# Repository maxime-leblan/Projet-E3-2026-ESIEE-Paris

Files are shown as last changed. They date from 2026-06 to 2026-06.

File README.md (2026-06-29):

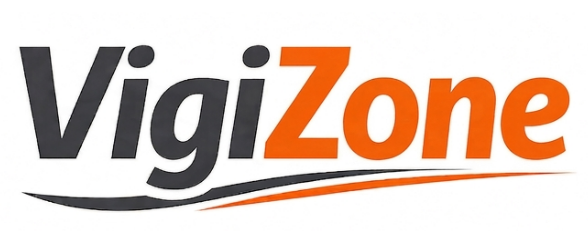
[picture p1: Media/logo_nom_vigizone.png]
Logo du projet VigiZone


# VigiZone : Prévention des collisions engins-piétons sur chantiers

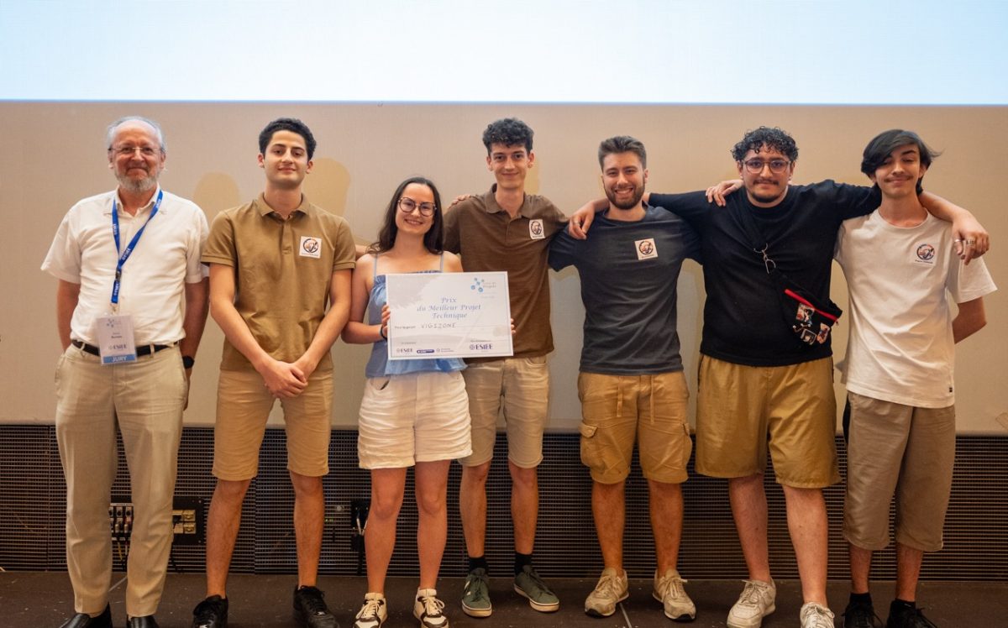
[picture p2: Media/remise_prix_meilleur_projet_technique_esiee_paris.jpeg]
L'équipe VigiZone lors de la remise du prix

*Remise du prix du meilleur projet technique lors du [Jour des Projets](https://jdp.esiee.fr) E3 2026 à ESIEE Paris*

### Membres de l'équipe

Nous étions une équipe de 6 étudiants en 1ère année du cycle ingénieur à ESIEE Paris
*dans l'ordre de droite à gauche :*
* Hugues JOUHAUD
* Naïm BEN-RAÏES
* Benoît DE KEYN
* Maxime LE BLAN
* Clarisse BLONDEL
* Jérémy FOUILLOUX

 Suivis par notre tutrice **Mme Ting WANG**, assistante professeur de robotique à ESIEE PARIS, nous avons reçu le prix du meilleur projet technique de la part du jury technique **M. Denis BUREAU** (tout à gauche sur la photo), professeur d'informatique à ESIEE Paris.

**[Lire le rapport complet du projet VigiZone (PDF)](https://drive.google.com/uc?export=download&id=16rXCA4nlOrGEzkfiPZYJjSept83bqB7f)**

---

## Contexte : Un enjeu de sécurité vital

Le secteur du Bâtiment et des Travaux Publics (BTP) fait face à des risques majeurs concernant la sécurité de ses travailleurs.
* Les collisions entre les engins de chantier et les ouvriers piétons représentent la première cause d'accidents mortels dans ce domaine.
* Selon l'Organisme Professionnel de Prévention du Bâtiment et des Travaux Publics (OPPBTP), on dénombre environ quinze décès par an causés par ces collisions.

Initialement, notre équipe souhaitait développer un dispositif pour les travailleurs isolés. Cependant, des échanges avec Monsieur Luc-Géry Helle, directeur régional génie civil de GTM Ouest (VINCI Construction France), ont mis en lumière une contrainte réglementaire stricte : la législation française interdit ou encadre très fortement le travail isolé sur les chantiers de construction. Le projet a donc été réorienté pour répondre au besoin critique de la prévention des collisions.

---

## Qu'est-ce que VigiZone ?

VigiZone est un système embarqué de détection en temps réel conçu pour éviter les collisions entre les ouvriers et les véhicules de chantier. 

Face à ce danger, les systèmes d'alarme sonores classiques (comme les bips de recul) perdent en efficacité, car les ouvriers s'habituent au bruit ambiant. De leur côté, les solutions basées sur des caméras IA ou des capteurs LiDAR sont extrêmement coûteuses et voient leurs performances chuter dans des conditions difficiles (poussière, boue, faible luminosité). 

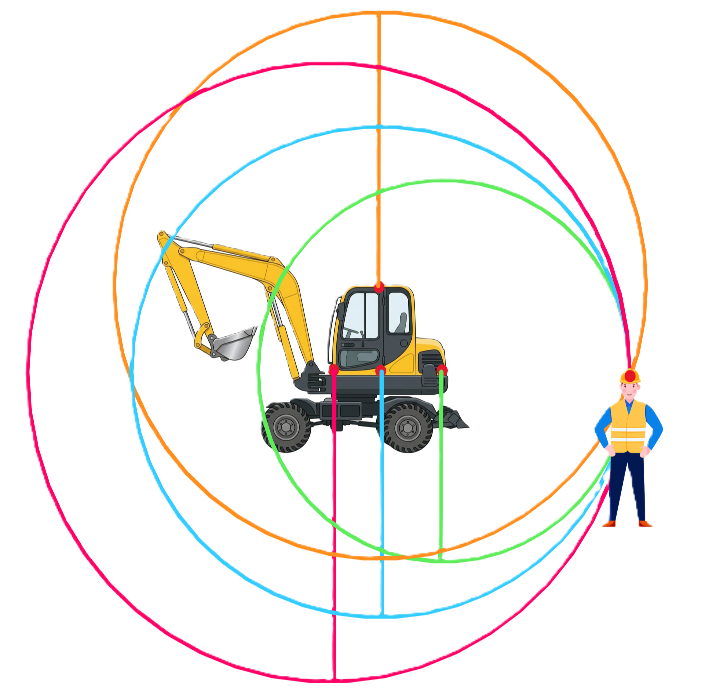
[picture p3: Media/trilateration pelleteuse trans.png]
Schéma de trilatération autour d'une pelleteuse


C'est pourquoi VigiZone s'appuie sur la technologie **Ultra Wide Band (UWB)** :
* L'UWB offre une très haute précision de positionnement en se basant sur le temps de vol du signal.
* C'est un signal robuste capable de bien traverser les obstacles.

---

## Architecture et Utilisation

Le fonctionnement de VigiZone repose sur la communication entre trois sous-systèmes interdépendants :

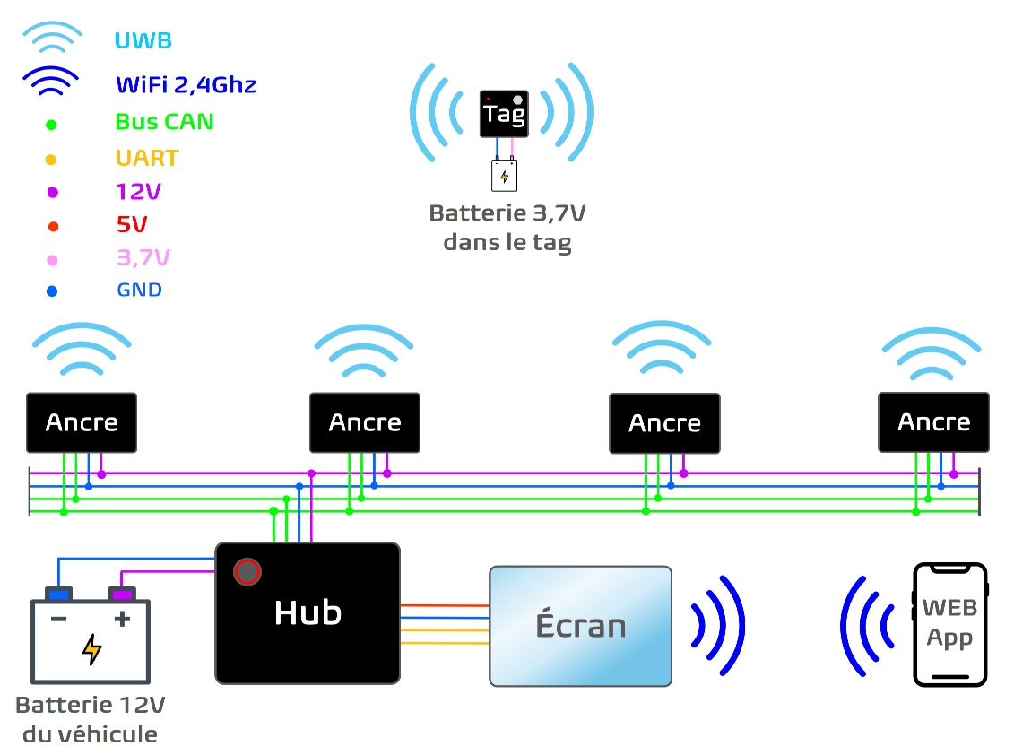
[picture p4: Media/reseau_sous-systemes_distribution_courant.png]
Architecture et distribution du courant


* **Le Hub central (Unité de bord) :** Placé dans la cabine du conducteur et alimenté par la batterie de l'engin, il fusionne les données pour calculer les distances par trilatération. 
  
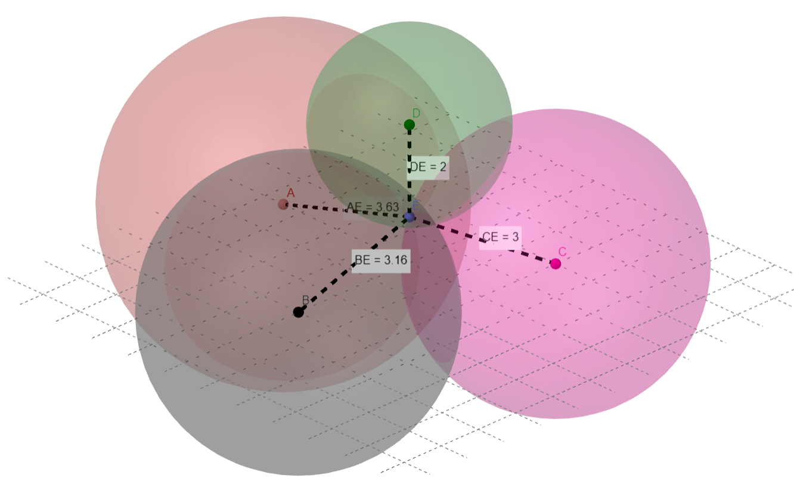
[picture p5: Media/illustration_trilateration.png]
Illustration de la trilatération
  
  
  Il est équipé d'un écran permettant de localiser les ouvriers en direct par rapport à une zone de danger et d'une alarme sonore.

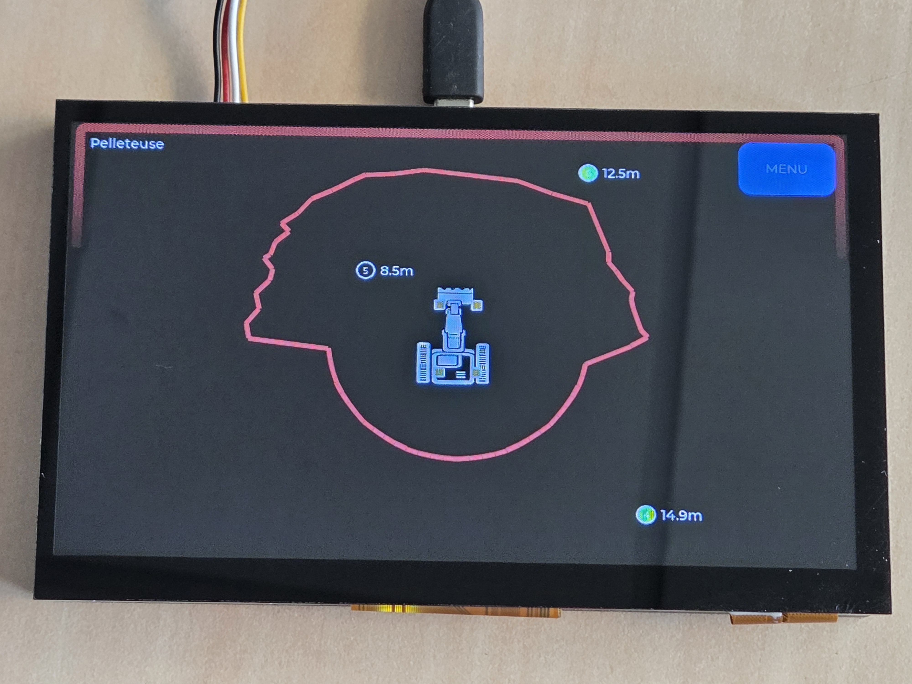
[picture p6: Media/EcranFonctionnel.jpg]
Écran fonctionnel VigiZone
  

* **Les Ancres (Boîtiers véhicule) :** Quatre capteurs disposés sur l'armature de l'engin (par exemple, aimantés) qui servent à localiser les ouvriers.
* **Le Tag (Boîtier ouvrier) :** Un équipement de protection individuelle (EPI) compact porté par l'ouvrier (sur son casque ou à la ceinture). Afin de garantir la sécurité, il ne possède aucun bouton d'arrêt et s'allume automatiquement.

**Scénario d'utilisation :** Si un ouvrier équipé d'un Tag pénètre dans une zone de danger virtuelle délimitée autour de l'engin, le système alerte instantanément les deux parties. Le conducteur est averti par l'écran et une alarme en cabine, tandis que le Tag de l'ouvrier déclenche une alerte sonore suffisamment puissante pour couvrir le bruit du chantier.

---

## Limites et Nuances du Système

Bien que la technologie UWB apporte une grande fiabilité de détection, notre solution technique ne prétend pas résoudre entièrement le problème des accidents. 

Comme nous l'a expliqué Monsieur Mathieu Baré, directeur prévention délégation génie civil Ouest chez VINCI Construction France, lors de notre visite sur le chantier du Grand Paris Express : plusieurs dispositifs de prévention existent, mais chacun possède ses avantages et ses limites selon les situations. À ce jour, aucun système ne permet de supprimer complètement le risque de collision entre engins et piétons. VigiZone doit donc être perçu comme un outil d'assistance et une couche de sécurité supplémentaire, qui vient compléter, mais en aucun cas remplacer, la vigilance indispensable des conducteurs et des ouvriers.

---

## En savoir plus

Pour consulter l'intégralité de notre démarche (choix technologiques, algorithmes de trilatération, conception des cartes sous KiCad et analyse éthique), nous vous invitons à lire notre rapport complet.

**[Lire le rapport complet du projet VigiZone (PDF)](https://drive.google.com/uc?export=download&id=16rXCA4nlOrGEzkfiPZYJjSept83bqB7f)**

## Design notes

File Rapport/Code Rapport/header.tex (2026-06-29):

\usepackage[french]{babel}

% --- Gestion des couleurs ---
\usepackage{xcolor}
% Définition d'un bleu élégant similaire à ton image
\definecolor{TableOfContentColor}{RGB}{0, 51, 153} 

% Gestion du style de certaines parties du texte
\usepackage{titlesec}

% --- Gestion des liens et de la couleur du sommaire ---
\usepackage[
    colorlinks=true,
    linkcolor=TableOfContentColor,    % Colore les titres et numéros de la table des matières
    urlcolor=TableOfContentColor,
    citecolor=TableOfContentColor
]{hyperref}

% Encodage des caractères
\usepackage[utf8]{inputenc}
\usepackage{lmodern}
\usepackage[T1]{fontenc}

%  Gestion de la mise en page et des marges :
\usepackage{geometry}
\geometry{a4paper}

% Pour afficher dans le sommaire jusqu'aux sous-sous-sections (ex: 1.1.1)
\setcounter{tocdepth}{3}
\setcounter{secnumdepth}{3}

% Pour gérer les soulignements qui vont automatiquement à la ligne en cas de débordement de la marge
\usepackage[normalem]{ulem}

%Choix du thème de la police (sans serif, petites capitales dans les titres...) 
\usepackage{amssymb} 
% Des symboles mathématiques
\usepackage{graphicx}
% Pour insérer des images
\usepackage{multicol}
% Pour gérer facilement un environnement à n colonnes
\usepackage{booktabs}
% Pour des beaux tableaux
\usepackage{esvect} 
% Pour de belles flèches sur les vecteurs
\usepackage{esdiff}
% Pour de beaux symboles de dérivation
\usepackage{siunitx}
% Pour l'utilisation des unités du système international
\sisetup{output-decimal-marker={,},inter-unit-product=\ensuremath{{}\cdot{}}}
% Quelques réglages pour l'affichage des unités

% Pour régler les marges de l'article
\usepackage{geometry}
\geometry{hmargin=2cm,vmargin=1.7cm}
% Pour les couleurs
\usepackage{color}
% Pour les indentations
\usepackage{tcolorbox}
\tcbuselibrary{skins, breakable}
\newtcolorbox{indentation}[1][]{
	blanker, left=1cm, borderline west={0.5mm}{0.6cm}{black!50}, breakable,
	before skip=2ex plus 0.1ex, after skip=2ex plus 0.1ex, #1
}

% On force les titres à rester en Noir, avec leur police par défaut (rmfamily), en gras
\titleformat{\section}{\normalfont\Large\bfseries\color{black}}{\thesection}{1em}{}
\titleformat{\subsection}{\normalfont\large\bfseries\color{black}}{\thesubsection}{1em}{}
\titleformat{\subsubsection}{\normalfont\normalsize\bfseries\color{black}}{\thesubsubsection}{1em}{}

% On définit la taille des marges
\geometry{inner=1.25cm, outer=1.25cm, top=2cm, bottom=2cm}

% ---- COMMANDES PERSONNALISEES ----

% Commande pour utiliser une indentation :
% \begin{indentation}
%     <texte>
% \end{indentation}

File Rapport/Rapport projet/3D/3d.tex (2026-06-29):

\subsection{Objectifs et contraintes initiales}

La conception d'une enveloppe physique pour protéger nos cartes électroniques constituait une étape essentielle de notre projet. En effet, nos cartes ne pouvaient pas rester simplement à l'air libre. L'objectif était de créer un boîtier sur mesure, imprimable en 3D, capable d'accueillir notre circuit imprimé tout en l'isolant efficacement des éléments extérieurs tels que la poussière, la pluie ou les gravats, et en laissant un accès aux connectiques.

Cependant, cette phase comportait une contrainte : nous étions dans l'obligation d'attendre la fin de la conception du PCB sous KiCad \cite{KiCad}. En effet, la moindre modification du placement des composants ou des trous de fixation sur la carte avait un impact direct sur la géométrie de notre futur boîtier. Il en allait de même pour la taille et la hauteur des composants, pour lesquelles nous devions consulter les datasheets et effectuer des mesures manuelles précises afin d'obtenir l'espacement le plus optimisé possible.

\subsection{Découverte de l'outil et problématiques de prise en main}

Pour réaliser cette modélisation, nous avons choisi d'utiliser le logiciel Autodesk Fusion 360 \cite{Fusion360}. La modélisation 3D était une étape relativement nouvelle pour nous, car personne n'avait d'expérience préalable dans ce domaine. 
La prise en main du logiciel s'est avérée complexe. Face au peu de tutoriels disponibles pour nous accompagner spécifiquement sur l'intégration d'une carte électronique dans un boîtier imprimable, nous avons procédé par itération. Nous avons donc décidé de réaliser une "boîte test" pour commencer. Ce premier essai nous a permis de comprendre le fonctionnement de l'espace de travail, la gestion de l'historique de conception, et l'utilisation des outils de base tels que les esquisses 2D et les extrusions.

Afin de valider nos dimensions et de confronter notre modèle à la réalité, nous avons procédé à l'impression de ce premier prototype. Cette étape n'a pas été réalisée avec du matériel personnel, mais directement au sein de l'école : nous avons utilisé les imprimantes 3D mises à notre disposition par l'association étudiante ESIEESPACE.

\subsection{Schéma général de conception : La méthode "Top-Down"}
Une fois familiarisés avec Fusion 360 \cite{Fusion360}, nous avons pu mettre en place une méthodologie plus rigoureuse appelée conception "Top-Down". Au lieu de modéliser le boîtier à l'aveugle, nous avons importé le modèle 3D de notre carte électronique (le fichier .STEP généré par KiCad \cite{KiCad}) directement au centre de notre espace de travail. Cette première étape, visible sur la Figure \ref{fig:-photo_carte_fusion360}, nous a permis de disposer d'une base visuelle concrète et à l'échelle pour construire le reste du boîtier.

\begin{figure}[!ht]
\centering 
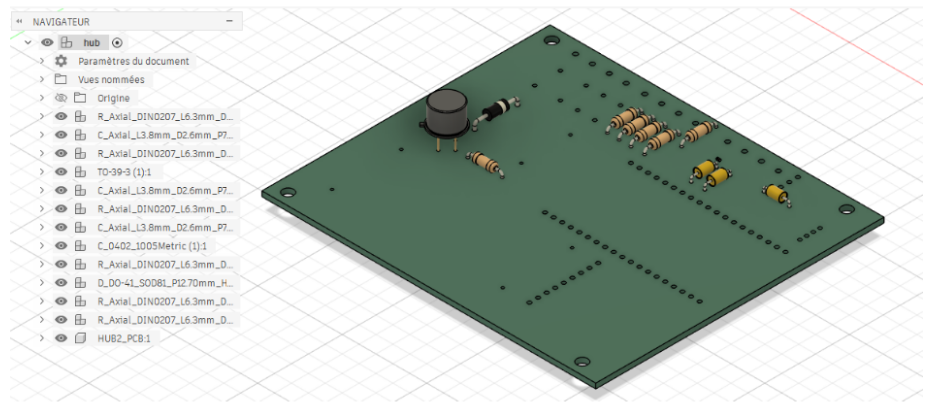
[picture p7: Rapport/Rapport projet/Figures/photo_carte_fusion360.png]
 
\caption[Modèle 3D de la carte électronique importé sous Fusion 360]{Modèle 3D de la carte électronique importé sous Fusion 360}
\label{fig:-photo_carte_fusion360}
\end{figure}

Voici les fonctions clés que nous avons utilisées pour construire le boîtier autour d'elle :

\begin{itemize}
    \item \textbf{L'outil Projeter (Raccourci P) :} Cet outil a été fondamental dans notre conception. Il nous a permis de "calquer" le contour exact de la carte électronique sur le fond ou le couvercle de notre boîtier. Cela nous a permis de garantir que les trous de fixation pour les vis soient positionnés au millimètre près pour l’assemblage et l'impression 3D. La Figure \ref{fig:-photo_projection_fusion360} illustre l'utilisation de cette fonction pour récupérer l'empreinte exacte d'un perçage de la carte vers la face de notre boîtier.
    
    \begin{figure}[!ht]
    \centering 
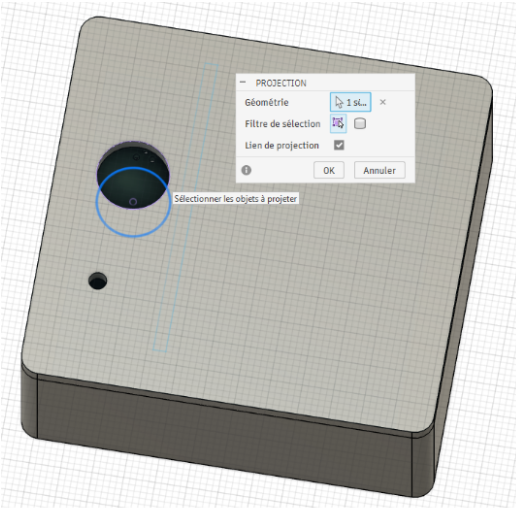
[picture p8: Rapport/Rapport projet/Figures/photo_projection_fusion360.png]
     
    \caption[Utilisation de l'outil Projeter pour définir l'emplacement exact des perçages]{Utilisation de l'outil Projeter pour définir l'emplacement exact des perçages}
    \label{fig:-photo_projection_fusion360}
    \end{figure}
    
    \item \textbf{L'outil Décalage (Offset) :} À partir du contour projeté, nous avons défini l'épaisseur des murs extérieurs. Nous avons opté pour une épaisseur de 2,5 mm. Cette valeur a été choisie en fonction des recherches que nous avons effectuées sur le rechargement sans fil, mais aussi sur les caractéristiques techniques des imprimantes 3D qui étaient à notre disposition. Le résultat de cette modélisation, regroupant les pylônes de fixation creusés, l'emplacement de la carte et les différentes ouvertures sur le couvercle, est présenté sur la Figure \ref{fig:-photo_boitier_fini_fusion360}.
    
    \begin{figure}[!ht]
    \centering 
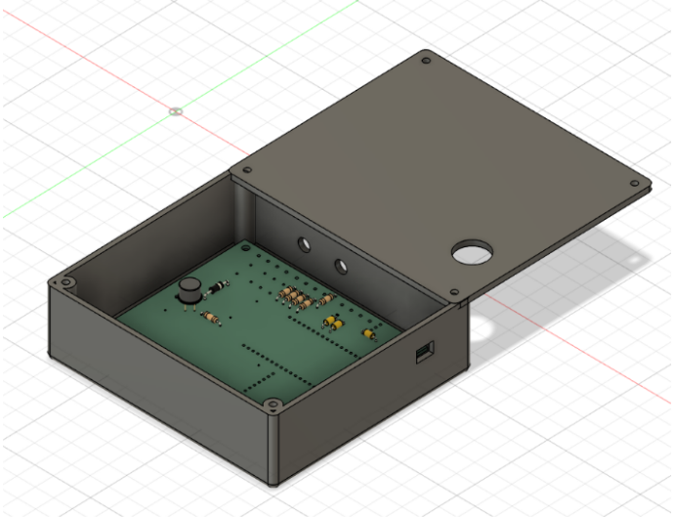
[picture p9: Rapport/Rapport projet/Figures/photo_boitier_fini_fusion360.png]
     
    \caption[Vue d'ensemble du boîtier modélisé avec ses pylônes de fixation et son couvercle démontable]{Vue d'ensemble du boîtier modélisé avec ses pylônes de fixation et son couvercle démontable}
    \label{fig:-photo_boitier_fini_fusion360}
    \end{figure}
    
\end{itemize}
\subsection{Assemblage et système de fermeture}

La problématique majeure de notre modélisation était de concevoir un système permettant de maintenir la carte fermement au fond du boîtier. En effet, nos cartes ne pouvaient pas rester à l'air libre : elles devaient être protégées de l'environnement (pluie, poussière, gravats) et vissées solidement pour ne pas bouger avec les mouvements et les vibrations. Parallèlement, nous devions concevoir un couvercle démontable afin de faciliter la maintenance, ce qui est indispensable pour changer de potentiels câbles ou composants, ou encore pour mettre à jour le firmware.

Pour ce faire, nous avons modélisé des pylônes de fixation directement fusionnés aux quatre coins intérieurs de la boîte. L'outil d’Extrusion a été paramétré sur l'opération "Joindre" pour que ces piliers de 8 mm de diamètre fassent corps avec les murs. Ensuite, nous devions percer ces piliers pour le passage des vis. Nous avons utilisé de nouveau l'outil Extrusion, mais cette fois-ci avec l'opération "Couper", pour vider le centre des pylônes avec un diamètre de 3,2 mm. Ce diamètre correspond aux vis M3 standards que nous avons utilisées.

À la base, nous voulions utiliser des vis en plastique pour la fixation, afin d'éviter tout problème de court-circuit sur les cartes électroniques. Cependant, avec l'équipement à notre disposition, nous ne pouvions pas réaliser les rainures adaptées pour ce type de vis. Nous nous sommes donc rabattus sur des vis métalliques. Il reste néanmoins possible d'ajouter des plots anti-vibration pour sécuriser davantage l'installation. Par ailleurs, une adaptation manuelle a été requise : les PCB fournis par l'école ne comportant pas de trous pour nos vis, nous avons dû mesurer les espacements à la main pour correspondre au fichier KiCad \cite{KiCad}, puis percer les cartes nous-mêmes à l'aide d'une perceuse à colonne.

Ensuite, il a fallu modéliser chaque perçage nécessaire aux interfaces extérieures. Nous avons notamment prévu un trou pour intégrer un bouton en montage panneau, ainsi qu'un emplacement pour une LED. 

Nous avons aussi dû adapter ces conceptions aux conditions d'utilisation finales : par exemple, le boîtier directement manipulé par l'ouvrier ne possède pas de système de fermeture à vis. Une attention particulière a été portée à la membrane : nous avons réalisé un perçage, qui a ensuite été collée avec un joint afin de rendre le boîtier parfaitement hermétique. 

Enfin, avant de lancer la fabrication, nous avons utilisé le logiciel de découpe de Bambu Studio \cite{Bambu_Studio}. Cela nous a permis de visualiser finement nos boîtes couche par couche et de vérifier tous les paramètres avant l'impression 3D. L'interface de préparation et le placement de nos pièces sur le plateau de l'imprimante sont détaillés sur la Figure \ref{fig:-bambu_studio}.

\begin{figure}[!ht]
\centering 
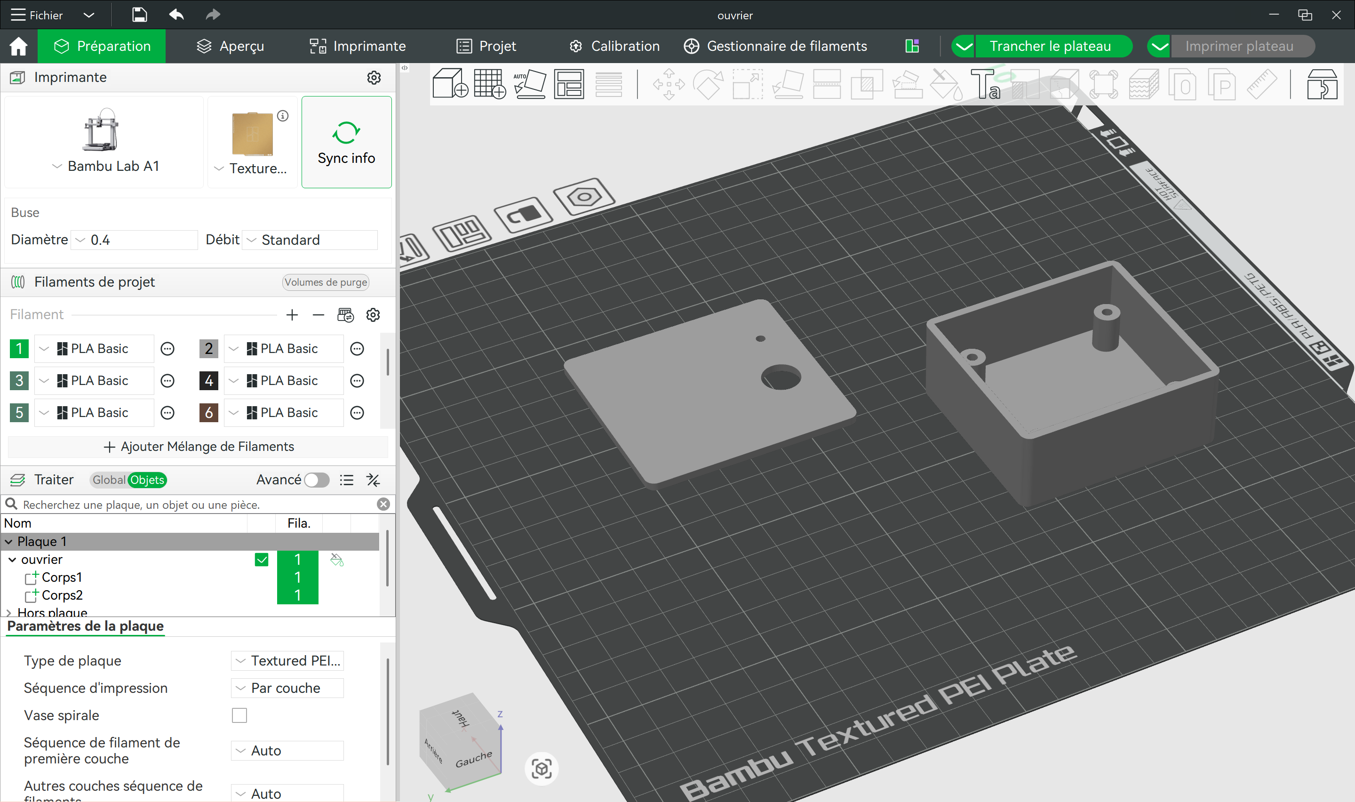
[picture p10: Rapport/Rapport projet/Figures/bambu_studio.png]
 
\caption[Préparation et paramétrage de l'impression 3D sur le logiciel Bambu Studio]{Préparation et paramétrage de l'impression 3D sur le logiciel Bambu Studio}
\label{fig:-bambu_studio}
\end{figure}

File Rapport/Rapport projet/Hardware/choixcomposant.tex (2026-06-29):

% =========================================================================
% SECTION : CHOIX DES COMPOSANTS ET ARCHITECTURE MATÉRIELLE
% =========================================================================

\subsection{Philosophie de Conception et Topologie Globale}

La conception matérielle du système VigiZone a été guidée par un pragmatisme industriel imposé par les délais stricts du projet et les capacités de fabrication disponibles. Le matériel de l'école étant limité pour la gravure de circuits imprimés (PCB) analogiques complexes à micro-pistes, nous avons pris le parti d'éviter les conceptions électroniques de bas niveau. Notre architecture repose donc sur l'intégration de modules pré-assemblés qui gèrent eux-mêmes leur régulation interne, soudés ensuite sur des PCB porteurs personnalisés. Bien que cette approche modulaire induise un encombrement physique légèrement supérieur à celui d'un design dédié, elle garantit une fiabilité analogique sans avoir à passer du temps à faire des calculs, surtout. Cette sécurité électronique nous a permis de concentrer nos efforts sur la validation des algorithmes critiques de sécurité dans le délai imparti de six semaines \cite{Desc_Projet}.

\begin{figure}[H]
    \centering
    
    \caption{Vue d'ensemble simplifiée de la topologie en guirlande du véhicule montrant la distribution du bus d'alimentation 12V et du bus CAN entre le Hub et les 4 Ancres, ainsi que la liaison sans-fil UWB avec l'équipement de l'ouvrier.}
    \label{fig:topo_globale}
\end{figure}

% Jeremy -------------------------------------------------------------------------
% \subsection{Composant Transversal : Transistor de Commutation (NPN 2N2222)}
% 
% Afin de rationaliser l'architecture et de limiter les coûts, les éléments de commutation de puissance partagés entre les différents sous-systèmes ont été standardisés autour du transistor bipolaire NPN 2N2222.
% Ce composant, largement disponible dans les stocks de l'école, offre un gain en courant qui permet de saturer la jonction avec un très faible appel sur la base (via une résistance de 1~k$\Omega$) \cite{2N2222, Desc_Projet}. Cette caractéristique est essentielle pour respecter la limite stricte de tirage des broches GPIO de nos microcontrôleurs, tout en laissant passer la puissance requise pour activer des relais ou des buzzers \cite{XIAO_nRF52840}. Dans l'optique d'une version industrialisée, ce composant imposant une chute de tension intrinsèque ($V_{CE(sat)}$) devrait être remplacé par un transistor MOSFET à état logique (comme le BSS138). Sa résistance interne quasi nulle ($R_{DS(on)}$) permettrait de transmettre la totalité de la tension aux actionneurs \cite{BSS138}.
%
% \begin{figure}[H]
%     \centering
%     \includegraphics[width=0.5\textwidth]{2N222_complete.png}
%     \caption{Vues du transistor de commutation NPN 2N2222.}
%     \label{fig:2n2222_img}
% \end{figure}
% 
% \begin{table}[H]
%     \centering
%     \begin{tabular}{|p{6cm}|p{8cm}|}
%         \hline
%         \textbf{Caractéristique / Fonctionnalité} & \textbf{Spécification} \\
%         \hline
%         Tension Collecteur-Émetteur ($V_{CEO}$) & 40 Vdc \\
%         \hline
%         Courant Collecteur Continu ($I_C$) & 600 mAdc \\
%         \hline
%         Gain en courant DC ($h_{FE}$) & 100 à 300 (à $I_C = 150\text{ mA}$) \\
%         \hline
%         Dissipation totale du dispositif ($P_D$) & 625 mW \\
%         \hline
%         Prix & Fourni par l'ESIEE \\
%         \hline
%     \end{tabular}
%     \caption{Spécifications électriques du transistor NPN P2N2222A \cite{2N2222}.}
%     \label{tab:specs_2n2222}
% \end{table}

\newpage
% -------------------------------------------------------------------------
\subsection{Sous-Système 1 : L'Équipement de Protection Individuelle}

Ce sous-système, destiné à être porté sur le casque de l'employé, est soumis à des contraintes drastiques d'encombrement, de poids et de consommation d'énergie.

\begin{figure}[H]
    \centering
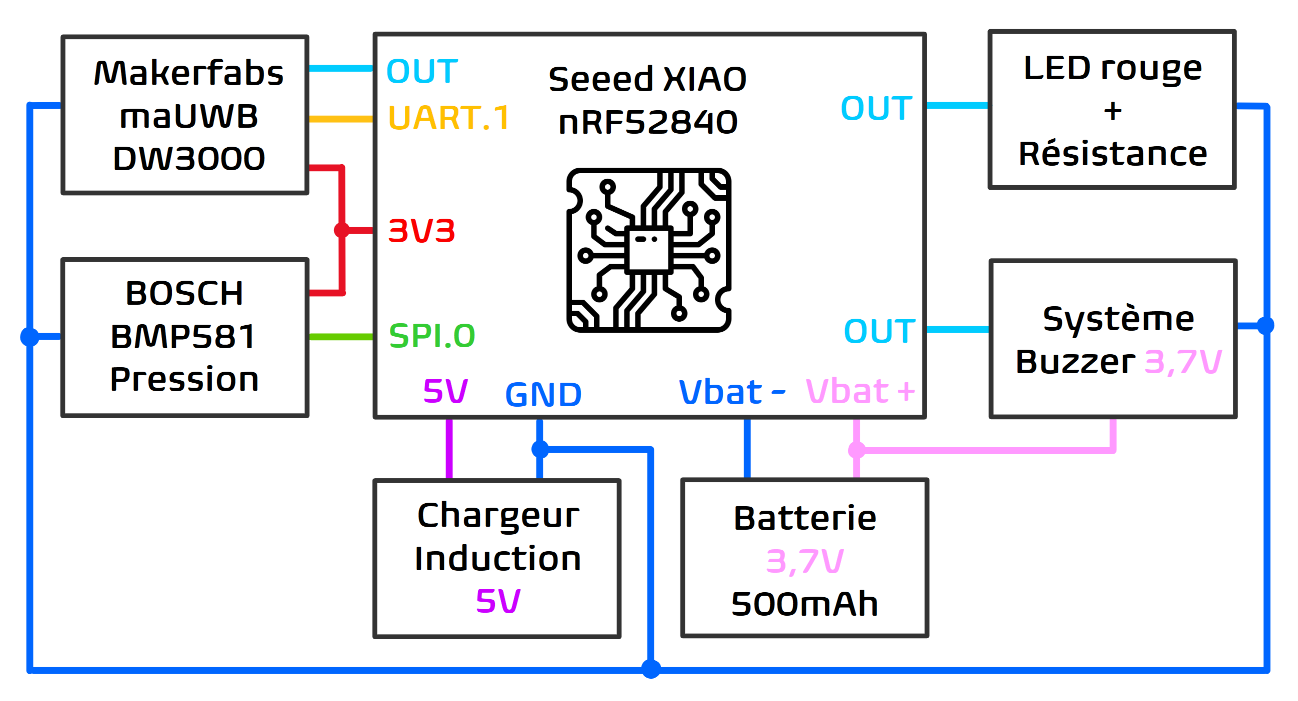
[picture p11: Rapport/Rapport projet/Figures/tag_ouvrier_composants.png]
    
    \caption{Architecture matérielle du dispositif porté par l'employé, centré sur la XIAO nRF52840, intégrant la charge Qi, la télémétrie UWB, l'altimétrie et l'alerte sonore.}
    \label{fig:tag_ouvrier}
\end{figure}

\newpage
\subsubsection{Alimentation et Gestion de l'Énergie}

L'alimentation du dispositif est assurée par une batterie Li-Po de 3.7V offrant une capacité de 500~mAh. Ce dimensionnement vise à offrir le meilleur compromis entre autonomie, poids et encombrement afin de ne pas gêner le port de tête de l'ouvrier sur son casque.

\begin{figure}[H]
    \centering
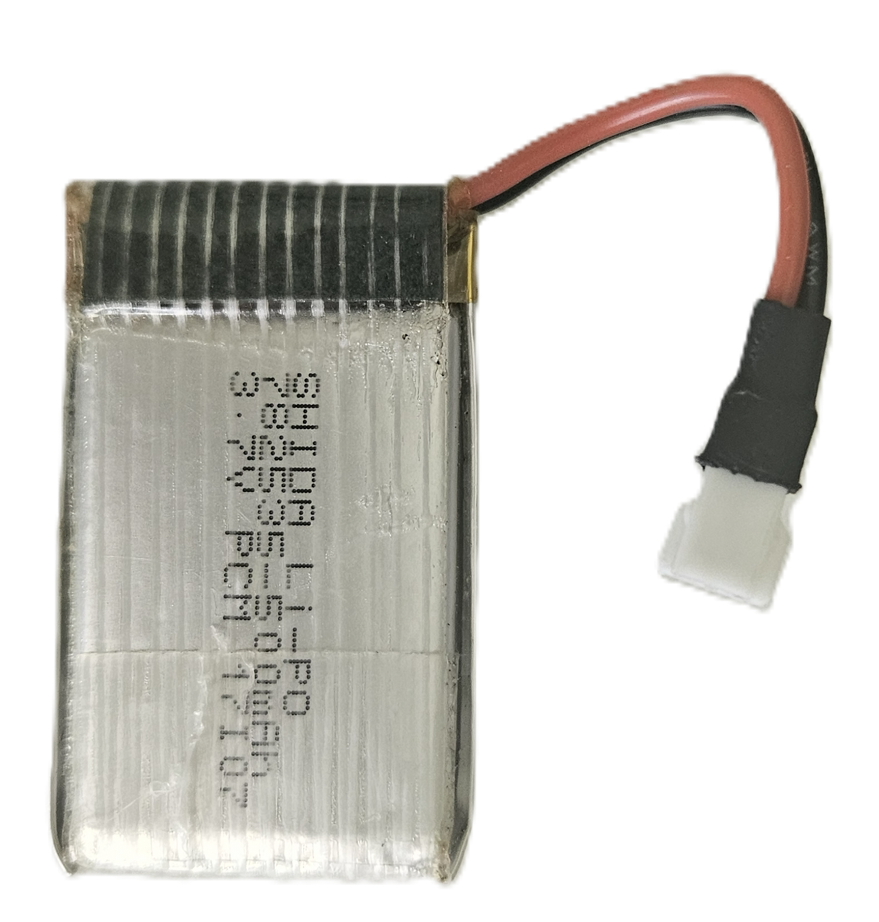
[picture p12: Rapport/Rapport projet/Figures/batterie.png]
    
    \caption{Batterie Li-Po 3.7V 500mAh alimentant le Tag.}
    \label{fig:batterie_img}
\end{figure}

Afin de préserver cette batterie, le tag exploite un algorithme de mise en veille dynamique (\textit{dynamic polling}). Le microcontrôleur s'endort entre deux mesures de distance, la durée de cette veille étant directement proportionnelle à la distance séparant l'ouvrier de la zone de sécurité. Plus l'ouvrier est loin, plus le tag dort longtemps, avec la certitude mathématique de se réveiller et d'être actif avant toute pénétration potentielle dans la zone dangereuse. Ce calcul sécuritaire se base sur la vitesse de course maximale d'un homme, fixée à 15~km/h par précaution.
\bigskip
Cependant, la consommation électrique du prototype matériel actuel reste problématique. En mode actif, l'ensemble consomme 80~mA sous 3.7V. En mode veille, la carte XIAO voit sa consommation chuter de manière exemplaire à 12~mA, mais nous avons découvert que la commande \texttt{AT+Sleep} envoyée au module UWB ne le place pas dans un véritable mode basse consommation. Elle se contente de couper la transmission radio, laissant le module consommer environ 30~mA. Au total, la consommation en veille du système stagne donc à 43~mA.
\bigskip
Avec une batterie de 500~mAh, l'autonomie plafonne ainsi à environ 6,25 heures en mode 100\% actif, et ne dépasserait pas 11,6 heures si le tag restait perpétuellement en mode veille. Ce n'est malheureusement pas suffisant pour couvrir de longues journées sur un chantier.
\bigskip
Pour corriger ce défaut majeur dans une future itération, la solution requise consistera à ajouter un transistor MOSFET permettant de couper physiquement l'alimentation du module UWB lors des phases de sommeil. La consommation totale chuterait alors à $\le 12$~mA (la consommation de la XIAO seule), offrant une autonomie en veille d'au moins une quarantaine d'heures. Le temps de réveil à l'allumage du module UWB (environ 50~ms) serait simplement anticipé et déduit du temps de veille calculé par l'algorithme de \textit{polling}.

\newpage
\subsubsection{Microcontrôleur Autonome (Seeed Studio XIAO nRF52840)}

Le cœur logique du tag est une carte Seeed Studio XIAO nRF52840. Son architecture ARM Cortex-M4F surclasse nettement un ESP32 en matière d'ultra-basse consommation \cite{XIAO_nRF52840}. Cette efficacité est vitale pour exploiter l'algorithme de \textit{dynamic polling} et tenter de garantir l'autonomie requise \cite{Desc_Projet}. La carte intègre nativement un système de gestion de batterie (BMS), simplifiant la recharge de la batterie Li-Po \cite{XIAO_nRF52840}.

\begin{figure}[H]
    \centering
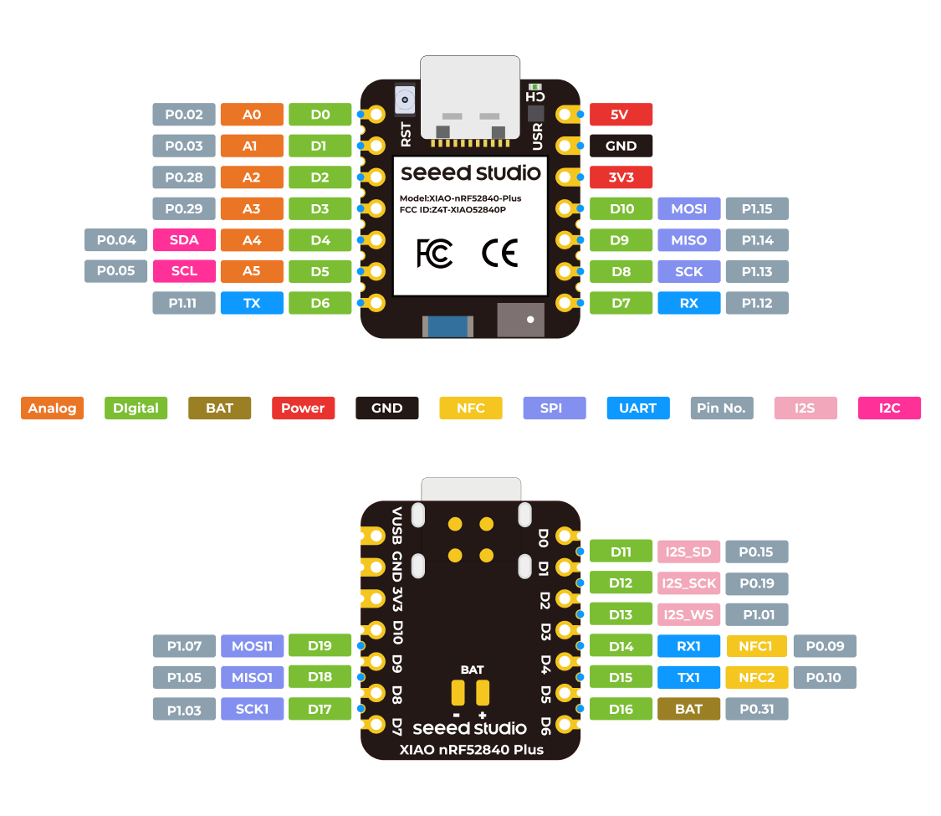
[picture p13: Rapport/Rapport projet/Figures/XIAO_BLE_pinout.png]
    
    \caption{Carte Seeed Studio XIAO nRF52840.}
    \label{fig:xiao_img}
\end{figure}

\begin{table}[H]
    \centering
    \begin{tabular}{|p{6.5cm}|p{7.5cm}|}
        \hline
        \textbf{Caractéristique / Fonctionnalité} & \textbf{Spécification} \\
        \hline
        Environnements de développement & Arduino IDE, PlatformIO, MicroPython, CircuitPython \\
        \hline
        Architecture du processeur & ARM Cortex-M4F \\
        \hline
        Tension logique de fonctionnement & 3.3V \\
        \hline
        Courant de sortie nominal (par broche) & 2 mA \\
        \hline
        Courant de sortie maximal (par broche) & 15 mA \\
        \hline
        Courant de sortie max (toutes broches combinées) & $\approx 200$ mA \\
        \hline
        Consommation en fonctionnement & $\approx 3.3\text{ mA}$ ($52\text{ }\mu\text{A/MHz}$ à $64\text{ MHz}$) \\
        \hline
        Consommation en mode delay() & $1.5\text{ }\mu\text{A}$ à $2.35\text{ }\mu\text{A}$ \\
        \hline
        BMS (Gestionnaire de batterie) intégré & OUI \\
        \hline
        Prix & 14,10 € \\
        \hline
    \end{tabular}
    \caption{Spécifications techniques du microcontrôleur XIAO nRF52840 \cite{XIAO_nRF52840}.}
    \label{tab:specs_xiao}
\end{table}

% \begin{table}[H]
%     \centering
%     \begin{tabular}{|l|l|}
%         \hline
%         \textbf{Broche} & \textbf{Connexion cible} \\
%         \hline
%         BAT+ / BAT- & Batterie Li-Po 3.7V 500mAh \\
%         \hline
%         D1 (P0.03) & Sortie logique pour le Buzzer \\
%         \hline
%         D2 (P0.28) & Sortie logique pour la LED rouge \\
%         \hline
%         D6 (Tx) / D7 (Rx) & UART1 RX / TX du module MaUWB \\
%         \hline
%         D0 (P0.02) & UART2 RX du module MaUWB \\
%         \hline
%         D8 / D9 / D10 & SCK / MISO / MOSI vers le baromètre BMP581 \\
%         \hline
%         D3 / D4 & CSB / INT vers le baromètre BMP581 \\
%         \hline
%         3V3 / GND & Alimentation logique partagée \\
%         \hline
%     \end{tabular}
%     \caption{Brochage complet du microcontrôleur XIAO nRF52840 dans le Tag.}
%     \label{tab:pinout_xiao}
% \end{table}

\subsubsection{Indicateur Visuel (LED Rouge 3mm)}
Afin de communiquer avec l'utilisateur, une LED rouge de 3~mm a été ajoutée pour être insérée dans un trou percé à travers la paroi du tag. Pilotée par le microcontrôleur, elle signale une batterie faible, indique la recharge en cours, et émet un clignotement de maintien en vie (\textit{keep-alive}) confirmant le bon fonctionnement du dispositif.

\subsubsection{Télémétrie Spatiale (Makerfabs MaUWB-DW3000)}

Le choix du composant assurant la technologie UWB a nécessité une longue phase d'évaluation. Initialement, l'utilisation d'une puce Qorvo DW3000 nue avait été envisagée, mais son absence d'antenne intégrée exigeait un design RF hors de notre portée matérielle. Nous nous sommes ensuite tournés vers le module BU03 (Ai-Thinker) qui intègre une antenne. Cependant, l'utilisation de ce module nécessitait de mesurer le temps de vol directement via le bus SPI et d'être codé à partir de peu de ressources disponibles : les exemples d'utilisation trouvés se limitaient exclusivement à la mesure de distance entre deux modules uniques, ce qui était insuffisant pour notre architecture complexe.

Notre choix final s'est donc porté sur le module MaUWB de Makerfabs. Sa véritable valeur ajoutée réside dans l'intégration d'un microcontrôleur STM32 programmé avec un firmware propriétaire et avec un amplificateur pour l'antenne intégré. Le tout est encapsulé sous une plaque métallique de blindage, à l'exception de l'antenne. Ce système encapsule absolument toute la partie détection et la gestion multi-tags/multi-ancres \cite{UWB-AT-Module}. Ce qui nous a permis de partir sur une base fiable et prête en main pour le logiciel en charge de mesurer les distances.

\begin{figure}[H]
    \centering
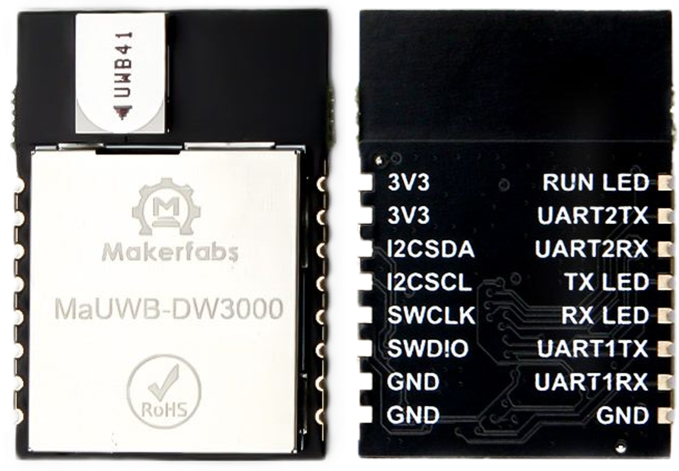
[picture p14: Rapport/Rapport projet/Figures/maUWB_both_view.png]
    
    \caption{Vues du module UWB Makerfabs MaUWB-DW3000.}
    \label{fig:mauwb_img}
\end{figure}

\begin{table}[H]
    \centering
    \begin{tabular}{|p{6.5cm}|p{7.5cm}|}
        \hline
        \textbf{Caractéristique / Fonctionnalité} & \textbf{Spécification} \\
        \hline
        Puce RF Intégrée & Decawave DW3000 \\
        \hline
        Microcontrôleur hôte embarqué & STM32 (Firmware propriétaire Makerfabs) \\
        \hline
        Protocole de communication & UART \\
        \hline
        Mode de pilotage & Commandes AT (Texte) \\
        \hline
        Antenne intégrée & OUI (Omnidirectionnelle) \\
        \hline
        Amplificateur de signal intégré & OUI \\
        \hline
        Prix & 75,50 € \\
        \hline
    \end{tabular}
    \caption{Spécifications techniques du module Makerfabs MaUWB-DW3000 \cite{UWB-AT-Module}.}
    \label{tab:specs_mauwb}
\end{table}

\begin{table}[H]
    \centering
    \begin{tabular}{|l|l|}
        \hline
        \textbf{Broche} & \textbf{Connexion XIAO} \\
        \hline
        3V3 & Bus 3V3 \\
        \hline
        GND & Masse commune \\
        \hline
        UART1 TX & D7 Rx (P1.12) \\
        \hline
        UART1 RX & D6 Tx(P1.11) \\
        \hline
        UART2 RX & D0 (P0.02) \\
        \hline
        Autres & Non connecté \\
        \hline
    \end{tabular}
    \caption{Brochage du module MaUWB-DW3000 dans le Tag ouvrier.}
    \label{tab:pinout_mauwb}
\end{table}

\textbf{Note sur le câblage :} La broche \texttt{UART2 RX} est connectée au GPIO \texttt{D0} de la carte XIAO. Elle sert à faire un reset matériel du module si elle est maintenue à l'état bas pendant trois secondes, et permet également de le sortir de son mode veille (\textit{sleep mode}).

\subsubsection{Altimétrie Barométrique (Bosch BMP581)}

Indépendant du système UWB, l'axe vertical est verrouillé par un capteur de pression Bosch BMP581 \cite{BMP581}. Ce capteur intègre une nouvelle technologie développée par Bosch permettant d'effectuer un sur-échantillonnage (\textit{oversampling}) matériel paramétrable via l'écriture de registres spécifiques. De plus, la puce effectue en interne une mesure précise de la température afin de compenser les dérives et d'améliorer considérablement la précision finale \cite{BMP581}. Son bruit extrêmement faible ($< 0.001\text{ hPa}$) permet d'obtenir une précision relative suffisante pour détecter des variations de pression infimes, traduisibles par une estimation de l'altitude fiable à une dizaine de centimètres près \cite{BMP581}.

\begin{figure}[H]
    \centering
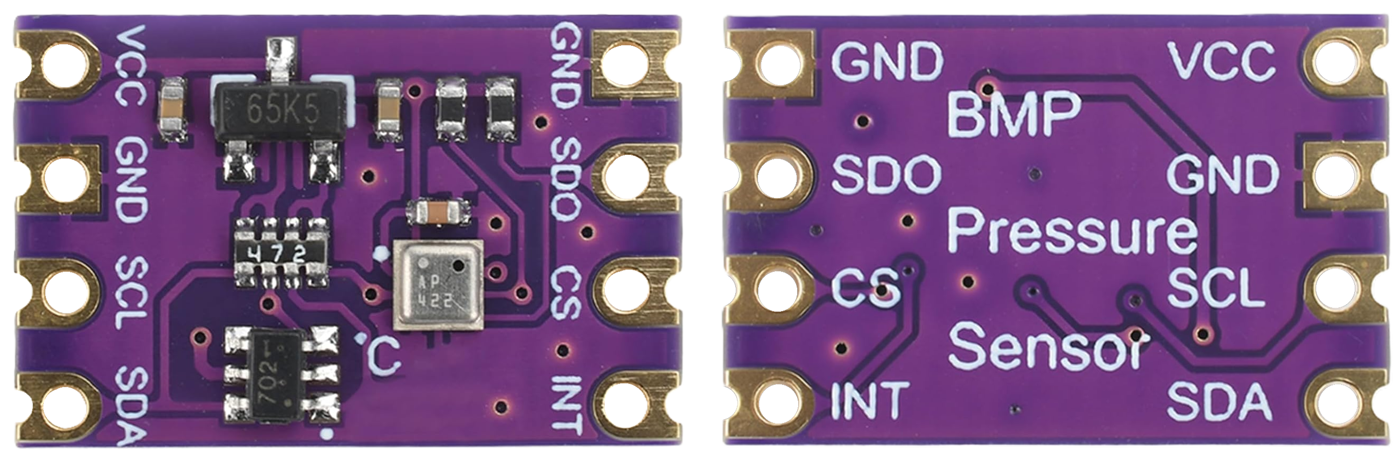
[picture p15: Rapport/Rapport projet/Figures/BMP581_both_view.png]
    
    \caption{Vues du module barométrique Bosch BMP581.}
    \label{fig:bmp581_img}
\end{figure}

\begin{table}[H]
    \centering
    \begin{tabular}{|p{6.5cm}|p{7.5cm}|}
        \hline
        \textbf{Caractéristique / Fonctionnalité} & \textbf{Spécification} \\
        \hline
        Plage de tension d'alimentation (VDD) & 1.71 V à 3.6 V \\
        \hline
        Consommation (Haute résolution, 30 Hz) & 75 $\mu$A à 80 $\mu$A \\
        \hline
        Protocoles de communication & I2C ou SPI \\
        \hline
        Précision de mesure relative & $\pm 0.06\text{ hPa}$ ($\approx \pm 50\text{ cm}$ sur intervalle de 10m) \\
        \hline
        Bruit RMS (sans filtre passe-bas) & $< 0.1\text{ Pa}$ \\
        \hline
        Capteur de température compensatoire & OUI \\
        \hline
        Sur-échantillonnage matériel (Oversampling) & OUI (Configurable via registres) \\
        \hline
        Filtre passe-bas (IIR) embarqué & OUI \\
        \hline
        Prix & 4,50 € \\
        \hline
    \end{tabular}
    \caption{Spécifications techniques du baromètre Bosch BMP581 \cite{BMP581}.}
    \label{tab:specs_bmp581}
\end{table}

\begin{table}[H]
    \centering
    \begin{tabular}{|l|l|}
        \hline
        \textbf{Broche} & \textbf{Connexion XIAO} \\
        \hline
        VCC & Bus 3V3 \\
        \hline
        GND & Masse commune \\
        \hline
        SCL (SCK) & D8 SCK (P1.13) \\
        \hline
        SDA (MOSI) & D10 MOSI (P1.15) \\
        \hline
        SDO (MISO) & D9 MISO (P1.14) \\
        \hline
        CS (CSB) & D3 (P0.29) \\
        \hline
        INT & D4 (P0.04) \\
        \hline
    \end{tabular}
    \caption{Brochage du baromètre BMP581 utilisé en mode SPI dans le Tag.}
    \label{tab:pinout_bmp581}
\end{table}

\subsubsection{Étanchéité et Recharge}

\textbf{Le Récepteur de Charge Sans Fil (Qi Adafruit)}

Les environnements de chantier imposant une forte présence de poussière et d'eau, l'utilisation d'un port USB traversant a été formellement rejetée. La recharge s'effectue par induction via un récepteur Qi Adafruit 1901. Ce module génère son propre 5V régulé et permet de recharger le tag à travers une coque parfaitement scellée, en utilisant des chargeurs sans fil standards (conçus pour les smartphones, par exemple) \cite{Adafruit_1901}. Pour une version industrielle, l'amélioration idéale consisterait à déployer un bac de chargement global sur le chantier : l'ouvrier n'aurait plus à aligner précisément son tag sur une base individuelle, mais se contenterait de le déposer dans le bac en fin de poste.

\begin{figure}[H]
    \centering
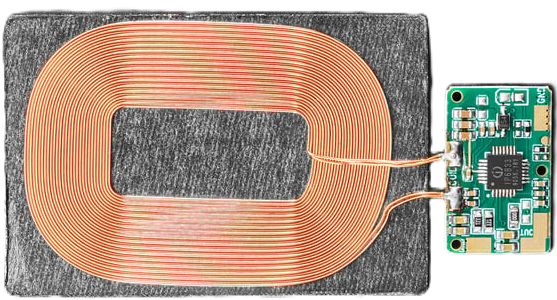
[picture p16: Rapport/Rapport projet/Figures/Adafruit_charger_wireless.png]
    
    \caption{Module récepteur de charge sans fil Adafruit 1901.}
    \label{fig:adafruit_img}
\end{figure}

\begin{table}[H]
    \centering
    \begin{tabular}{|p{6cm}|p{8cm}|}
        \hline
        \textbf{Caractéristique / Fonctionnalité} & \textbf{Spécification} \\
        \hline
        Tension de sortie régulée & 5V (Typique) / 5.2V (Maximum) \\
        \hline
        Courant de sortie maximum & 1 A \\
        \hline
        Efficacité de transfert d'énergie & $\approx 71\%$ (Max) \\
        \hline
        Compatibilité norme standard QI & OUI \\
        \hline
        Régulateur de tension intégré & OUI \\
        \hline
        Prix & 12,76 € \\
        \hline
    \end{tabular}
    \caption{Spécifications du récepteur de charge sans fil Adafruit 1901 \cite{Adafruit_1901}.}
    \label{tab:specs_adafruit1901}
\end{table}

\bigskip
\textbf{La Membrane ePTFE (Amphenol LTW)}

La seule perméabilité volontaire du boîtier est assurée par une membrane ePTFE Amphenol LTW (d'un coût de 2,06 €). Celle-ci garantit une étanchéité totale aux liquides tout en laissant l'air s'équilibrer lentement pour le capteur de pression. Outre son rôle contre l'humidité, cette membrane agit comme un filtre mécanique indispensable pour lisser les chocs de pression soudains liés aux rafales de vent ou aux mouvements brusques de l'ouvrier, qui viendraient inévitablement fausser le calcul altimétrique du baromètre \cite{Desc_Projet}.

\begin{figure}[H]
    \centering
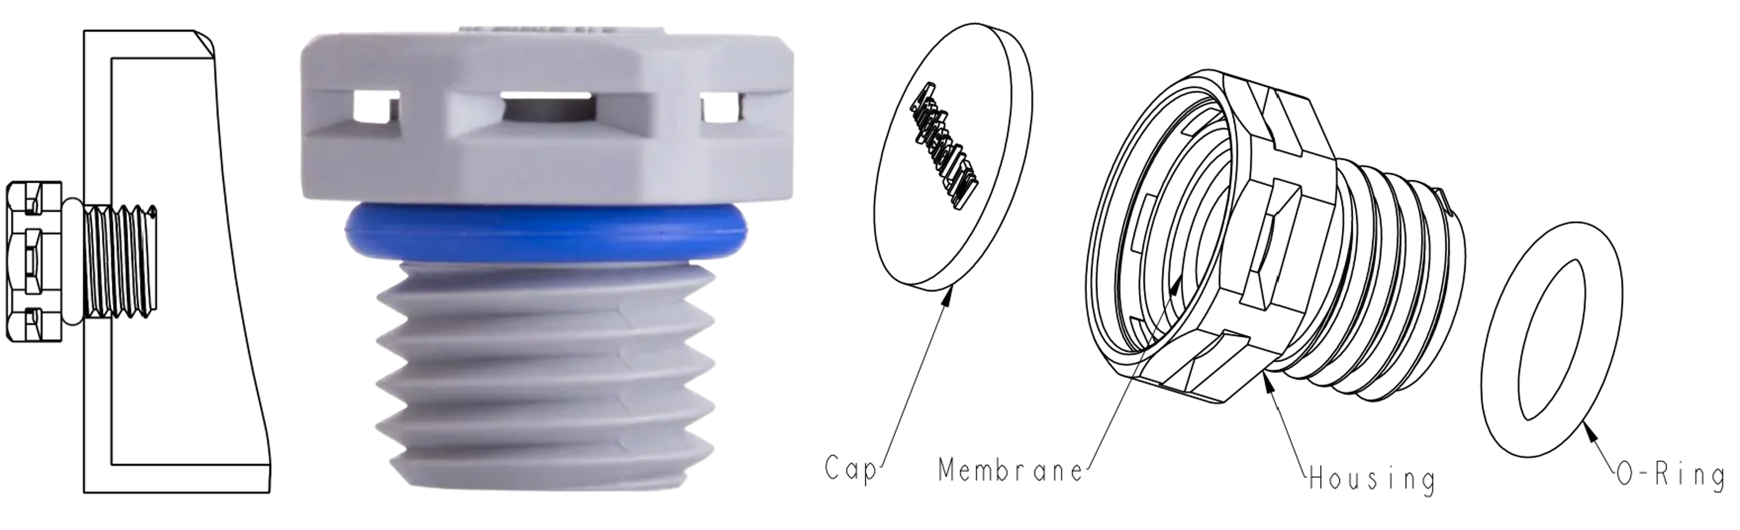
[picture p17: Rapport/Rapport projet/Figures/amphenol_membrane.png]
    
    \caption{Membrane ePTFE Amphenol LTW (issu de la datasheet)}
    \label{fig:membrane_img}
\end{figure}

\newpage
\subsubsection{Avertisseur Sonore (Buzzer)}

L'alerte sonore de l'ouvrier est actuellement gérée par un buzzer magnétique de la marque Same Sky. Pris de court par le temps lors de la conception du prototype, nous avons sélectionné un composant capable d'émettre au moins 85~dB et tolérant une alimentation directe en 3.7V \cite{CMT-8504-100-SMT-TR}. Nous nous sommes rapidement rendu compte que ce choix n'était pas assez puissant pour un environnement industriel bruyant et qu'il consommait excessivement par rapport à un dispositif piézoélectrique. Le composant idéal s'avère être un disque piézoélectrique, qui consommerait dix fois moins d'énergie. Notre objectif acoustique étant d'abaisser la fréquence au maximum pour rendre le son moins strident, plus audible et moins sujet à l'atténuation dans l'air, nous envisagerions un disque exploitant le diamètre maximum raisonnable pour notre boîtier (soit 3~cm). Une telle dimension permettrait d'atteindre une fréquence de résonance optimale d'environ 2500~Hz.

\begin{figure}[H]
    \centering
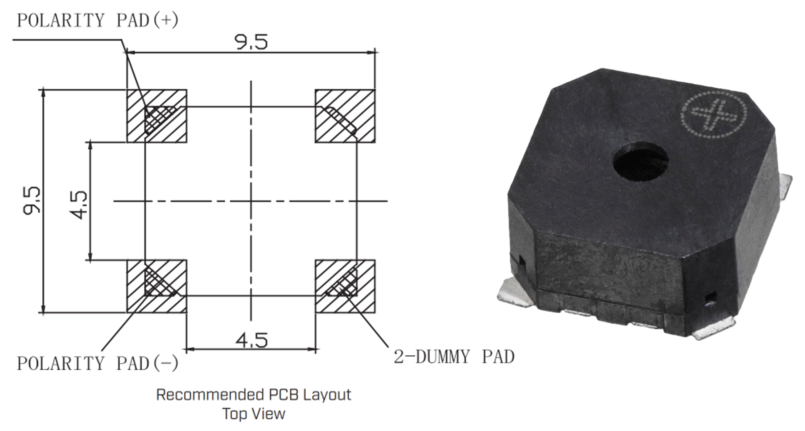
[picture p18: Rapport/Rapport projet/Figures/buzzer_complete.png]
    
    \caption{Avertisseur sonore magnétique Same Sky.}
    \label{fig:buzzer_img}
\end{figure}

\begin{table}[H]
    \centering
    \begin{tabular}{|p{6cm}|p{8cm}|}
        \hline
        \textbf{Caractéristique / Fonctionnalité} & \textbf{Spécification} \\
        \hline
        Tension de fonctionnement & 1.0 V à 6.0 V (Nominale : 5.0 V) \\
        \hline
        Consommation de courant & Nominale: 150 mA / Maximale: 200 mA \\
        \hline
        Volume sonore & 100 dB (à une fréquence de 4000 Hz) \\
        \hline
        Piézoélectrique & NON (Composant magnétique) \\
        \hline
        Prix & 1,37 € \\
        \hline
    \end{tabular}
    \caption{Spécifications de l'avertisseur sonore Same Sky \cite{CMT-8504-100-SMT-TR}.}
    \label{tab:specs_buzzer}
\end{table}

% Jeremy
% \begin{table}[H]
%     \centering
%     \begin{tabular}{|l|l|}
%         \hline
%         \textbf{Broche} & \textbf{Broche cible / Composant cible} \\
%         \hline
%         Borne (+) & Bus +12V (Hub) ou PAD BAT+ en 3.7V (Tag) \\
%         \hline
%         Borne (-) & Collecteur (C) (Transistor 2N2222) \\
%         \hline
%         \multicolumn{2}{|c|}{\textit{Diode de roue libre FR107 montée en antiparallèle}} \\
%         \hline
%         Anode (Sans trait) & Borne (-) du Buzzer \\
%         \hline
%         Cathode (Avec trait) & Borne (+) du Buzzer \\
%         \hline
%     \end{tabular}
%     \caption{Brochage standardisé de l'avertisseur sonore et de sa diode de protection.}
%     \label{tab:pinout_buzzer}
% \end{table}
% 
% \textbf{Note sur le câblage de protection :} Une diode de roue libre (FR107) est montée en antiparallèle directement sur les bornes du buzzer. L'anode est connectée à la Borne (-) et la cathode à la Borne (+). Ce câblage est indispensable pour court-circuiter l'énergie résiduelle de la bobine du buzzer et éviter que le transistor 2N2222 ne grille à l'ouverture du circuit.
%
% \begin{figure}[H]
%     \centering
%     \includegraphics[width=0.8\textwidth]{systeme_buzzer.png}
%     \caption{Circuit standard de commutation d'un actionneur inductif par transistor NPN, incluant la diode de roue libre de protection.}
%     \label{fig:systeme_buzzer}
% \end{figure}

\newpage
% -------------------------------------------------------------------------
\subsection{Sous-Système 2 : Le Hub Central du véhicule}

Situé dans la cabine de l'engin, le Hub centralise les données du réseau périphérique, calcule les distances et interagit avec le conducteur \cite{Desc_Projet}.

\begin{figure}[H]
    \centering
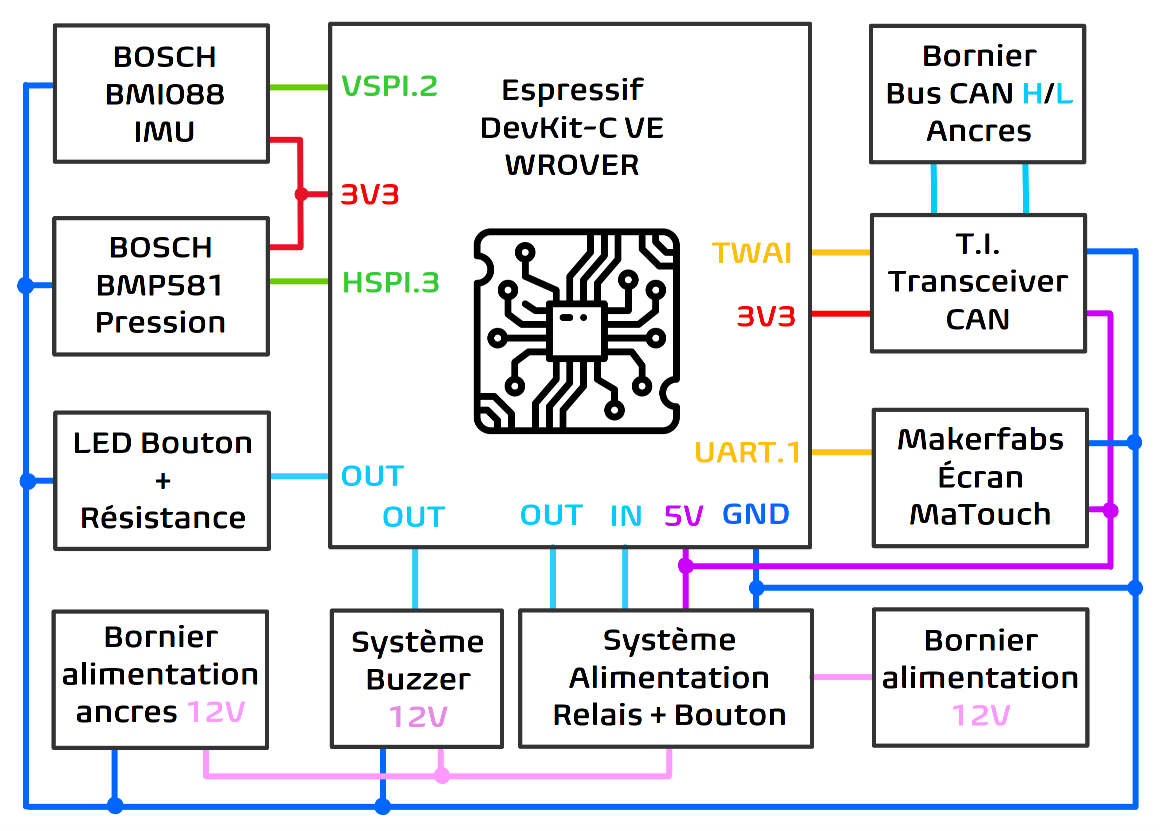
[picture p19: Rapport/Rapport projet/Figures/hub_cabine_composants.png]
    
    \caption{Organisation interne de l'unité de traitement centrale, mettant en évidence la répartition des bus de communication (UART, SPI, CAN) et le partage des tâches avec l'écran MaTouch.}
    \label{fig:hub_cabine}
\end{figure}

\subsubsection{Interface Graphique et Enregistreur (MaTouch 7" ESP32-S3)}

Initialement, nous avions l'intention d'utiliser un simple écran piloté par le hub directement. Nous avons rapidement réalisé que le traitement du flux vidéo exigeait une puissance de calcul colossale et imposait une communication SPI à haut débit mobilisant de multiples câbles pour garantir une résolution acceptable. Or, le WROVER devait déjà dédier ses deux blocs SPI matériels aux capteurs critiques, et nous ne disposions plus d'assez de broches. Voulant à tout prix conserver un faisceau de câblage restreint (deux fils pour les données et deux fils pour l'alimentation), nous avons pivoté vers un écran 7 pouces intégrant son propre processeur ESP32-S3 \cite{MaTouch_7}.

Le protocole I2C étant incapable de couvrir de longues distances de manière fiable, et le SPI exigeant trop de fils, nous avons logiquement choisi l'UART pour assurer la communication asynchrone entre le Hub et l'écran. L'écran embarque également un lecteur de carte SD faisant office de boîte noire pour stocker les journaux du système. Cela permet de s'assurer du bon fonctionnement en cours d'utilisation, et de pouvoir vérifier si le système s'est bien déclenché en cas d'accident, fournissant d'éventuelles preuves pour des avocats \cite{MaTouch_7}. Par ailleurs, l'intégration d'une puce radio sur cet écran nous a permis de développer une application web en Wi-Fi local (WebApp) utilisable avec un smartphone. Cela facilite grandement l'étalonnage lorsqu'on doit faire le tour du véhicule pour tester le système, ainsi que l'importation de nouvelles images pour définir une nouvelle zone de sécurité.

\begin{figure}[H]
    \centering
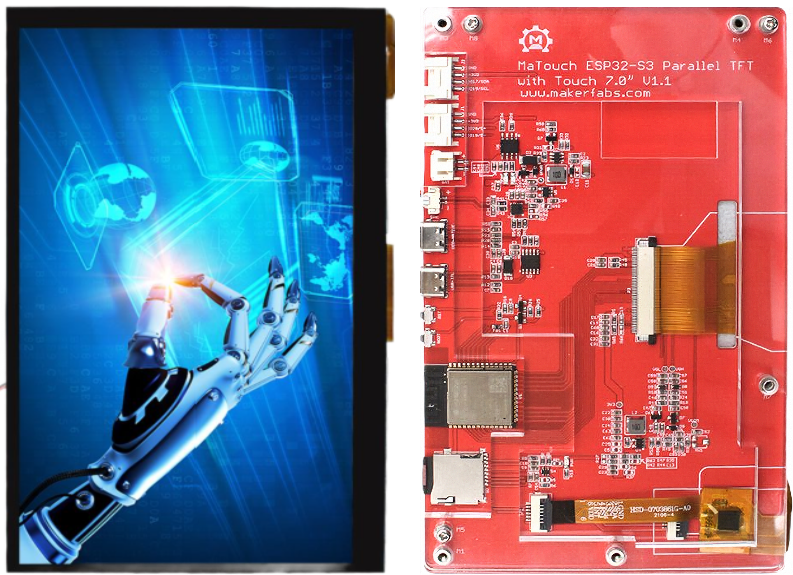
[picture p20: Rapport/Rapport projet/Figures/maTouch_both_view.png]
    
    \caption{Écran autonome Makerfabs MaTouch 7".}
    \label{fig:matouch_img}
\end{figure}

\begin{table}[H]
    \centering
    \begin{tabular}{|p{6cm}|p{8cm}|}
        \hline
        \textbf{Caractéristique / Fonctionnalité} & \textbf{Spécification} \\
        \hline
        Microcontrôleur intégré & ESP32-S3 (8MB PSRAM) \\
        \hline
        Connectivité radio & Wi-Fi et Bluetooth 5 \\
        \hline
        Type d'affichage & Écran tactile IPS 7 pouces \\
        \hline
        Interface de l'afficheur & Interface parallèle (plus rapide que SPI) \\
        \hline
        Stockage matériel & Support et carte microSD 16 GB inclus \\
        \hline
        Connectique & 1x USB-C UART, 1x USB-C Natif, 2x ports Grove \\
        \hline
        Prix & 55,10 € \\
        \hline
    \end{tabular}
    \caption{Spécifications de l'écran autonome Makerfabs MaTouch 7" \cite{MaTouch_7}.}
    \label{tab:specs_matouch}
\end{table}

\begin{table}[H]
    \centering
    \begin{tabular}{|l|l|}
        \hline
        \textbf{Broche (connecteur Grove modifié)} & \textbf{ESP32-WROVER} \\
        \hline
        USB-C 5V & Bus 5V \\
        \hline
        Bus GND & Masse Commune \\
        \hline
        GPIO 19 (en Tx) & GPIO 32 (en RX) \\
        \hline
        GPIO 20 (en Rx) & GPIO 33 (en TX) \\
        \hline
    \end{tabular}
    \caption{Connexions de l'écran autonome MaTouch 7" vers le Hub \cite{MaTouch_7}.}
    \label{tab:pinout_matouch}
\end{table}

\subsubsection{Unité de Traitement Temps Réel (ESP32 WROVER DevKit-C)}

Le traitement mathématique est confié à un ESP32 WROVER dont l'architecture double-cœur est exploitée rigoureusement \cite{ESP32_WROVER}. Le Cœur 0, habituellement dédié au Wi-Fi et au Bluetooth (inutilisés ici), est entièrement réaffecté aux tâches temporelles. La lecture des capteurs, l'exécution du filtre de Madgwick, les calculs de calibration de l'IMU et de la pression, ainsi que l'écriture du Mutex ne prennent que 90~$\mu$s sur un cycle de 2.5~ms (soit 400~Hz). Cette optimisation libère 96\% de la charge de ce cœur pour la gestion fluide des paquets CAN et UART. Le Cœur 1 est ainsi réservé pour l'exécution ininterrompue des algorithmes mathématiques et de l'arbre décisionnel.

\begin{figure}[H]
    \centering
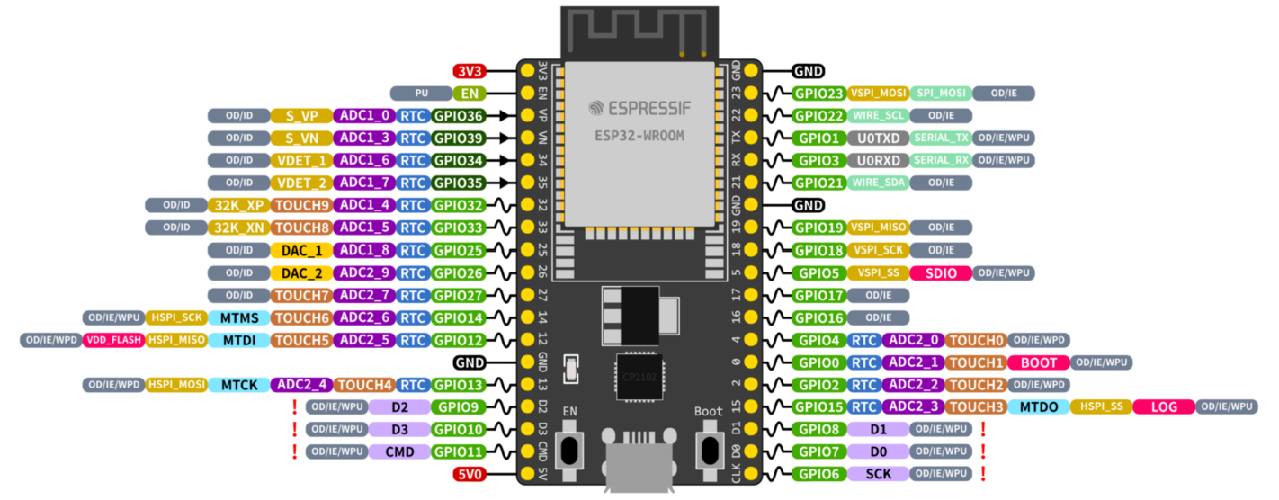
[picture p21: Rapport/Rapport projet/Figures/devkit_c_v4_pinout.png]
    
    \caption{Carte de développement ESP32 WROVER.}
    \label{fig:wrover_img}
\end{figure}

\begin{table}[H]
    \centering
    \begin{tabular}{|p{6cm}|p{8cm}|}
        \hline
        \textbf{Caractéristique / Fonctionnalité} & \textbf{Spécification} \\
        \hline
        Architecture du processeur & Tensilica Dual-Core 32-bit (240 MHz) \\
        \hline
        Connectivité Radio & Wi-Fi et Bluetooth (BR/EDR/BLE) \\
        \hline
        Courant de sortie (par broche) & nominal 12 mA / maximal 40mA \\
        \hline
        Courant de sortie toutes broches combinées & maximum 1200 mA \\
        \hline
        Consommation en fonctionnement & $\approx 80\text{ mA}$ à $240\text{ mA}$ (selon activité RF) \\
        \hline
        Blocs matériels UART / SPI / TWAI & 3 / 4 / 1 \\
        \hline
        Mémoire SRAM interne & 520 KB \\
        \hline
        Prix & 9,46 € \\
        \hline
    \end{tabular}
    \caption{Spécifications techniques du microcontrôleur ESP32 WROVER \cite{ESP32_WROVER}.}
    \label{tab:specs_wrover}
\end{table}

% \begin{table}[H]
%     \centering
%     \begin{tabular}{|l|l|}
%         \hline
%         \textbf{Broche} & \textbf{Broche cible / Composant cible} \\
%         \hline
%         GPIO 25 (TX) / 34 (RX) & Transceiver TCAN1051 (CAN) \\
%         \hline
%         GPIO 18 / 19 / 23 & VSPI (SCLK / MISO / MOSI) vers BMI088 \\
%         \hline
%         GPIO 14 / 13 / 27 & HSPI remappé (SCL / SDA / SDO) vers BMP581 \\
%         \hline
%         GPIO 5 / 21 & CSB / INT vers BMP581 \\
%         \hline
%         GPIO 26 / 22 & CSB1 (accél.) / CSB2 (gyro.) vers BMI088 \\
%         \hline
%         GPIO 39 / 36 & INT1 / INT3 vers BMI088 \\
%         \hline
%         GPIO 2 & Sortie Logique (Maintien Relais via 2N2222) \\
%         \hline
%         GPIO 35 & Entrée Analogique (Lecture état Bouton Poussoir) \\
%         \hline
%         GPIO 4 & Sortie Logique (Déclenchement Buzzer via 2N2222) \\
%         \hline
%     \end{tabular}
%     \caption{Brochage complet de l'ESP32 WROVER pour la gestion des bus et périphériques \cite{ESP32_WROVER}.}
%     \label{tab:pinout_wrover}
% \end{table}

\newpage
\subsubsection{Référentiel Altimétrique (Bosch BMP581)}

Le Hub embarque son propre baromètre BMP581, rigoureusement identique à celui du tag ouvrier (dont les caractéristiques de bruit et de précision ont été détaillées précédemment) pour garantir la symétrie des mesures différentielles \cite{BMP581}. Au sein du WROVER, l'interfaçage de ce capteur a nécessité un remappage logiciel du bus HSPI vers de nouvelles broches GPIO. Cette modification a été imposée par des contraintes matérielles liées à la séquence de démarrage de l'ESP32 (\textit{strapping boot}), car le bus HSPI natif monopolise la broche GPIO12, dont l'état au démarrage dicte la tension interne de la mémoire flash. Y connecter un capteur SPI aurait risqué de perturber ou d'empêcher le démarrage du microcontrôleur.

\begin{figure}[H]
    \centering
    
    \caption{Module barométrique Bosch BMP581.}
    \label{fig:bmp581_hub_img}
\end{figure}

\begin{table}[H]
    \centering
    \begin{tabular}{|l|l|}
        \hline
        \textbf{Broche} & \textbf{ESP32-WROVER} \\
        \hline
        VCC & Bus 3V3 \\
        \hline
        GND & Masse commune \\
        \hline
        SCL & GPIO 14 \\
        \hline
        SDA (SDI) & GPIO 13 \\
        \hline
        SDO & GPIO 27 \\
        \hline
        CS (CSB) & GPIO 5 \\
        \hline
        INT & GPIO 21 \\
        \hline
    \end{tabular}
    \caption{Brochage du baromètre BMP581 sur le bus HSPI remappé du Hub.}
    \label{tab:pinout_bmp581_hub}
\end{table}

\subsubsection{Centrale Inertielle (Bosch BMI088)}

Afin de corriger l'inclinaison du véhicule, le référentiel gravitaire est fourni par la centrale inertielle Bosch BMI088. Plébiscité dans l'ingénierie des drones professionnels pour sa fiabilité reconnue et sa non-dérive, ce composant est particulièrement adapté aux environnements subissant les vibrations intenses des engins de chantier \cite{BMI088}. Son raccordement physique exploite le bus VSPI natif du microcontrôleur pour assurer les transferts ultra-rapides exigés par la fréquence d'échantillonnage de 400~Hz.

\begin{figure}[H]
    \centering
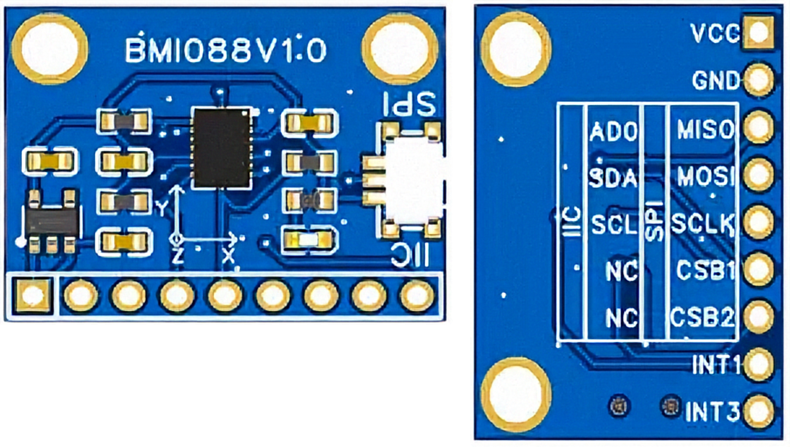
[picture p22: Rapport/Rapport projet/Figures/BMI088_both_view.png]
    
    \caption{Vues du module de centrale inertielle Bosch BMI088.}
    \label{fig:bmi088_img}
\end{figure}

\begin{table}[H]
    \centering
    \begin{tabular}{|p{6cm}|p{8cm}|}
        \hline
        \textbf{Caractéristique / Fonctionnalité} & \textbf{Spécification} \\
        \hline
        Plage de tension d'alimentation (VDD) & 2.4 V à 3.6 V \\
        \hline
        Consommation nominale & Accéléromètre: 150 $\mu$A / Gyroscope: 5.0 mA \\
        \hline
        Précision / Plage Accéléromètre & $\pm 3\text{g}$ à $\pm 24\text{g}$ ($10920\text{ LSB/g}$ max) \\
        \hline
        Précision / Plage Gyroscope & $\pm 125^\circ/\text{s}$ à $\pm 2000^\circ/\text{s}$ ($262.144\text{ LSB/}^\circ\text{/s}$ max) \\
        \hline
        Protocoles de communication & I2C, SPI \\
        \hline
        Filtre passe-bas intégré & OUI \\
        \hline
        Résistance anti-résonance & OUI (Grade Drone) \\
        \hline
        Prix & 13,00 € \\
        \hline
    \end{tabular}
    \caption{Spécifications de la centrale inertielle Bosch BMI088 \cite{BMI088}.}
    \label{tab:specs_bmi088}
\end{table}

\begin{table}[H]
    \centering
    \begin{tabular}{|l|l|}
        \hline
        \textbf{Broche} & \textbf{ESP32-WROVER (en VSPI)} \\
        \hline
        VCC & Bus 3V3 \\
        \hline
        GND & Masse Commune \\
        \hline
        MISO & GPIO 19 \\
        \hline
        MOSI & GPIO 23 \\
        \hline
        SCLK & GPIO 18 \\
        \hline
        CSB1 (accél.) & GPIO 26 \\
        \hline
        CSB2 (gyro.) & GPIO 22 \\
        \hline
        GPIO 39 VN (accél.) & INT1 \\
        \hline
        GPIO 36 VP (gyro.) & INT3 \\
        \hline
    \end{tabular}
    \caption{Interfaçage de l'IMU BMI088 avec le bus matériel VSPI du Hub \cite{BMI088}.}
    \label{tab:pinout_bmi088}
\end{table}

\textbf{Note sur le câblage :} La présence de deux broches "Chip Select" (\texttt{CSB1} et \texttt{CSB2}) est due à l'architecture physique du BMI088. Bien qu'il s'agisse d'un composant unique, il encapsule en réalité deux puces distinctes (le gyroscope et l'accéléromètre) qui doivent être interrogées séparément sur le même bus VSPI matériel.

\subsubsection{Transceiver CAN (TCAN1051V-Q1)}

La traduction des signaux logiques du contrôleur TWAI de l'ESP32 vers le réseau différentiel du véhicule est assurée par le transceiver TCAN1051V-Q1 \cite{TCAN1051-Q1}.

\begin{figure}[H]
    \centering
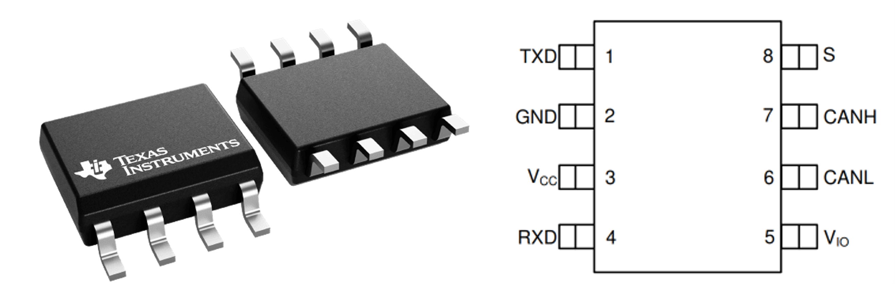
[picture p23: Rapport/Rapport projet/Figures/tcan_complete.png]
    
    \caption{Transceiver CAN Texas Instruments TCAN1051V-Q1.}
    \label{fig:tcan_img}
\end{figure}

\begin{table}[H]
    \centering
    \begin{tabular}{|p{6cm}|p{8cm}|}
        \hline
        \textbf{Caractéristique / Fonctionnalité} & \textbf{Spécification} \\
        \hline
        Vitesse de transmission max & Jusqu'à 1 Mbps (Classic CAN) / 2 Mbps (version non-G) \\
        \hline
        Protection contre les défauts de bus & $\pm 58\text{ V}$ \\
        \hline
        Immunité aux décharges (ESD/HBM) & $\pm 16\text{ kV}$ \\
        \hline
        Qualification environnement auto & OUI (AEC-Q100) \\
        \hline
        Broche VIO (Level Shifting logique) & OUI (Spécifique à la variante "V") \\
        \hline
        Prix & 2,15 € \\
        \hline
    \end{tabular}
    \caption{Spécifications du transceiver CAN Texas Instruments TCAN1051V-Q1 \cite{TCAN1051-Q1}.}
    \label{tab:specs_tcan_hub}
\end{table}

\begin{table}[H]
    \centering
    \begin{tabular}{|l|l|}
        \hline
        \textbf{Broche} & \textbf{ESP32-WROVER / Bus CAN} \\
        \hline
        1 (TXD) & GPIO 25 \\
        \hline
        2 (GND) & Masse Commune \\
        \hline
        3 (VCC) & Bus 5V \\
        \hline
        4 (RXD) & GPIO 34 \\
        \hline
        5 (VIO) & Bus 3V3 \\
        \hline
        6 (CANL) & Fil CANL (Câble Bus CAN) \\
        \hline
        7 (CANH) & Fil CANH (Câble Bus CAN) \\
        \hline
        8 (S) & Masse commune \\
        \hline
    \end{tabular}
    \caption{Brochage standardisé du transceiver CAN TCAN1051V-Q1 \cite{TCAN1051-Q1}.}
    \label{tab:pinout_tcan_hub}
\end{table}

\textbf{Note sur le câblage ($V_{IO}$) :} La sélection de la version comportant la lettre "V" est primordiale dans cette architecture : cette déclinaison intègre une entrée d'alimentation secondaire spécifique ($V_{IO}$) qui permet de décaler le niveau logique des seuils d'entrée et du signal de sortie RXD pour l'aligner parfaitement sur la tension de 3.3V du microcontrôleur. Cela protège l'ESP32 sans nécessiter aucun composant d'adaptation supplémentaire, tout en propulsant le bus de puissance CAN en 5V \cite{TCAN1051-Q1}. Par ailleurs, le forçage de la broche \texttt{8 (S)} à la masse empêche la puce de basculer en mode silencieux.

\newpage
% -------------------------------------------------------------------------
\subsection{Sous-Système 3 : Les ancres du véhicule}

\begin{figure}[H]
    \centering
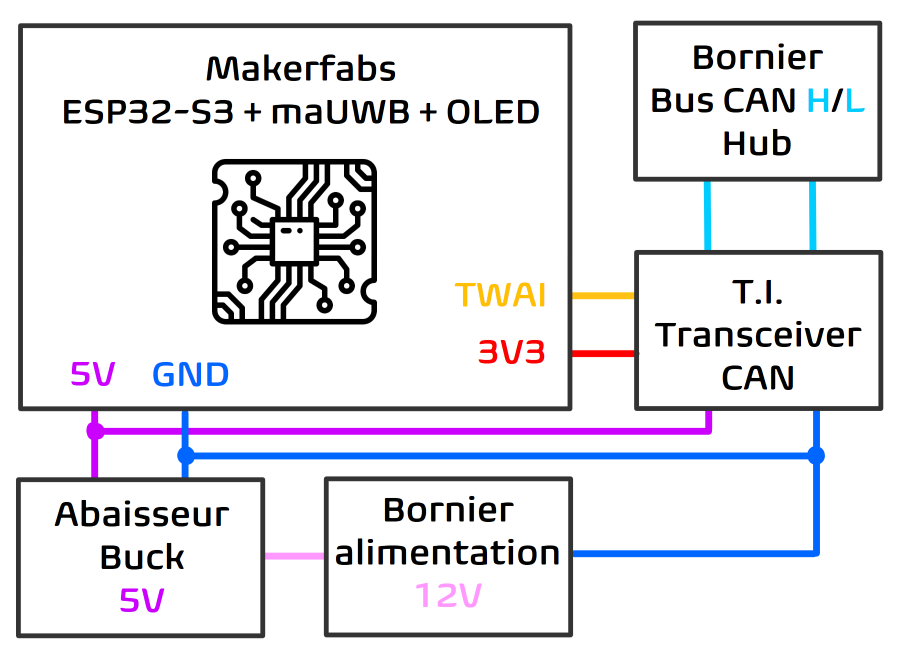
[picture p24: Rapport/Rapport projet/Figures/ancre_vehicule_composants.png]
    
    \caption{Architecture d'une ancre périphérique, montrant l'abaissement local de la tension et la traduction du signal série de la puce UWB vers le bus CAN différentiel.}
    \label{fig:ancre_vehicule}
\end{figure}

\subsubsection{Logique Télémétrique (Makerfabs ESP32-S3 + UWB)}

En réalité, nous avions besoin des modules MaUWB-DW3000 seuls pour nos ancres, mais les fournisseurs ne vendaient que la carte de développement complète les intégrant. Nous avons donc acheté ces cartes par nécessité. Le choix d'un processeur ESP32-S3 est technologiquement surdimensionné : l'objectif de l'ancre consiste simplement à faire du \textit{polling} (interrogation continue) sur le port UART du capteur UWB pour rafraîchir les distances, et à transmettre ces valeurs via le bus CAN lors d'une requête du Hub. Un microcontrôleur d'entrée de gamme extrêmement abordable (tel qu'un STM32G0 ou un ATmega) aurait amplement suffi pour cette tâche. Néanmoins, l'écran OLED intégré à la carte nous a offert un confort précieux pour déboguer les mesures sur le terrain. De plus, avant la réception des PCB finaux et en l'absence de réseau CAN opérationnel, la connectivité Wi-Fi de l'ESP32 nous a permis de tester et valider les protocoles de communication entre le Hub et les ancres de manière anticipée.

\begin{figure}[H]
    \centering
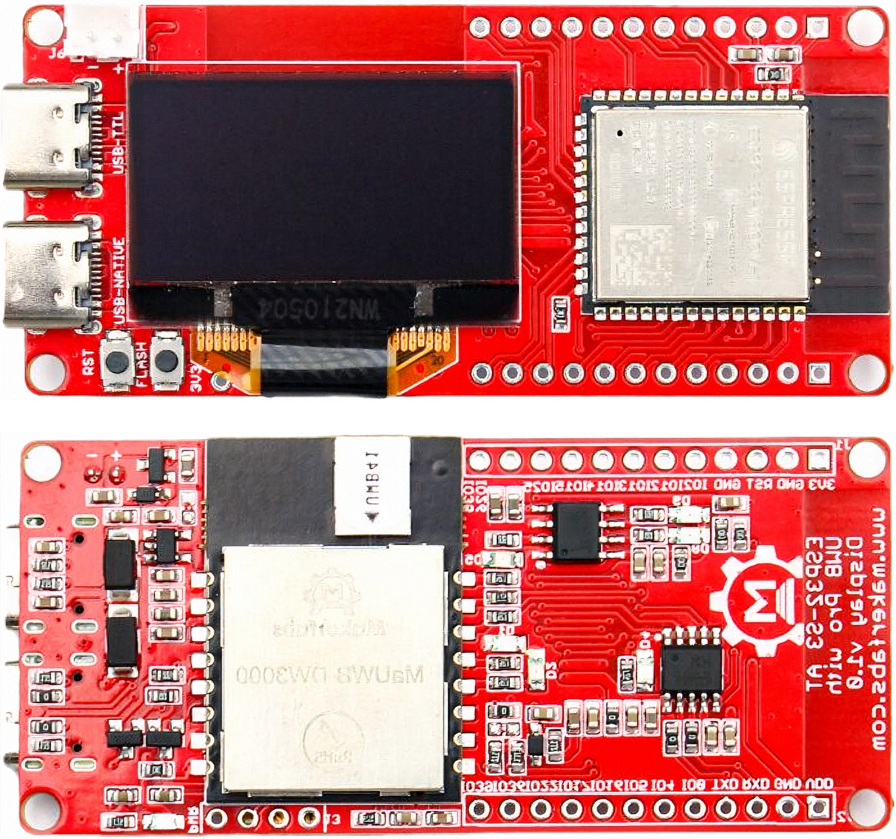
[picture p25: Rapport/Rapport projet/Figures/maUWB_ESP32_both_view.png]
    
    \caption{Carte Makerfabs ESP32-S3 embarquant le module UWB pour les Ancres.}
    \label{fig:mauwb_esp32_img}
\end{figure}

\begin{table}[H]
    \centering
    \begin{tabular}{|p{6cm}|p{8cm}|}
        \hline
        \textbf{Caractéristique / Fonctionnalité} & \textbf{Spécification} \\
        \hline
        Environnements de développement & Arduino IDE, ESP-IDF, PlatformIO, MicroPython \\
        \hline
        Module MaUWB intégré & OUI \\
        \hline
        Écran OLED intégré & OUI (1.3 pouces) \\
        \hline
        Ports USB & 2x USB Type-C (Natif + USB-UART TTL) \\
        \hline
        Prix & 75,50 € \\
        \hline
    \end{tabular}
    \caption{Spécifications de la carte de développement Makerfabs ESP32-S3 UWB \cite{UWB-AT-Module}.}
    \label{tab:specs_makerfabs_ancre}
\end{table}

% \begin{table}[H]
%     \centering
%     \begin{tabular}{|l|l|}
%         \hline
%         \textbf{Broche} & \textbf{Broche cible / Composant cible} \\
%         \hline
%         5V IN / GND & Sortie 5V / GND de l'abaisseur OKI-78SR \\
%         \hline
%         TX / RX & Broche 1 (TXD) / Broche 4 (RXD) du TCAN1051 \\
%         \hline
%     \end{tabular}
%     \caption{Connexions d'une ancre véhicule typique.}
%     \label{tab:pinout_ancre_uwb}
% \end{table}

\subsubsection{Transceiver CAN (TCAN1051V-Q1)}

La traduction des signaux logiques du contrôleur TWAI de l'ESP32 vers le réseau différentiel du véhicule est assurée par le transceiver TCAN1051V-Q1 \cite{TCAN1051-Q1}.

\begin{figure}[H]
    \centering
    
    \caption{Transceiver CAN Texas Instruments TCAN1051V-Q1.}
    \label{fig:tcan_img_ancre}
\end{figure}

\begin{table}[H]
    \centering
    \begin{tabular}{|p{6cm}|p{8cm}|}
        \hline
        \textbf{Caractéristique / Fonctionnalité} & \textbf{Spécification} \\
        \hline
        Vitesse de transmission max & Jusqu'à 1 Mbps (Classic CAN) / 2 Mbps (version non-G) \\
        \hline
        Protection contre les défauts de bus & $\pm 58\text{ V}$ \\
        \hline
        Immunité aux décharges (ESD/HBM) & $\pm 16\text{ kV}$ \\
        \hline
        Qualification environnement auto & OUI (AEC-Q100) \\
        \hline
        Broche VIO (Level Shifting logique) & OUI (Spécifique à la variante "V") \\
        \hline
        Prix & 2,15 € \\
        \hline
    \end{tabular}
    \caption{Spécifications du transceiver CAN Texas Instruments TCAN1051V-Q1 \cite{TCAN1051-Q1}.}
    \label{tab:specs_tcan_ancre}
\end{table}

\begin{table}[H]
    \centering
    \begin{tabular}{|l|l|}
        \hline
        \textbf{Broche} & \textbf{ESP32-WROVER / Bus CAN} \\
        \hline
        1 (TXD) & GPIO 9 (en TX) \\
        \hline
        2 (GND) & Masse Commune \\
        \hline
        3 (VCC) & Bus 5V \\
        \hline
        4 (RXD) & GPIO 10 (en RX) \\
        \hline
        5 (VIO) & Bus 3V3 \\
        \hline
        6 (CANL) & Fil CANL (Câble Bus CAN) \\
        \hline
        7 (CANH) & Fil CANH (Câble Bus CAN) \\
        \hline
        8 (S) & Masse commune \\
        \hline
    \end{tabular}
    \caption{Brochage standardisé du transceiver CAN TCAN1051V-Q1 \cite{TCAN1051-Q1}.}
    \label{tab:pinout_tcan_ancre}
\end{table}

\subsubsection{Régulation Locale (Murata OKI-78SR-5)}

Le réseau d'ancres reçoit une alimentation globale de 12V, qui est abaissée au sein de chaque boîtier. Le régulateur DC-DC Murata OKI-78SR génère un 5V très stable localement \cite{OKI-78SR_Series}. L'avantage majeur de ce composant à découpage est sa tolérance : il accepte de fonctionner parfaitement même si la tension d'entrée s'effondre jusqu'à 7V, autorisant ainsi une chute de tension importante dans la ligne sans jamais compromettre le fonctionnement de l'électronique embarquée \cite{OKI-78SR_Series}.

\begin{figure}[H]
    \centering
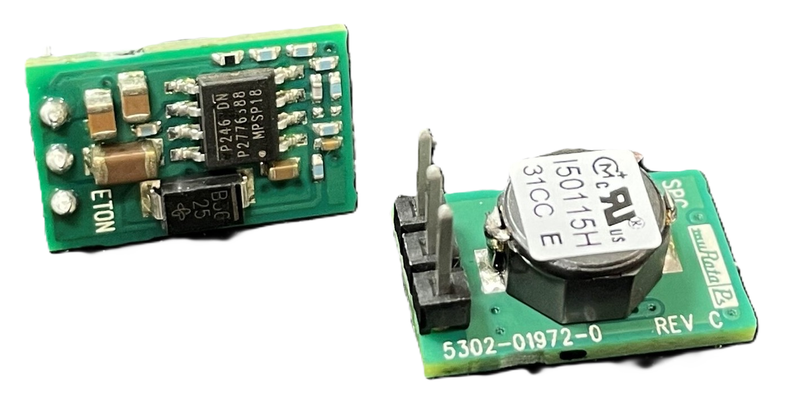
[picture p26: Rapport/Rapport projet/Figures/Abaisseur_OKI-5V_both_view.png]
    
    \caption{Régulateur DC-DC Murata OKI-78SR-5.}
    \label{fig:oki_img}
\end{figure}

\begin{table}[H]
    \centering
    \begin{tabular}{|p{6cm}|p{8cm}|}
        \hline
        \textbf{Caractéristique / Fonctionnalité} & \textbf{Spécification} \\
        \hline
        Tension de sortie fixe & 5 V \\
        \hline
        Courant de sortie maximum & 1.5 A \\
        \hline
        Plage de tension d'entrée tolérée & 7 V à 36 V \\
        \hline
        Prix & 4,69 € \\
        \hline
    \end{tabular}
    \caption{Spécifications du régulateur abaisseur Murata OKI-78SR-5 \cite{OKI-78SR_Series}.}
    \label{tab:specs_oki}
\end{table}

\begin{table}[H]
    \centering
    \begin{tabular}{|l|l|}
        \hline
        \textbf{Broche} & \textbf{Broche cible / Composant cible} \\
        \hline
        1 (Vin) & 12V (Ligne d'alimentation / Bouton) \\
        \hline
        2 (GND) & Masse Commune \\
        \hline
        3 (Vout) & Bus 5V \\
        \hline
    \end{tabular}
    \caption{Brochage du régulateur Murata OKI-78SR-5 \cite{OKI-78SR_Series}.}
    \label{tab:pinout_oki}
\end{table}

\subsubsection{Câblage Industriel (UNITRONIC LiYCY)}

Le réseau physique reliant le Hub aux différentes ancres repose sur un câble spécifique de type UNITRONIC\textsuperscript{\tiny\textregistered} LiYCY. Il s'agit d'un câble de données de quatre conducteurs, blindé et ignifuge, absolument indispensable pour résister aux environnements agressifs et aux intenses perturbations électromagnétiques d'un chantier.

\begin{figure}[H]
    \centering
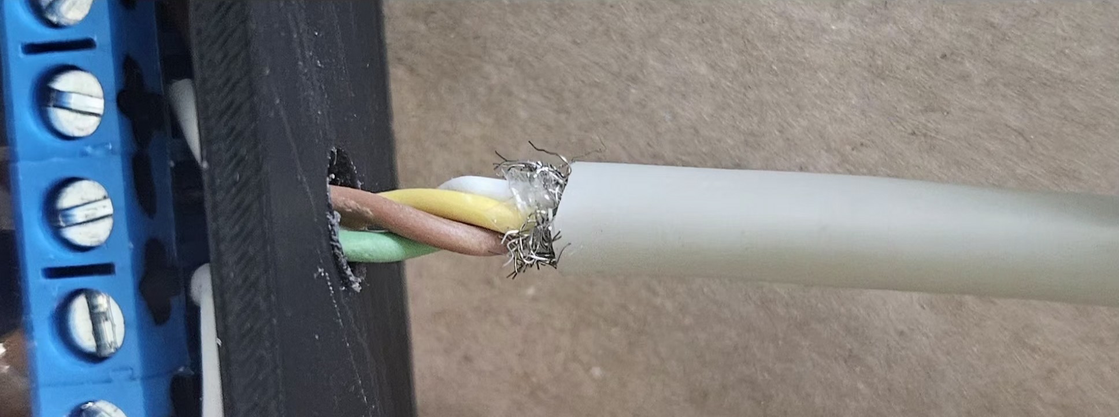
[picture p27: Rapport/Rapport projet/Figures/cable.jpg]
    
    \caption{Câble de données UNITRONIC LiYCY.}
    \label{fig:cable_img}
\end{figure}

\begin{table}[H]
    \centering
    \begin{tabular}{|p{6cm}|p{8cm}|}
        \hline
        \textbf{Caractéristique} & \textbf{Spécification} \\
        \hline
        Type de produit & Câble de données \\
        \hline
        Type de câble & UNITRONIC\textsuperscript{\tiny\textregistered} LiYCY \\
        \hline
        Nombre de conducteurs & 4 \\
        \hline
        Section (par conducteur) & 0.34 $\text{mm}^2$ \\
        \hline
        Spécificités & Blindé, ignifuge \\
        \hline
        Prix unitaire & 1,55 € / m \\
        \hline
    \end{tabular}
    \caption{Spécifications du câble de communication et puissance.}
    \label{tab:specs_cable}
\end{table}

\subsubsection{Consommation Globale et Chute de Tension}

Sur le véhicule, la consommation électrique a été précisément évaluée : le réseau composé exclusivement des ancres consomme 0.5~A sous 12V. Avec l'ajout du Hub centralisé dans la cabine, le système complet tire un courant total de 0.75~A sous 12V sur la batterie de l'engin.

L'acheminement de la puissance vers les ancres via le câble induit inexorablement une perte énergétique, dictée par la loi de Pouillet. La chute de tension $\Delta U$ évolue de manière linéaire avec la longueur du câble $L$ selon la formule :

\begin{equation}
    \Delta U = \frac{2 \cdot \rho \cdot L \cdot I}{S}
\end{equation}

Par exemple, sachant que la ligne dédiée aux ancres tire un courant de $I = 0.5\text{ A}$, et pour une longueur probable de $L = 30$ mètres sur un gros engin avec une résistivité du cuivre $\rho \approx 0.017\text{ }\Omega\cdot\text{mm}^2/\text{m}$, la résistance cumulée génère une chute d'environ $\Delta U = 1.5\text{ Volts}$. La tension résiduelle aux bornes de la dernière ancre sera donc de 10.5V, une valeur qui reste confortablement supérieure à la limite critique des 7V exigés par le régulateur interne des ancres.

Enfin, l'utilisation provisoire de borniers à vis traversant les boîtiers 3D devra idéalement laisser place à des connecteurs Weipu SF12 \cite{Weipu_SF12}. Leurs contacts à sertir sans soudure et leur conception "Push-Pull" lisse (empêchant l'accumulation de ciment) répondront parfaitement aux exigences d'étanchéité et de résistance aux vibrations des engins de BTP.

\newpage
% -------------------------------------------------------------------------
\subsection{Bloc d'Énergie et Auto-Maintien (Système Relais-Bouton-Alimentation)}

\begin{figure}[H]
    \centering
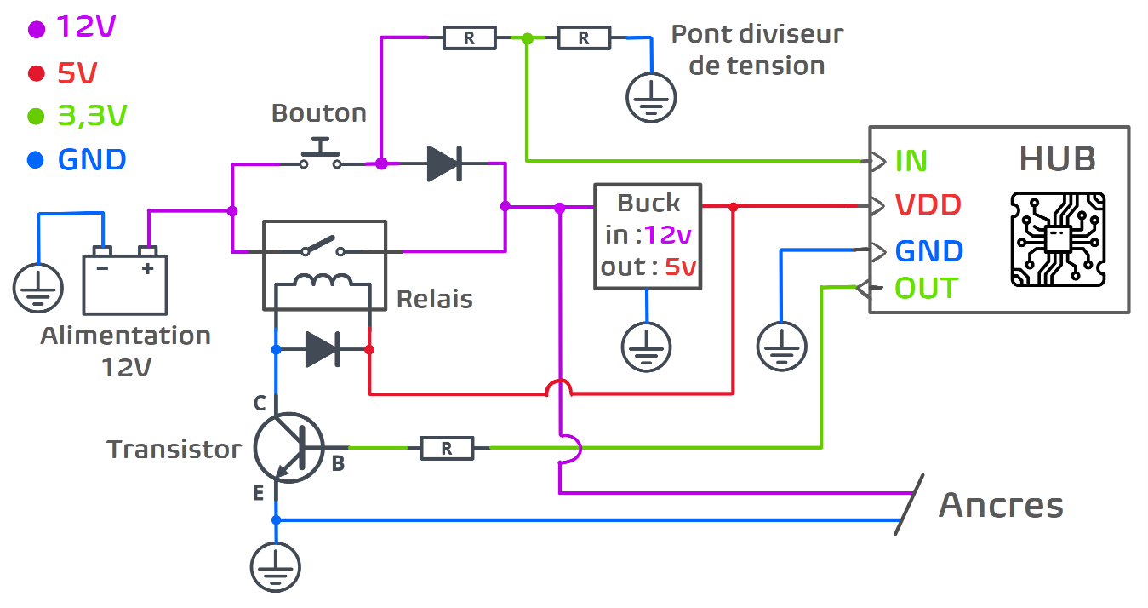
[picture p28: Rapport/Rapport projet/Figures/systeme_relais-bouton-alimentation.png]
    
    \caption{Logique matérielle d'auto-maintien de l'énergie et gestion de l'allumage sécurisé.}
    \label{fig:relais_bouton}
\end{figure}

Ce bloc gère l'admission énergétique depuis la batterie de l'engin. L'allumage repose sur un système d'auto-maintien initié par un bouton-poussoir lumineux (d'une valeur de 11,71 €). Lors d'une pression sur ce bouton, la tension de 12V réveille le régulateur. Un pont diviseur abaisse ce 12V à environ 2.9V pour que le GPIO 35 lise l'état physique du bouton. L'ESP32 active ensuite le relais électromécanique, dont les deux voies sont câblées en parallèle pour supporter la puissance \cite{DSY2Y_Series}. Le relais verrouille alors l'alimentation, et l'extinction devient purement logicielle en cas d'absence prolongée de conducteur \cite{Desc_Projet}. La lecture du bouton permet également d'attribuer des fonctions secondaires (comme l'activation du Wi-Fi pour un étalonnage via smartphone) en cas d'appui long \cite{Desc_Projet}.

\begin{figure}[H]
    \centering
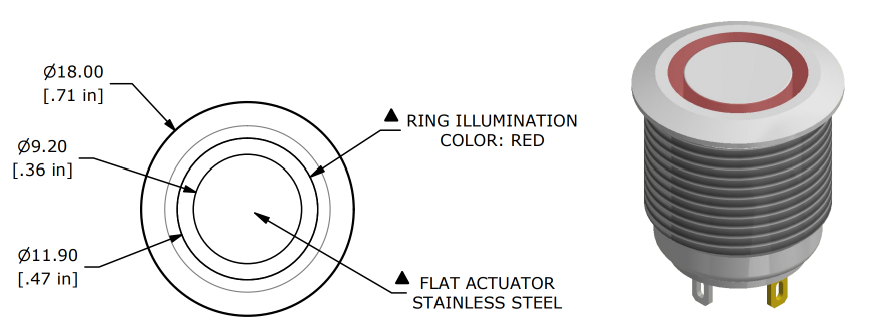
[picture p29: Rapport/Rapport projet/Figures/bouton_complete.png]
    
    \caption{Bouton-poussoir lumineux d'allumage de la cabine.}
    \label{fig:bouton_img}
\end{figure}

\begin{table}[H]
    \centering
    \begin{tabular}{|l|l|}
        \hline
        \textbf{Broche} & \textbf{Broche cible / Composant cible} \\
        \hline
        Broche 1 (Contact) & Entrée +12V (Batterie) \\
        \hline
        Broche 2 (Contact) & Anode (Diode FR107) et Patte 1 (Résistance diviseur 10K) \\
        \hline
        LED (+) & GPIO 12 (ESP32-WROVER) \\
        \hline
        LED (-) & Patte 1 (Résistance limitation 150$\Omega$) \\
        \hline
    \end{tabular}
    \caption{Brochage du bouton-poussoir lumineux d'allumage.}
    \label{tab:pinout_bouton}
\end{table}

\begin{figure}[H]
    \centering
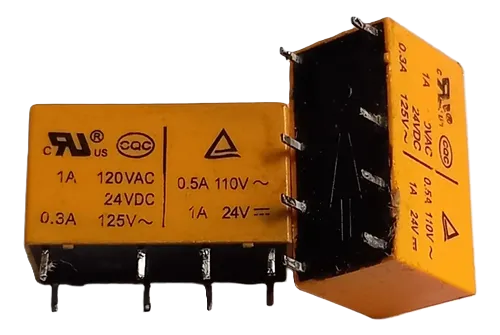
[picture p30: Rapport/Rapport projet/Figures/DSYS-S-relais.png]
    
    \caption{Relais électromécanique Sanyou DSY2Y.}
    \label{fig:relais_img}
\end{figure}

\begin{table}[H]
    \centering
    \begin{tabular}{|p{6cm}|p{8cm}|}
        \hline
        \textbf{Caractéristique / Fonctionnalité} & \textbf{Spécification} \\
        \hline
        Tension Nominale (Bobine) & 5 VDC \\
        \hline
        Puissance de fonctionnement nominale & 150 mW \\
        \hline
        Résistance de la bobine & $167\ \Omega \pm 10\%$ \\
        \hline
        Configuration des contacts & 2C (DPDT) \\
        \hline
        Courant de commutation maximal & 2 A \\
        \hline
        Puissance de commutation maximale & 120VA / 48W \\
        \hline
        Prix & Fourni par l'ESIEE \\
        \hline
    \end{tabular}
    \caption{Spécifications du relais électromécanique Sanyou DSY2Y-S2-05H \cite{DSY2Y_Series}.}
    \label{tab:specs_relais}
\end{table}

\begin{table}[H]
    \centering
    \begin{tabular}{|l|l|}
        \hline
        \textbf{Broche} & \textbf{Broche cible / Composant cible} \\
        \hline
        1. COIL 1 & Bus +5V (Abaisseur de tension) \\
        \hline
        16. COIL 2 & Collecteur (C) (Transistor NPN 2N2222) \\
        \hline
        4. COM\_1 / 13. COM\_2 & Entrée +12V (Batterie - Câblage parallèle) \\
        \hline
        8. NO\_1 / 9. NO\_2 & Entrée (IN+) de l'abaisseur 12V-5V (Câblage parallèle) \\
        \hline
        6. NC\_1 / 11. NC\_2 & Non connecté \\
        \hline
    \end{tabular}
    \caption{Brochage du relais DSY2Y avec mise en parallèle des contacts de puissance \cite{DSY2Y_Series}.}
    \label{tab:pinout_relais}
\end{table}

\textbf{Note sur le câblage :} Le câblage redondant des broches d'entrée (\texttt{COM\_1} et \texttt{COM\_2}) et de sortie (\texttt{NO\_1} et \texttt{NO\_2}) permet de mettre en parallèle les deux contacts électromécaniques internes du relais. Le courant se divise ainsi entre les deux lames, doublant la capacité de charge thermique (de 1A à 2A sous 12V) pour supporter confortablement l'appel de puissance du système entier.

En aval du relais se trouve l'abaisseur de tension (Buck). Initialement, nous avions prévu d'utiliser le même régulateur de 5V 1.5A que pour les ancres, mais il s'est avéré beaucoup trop faible pour alimenter l'ensemble du Hub. Nous l'avons donc remplacé dans l'urgence par un régulateur réglable issu de nos stocks, un choix fonctionnel mais non optimal \cite{XL0415}. Pour une version industrielle, un stabilisateur isolé Meanwell de 12V devra être placé en amont de toute l'installation pour prendre en charge les batteries de véhicules de 12V ou 14V et filtrer les redoutables chutes et pics de tension générés par l'alternateur \cite{MeanWell_SD50A12, Desc_Projet}.

\begin{figure}[H]
    \centering
    
    \caption{Module abaisseur de tension (Buck) XL4015.}
    \label{fig:xl4015_img}
\end{figure}

\begin{table}[H]
    \centering
    \begin{tabular}{|p{6cm}|p{8cm}|}
        \hline
        \textbf{Caractéristique / Fonctionnalité} & \textbf{Spécification} \\
        \hline
        Tension de sortie & Ajustable (réglée ici sur 5V) \\
        \hline
        Courant de sortie maximal & Jusqu'à 5 A (selon dissipation thermique) \\
        \hline
        Rendement (Efficacité) & Jusqu'à $\approx 95\%$ \\
        \hline
        Prix & Fourni par l'ESIEE \\
        \hline
    \end{tabular}
    \caption{Spécifications de l'abaisseur de tension XL4015 \cite{XL0415}.}
    \label{tab:specs_xl4015}
\end{table}

\begin{table}[H]
    \centering
    \begin{tabular}{|l|l|}
        \hline
        \textbf{Broche} & \textbf{Broche cible / Composant cible} \\
        \hline
        IN+ & NO\_1 et NO\_2 (Relais) \\
        \hline
        IN- & Bus GND (Masse Commune) \\
        \hline
        OUT+ & Bus +5V (Ligne d'alimentation principale Hub) \\
        \hline
        OUT- & Bus GND (Masse Commune) \\
        \hline
    \end{tabular}
    \caption{Brochage du module abaisseur XL4015.}
    \label{tab:pinout_xl4015}
\end{table}
\newpage
% =========================================================================
% FIN DE LA SECTION
% =========================================================================

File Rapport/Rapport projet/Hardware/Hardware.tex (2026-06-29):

\subsection{Introduction}
 
Le projet Vigizone demande une architecture matérielle complexe qui ne peut être réalisée par une ou plusieurs cartes toutes faites.
Il est donc nécessaire de concevoir une carte électronique sur mesure pour répondre aux besoins du projet.
Les cartes doivent être capables de gérer les différents capteurs et actionneurs nécessaires au fonctionnement du système, tout en respectant les contraintes de taille, de consommation d'énergie et de coût.
Pour ce faire, nous nous sommes appuyés sur le cahier des charges réalisé à l'aide de GTM OUEST pour la conception technique.

%------------------------------------------------

\subsection{Choix des composants}
\input{Hardware/choixcomposant.tex}

\subsection{Hub}

\subsubsection{Choix du logiciel}
Une fois les composants choisis, il est temps de passer à la conception de la carte
qui accueillera tous les composants nécessaires au fonctionnement du système.
La première étape consiste à choisir le logiciel de conception de PCB.
Pour ce projet, nous avons choisi le logiciel KiCad, qui est un logiciel libre et open source.
Nous avions hésité avec Proteus, car celui-ci possède des fonctionnalités très intéressantes, notamment pour la simulation ou encore pour du routage.
Mais tout le monde n'ayant pas de licence dans le groupe, et suite à la recommandation de l'école d'utiliser ce logiciel, nous nous sommes rabattus sur KiCad.

\subsubsection{Librairie}

Pour la conception du schéma, nous avons d'abord mis en place un suivi des composants,
qui vise à savoir quels sont les composants mis sur le schéma, ainsi que ceux dont l'empreinte est manquante.

\begin{figure}[!ht]
\centering 
 
\caption[Extrait du tableau de suivi]{Extrait du tableau de suivi}
\label{fig: mise en oeuvre}
\end{figure}

Pour récupérer les différentes empreintes/symboles, nous avons utilisé plusieurs banques de données spécialisées,
telles que : 

\begin{itemize}
    \item Mouser \cite{Mouser}
    \item componentsearchengine \cite{componentsearchengine}
    \item EasyEDA \cite{EasyEDA}
    \item LCSC \cite{LCSC}
\end{itemize}

Cela nous a permis d'avoir la majeure partie des empreintes/symboles.
Cependant, certains composants très spécifiques sont difficilement trouvables, voire inexistants.
Pour pallier ce problème, KiCad intègre un outil de création de composants avec une précision allant jusqu'au nanomètre.
Nous avons pu, grâce à cet outil, refaire l'empreinte du BMP581 \cite{BMP581}, du module UWB \cite{UWB-AT-Module},
du connecteur Roover ou encore de l'abaisseur de tension \cite{5A-XL4015-DC-DC-Abaisser-Alimentation}.

Une fois la recherche de tous les composants terminée, nous avons mis en place une librairie KiCad propre au projet.
Celle-ci permet d'avoir une banque de données commune à toutes les cartes et d'éviter de potentiels problèmes de PATH.
Cela nous donne une librairie composée de tous les composants, comme nous pouvons le voir sur la Figure \ref{fig: lib_Kicad}.

\begin{figure}[!ht]
\centering 
 
\caption[Extrait du gestionnaire de librairie KiCad]{Extrait du gestionnaire de librairie KiCad}
\label{fig: lib_Kicad}
\end{figure}

\subsubsection{Conception du schéma d'alimentation}

Une fois tous les composants prêts, nous avons commencé le schéma électronique.
Celui-ci se découpe en quatre parties plus ou moins indépendantes que nous allons étudier.
La première partie que nous allons étudier est la section alimentation : 

\begin{figure}[!ht]
\centering 
 
\caption[Partie alimentation de la carte Hub]{Partie alimentation de la carte Hub}
\label{fig:sch-alim-hub}
\end{figure}

La carte du Hub est destinée à être alimentée par la batterie de l'engin sur lequel elle se trouve.
La batterie fournissant du 12V, il faut réussir à s'en servir. Or, il s'avère qu'il n'existe 
aucun microcontrôleur capable de supporter du 12V, le maximum étant de 5V ou 3.3V. Nous avons donc mis en place
un abaisseur de tension 12V $\rightarrow$ 5V de la série OKI-78SR \cite{OKI-78SR_Series}.
Mais en regardant de plus près la datasheet, on remarque que celui-ci ne peut fournir que 4W.
Cela ne pose pas de problème dans la plupart des cas, mais dans le nôtre, si.
Alimenter la carte Hub revient non seulement à alimenter la carte la plus gourmande en énergie et celle qui comporte le plus de composants,
mais surtout à alimenter également l'écran, qui consomme à lui tout seul 2.5W.
Pour éviter tout risque, nous avons donc pris la décision de passer sur un modèle plus puissant,
à savoir le 5A-XL4015-DC-DC \cite{5A-XL4015-DC-DC-Abaisser-Alimentation}. Celui-ci est capable de fournir plus de 30 Watts,
ce qui est largement suffisant pour notre utilisation.
Nous avons choisi le 5A-XL4015-DC-DC \cite{5A-XL4015-DC-DC-Abaisser-Alimentation} car c'était le seul modèle assez puissant que nous avions sous la main,
mais il est évident qu'il est inutilement trop puissant.
Il est donc fortement envisageable de modifier le choix de l'abaisseur pour une potentielle V2 du prototype,
qui serait plus compacte et adaptée à notre usage.

\bigskip
Comme le montre la Figure \ref{fig:sch-alim-hub}, l'entrée du 12V dans l'abaisseur de tension
se fait à l'aide d'un relais DSY2Y-S-205H \cite{DSY2Y_Series}. Nous avons décidé de mettre en place
un relais connecté en permanence au 12V et qui est activé à l'aide d'une broche GPIO.
Le principe est de pouvoir décider d'alimenter ou non la carte, et tout ce qui en découle, à l'aide de ce relais.

\begin{figure}[!ht]
\centering 
 
\caption[Extrait de la datasheet du DSY2Y-S-205H]{Extrait de la datasheet du DSY2Y-S-205H}
\label{fig:sch-datasheet-relais}
\end{figure}

Sur le schéma de la Figure \ref{fig:sch-alim-hub}, Com\_1 et Com\_2 représentent les deux languettes 
qui passent de NC\_1 et NC\_2 (\textit{Normally Closed}) à NO\_1 et NO\_2 (\textit{Normally Open}) lorsqu'un courant passe dans la 
bobine (coil\_1 et coil\_2), ce qui crée un champ magnétique et fait bouger les languettes.
La bobine est donc connectée en permanence au +5V, mais elle est reliée à la masse à l'aide d'un 
transistor 2N2222.
Celui-ci est contrôlé à l'aide d'une broche du GPIO et de la résistance $R_7 = 1\text{ k}\Omega$.  

\subsubsection*{1. Calcul de fonctionnement du transistor $Q_1$}

Pour valider le fonctionnement en commutation du transistor $Q_1$ (\texttt{2N2222B}) qui pilote la bobine du relais, 
il convient d'effectuer l'étude théorique de sa saturation à partir des caractéristiques électriques des composants du circuit.

\subsubsection*{Données initiales}
\begin{itemize}
    \item \textbf{ESP32-WROVER} 
    \begin{itemize}
        \item Tension GPIO : $V_{in} = 3{,}3\text{ V}$
        \item Résistance de base ($R_7$) : $R_7 = 1\text{ k}\Omega$
    \end{itemize}
    \item \textbf{Transistor bipolaire (2N2222B) :}
    \begin{itemize}
        \item Tension de saturation base-émetteur : $V_{BE,sat} \approx 0{,}7\text{ V}$
        \item Tension de saturation collecteur-émetteur : $V_{CE,sat} \approx 0{,}2\text{ V}$
        \item Gain en courant statique minimal en saturation ($h_{FE,min}$) : $\approx 75$
    \end{itemize}
    \item \textbf{Bobine du relais :}
    \begin{itemize}
        \item Tension d'alimentation : $V_{CC} = 5\text{ V}$
        \item Résistance interne de la bobine : $R_{bobine} = 167\ \Omega$
    \end{itemize}
\end{itemize}

Lorsque le transistor est saturé, il est assimilable à un interrupteur fermé. La tension à ses bornes chute à sa 
valeur de saturation $V_{CE,sat}$. Le courant nominal $I_C$ traversant la charge est alors défini par la loi d'Ohm :
\begin{equation}
    I_C = \frac{V_{CC} - V_{CE,sat}}{R_{bobine}}
\end{equation}

En appliquant les valeurs numériques :
\begin{equation}
    I_C = \frac{5\text{ V} - 0{,}2\text{ V}}{167\ \Omega} = \frac{4{,}8\text{ V}}{167\ \Omega} \approx 0{,}0287\text{ A} \approx 28{,}7\text{ mA}
\end{equation}

Le transistor doit donc pouvoir absorber un courant d'environ $28{,}7\text{ mA}$ sur son collecteur pour
permettre le basculement du relais.

\bigskip

Le courant de commande injecté par la broche GPIO à travers la résistance de protection $R_7$ est déterminé 
en soustrayant la barrière de potentiel de la jonction base-émetteur ($V_{BE,sat}$) :
\begin{equation}
    I_B = \frac{V_{in} - V_{BE,sat}}{R_7}
\end{equation}

Soit numériquement :
\begin{equation}
    I_B = \frac{3{,}3\text{ V} - 0{,}7\text{ V}}{1000\ \Omega} = \frac{2{,}6\text{ V}}{1000\ \Omega} = 0{,}0026\text{ A} = 2{,}6\text{ mA}
\end{equation}

La broche GPIO fournit ainsi un courant de $2{,}6\text{ mA}$ à la base du transistor.

\bigskip
Pour s'assurer du blocage et de la saturation complets en mode de commutation, deux critères complémentaires sont vérifiés :

\paragraph{Méthode par le courant de base minimal ($I_{B,min}$)} 
Le courant de base minimal théorique requis pour saturer le transistor sous un courant de collecteur de $28{,}7\text{ mA}$ 
est fonction de son gain minimal :
\begin{equation}
    I_{B,min} = \frac{I_C}{h_{FE,min}} = \frac{28{,}7\text{ mA}}{75} \approx 0{,}38\text{ mA}
\end{equation}
Le courant injecté réel ($I_B = 2{,}6\text{ mA}$) étant très largement supérieur au minimum requis ($0{,}38\text{ mA}$), 
la condition de saturation $I_B > I_{B,min}$ est validée.

\paragraph{Méthode par le gain forcé ($\beta_{forcé}$)} 
Le gain forcé, imposé par les composants périphériques du montage, se calcule comme suit :
\begin{equation}
    \beta_{forcé} = \frac{I_C}{I_B} = \frac{28{,}7\text{ mA}}{2{,}6\text{ mA}} \approx 11
\end{equation}
Les règles de l'art en ingénierie électronique préconisent l'usage d'un gain forcé proche de $10$ 
pour s'affranchir des dispersions de fabrication des transistors et des dérives thermiques. 

\bigskip
Avec un gain forcé calculé de $\approx 11$ (très proche de la valeur idéale) et un courant 
de base réel environ sept fois supérieur au strict minimum requis, le transistor $Q_1$ 
se trouve dans un état de saturation franche et robuste. Le choix de la résistance
$R_7 = 1\text{ k}\Omega$ est donc optimal.

\subsubsection*{2. Rôle de la diode de roue libre $D_3$}

La diode $D_3$, positionnée en parallèle avec la bobine du relais, est un composant 
de protection indispensable dans ce type de montage en commutation. 
Elle remplit la fonction de \textit{diode de roue libre} (ou \textit{flyback diode}). 
Son rôle est de protéger le transistor $Q_1$ contre les surtensions destructrices induites 
lors de son blocage.

\bigskip
La bobine du relais se comporte électriquement comme une inductance ($L$). Une propriété 
fondamentale d'une inductance est son opposition à toute variation brutale du courant qui 
la traverse, accumulant de l'énergie sous forme d'un champ magnétique :
\begin{itemize}
    \item \textbf{À l'état passant :} Le courant circule dans la bobine et le transistor $Q_1$ conduit normalement.
    \item \textbf{Au blocage du transistor :} Lorsque la broche GPIO repasse à $0\text{ V}$, le transistor $Q_1$ s'ouvre instantanément pour interrompre le courant. 
    \item \textbf{Génération de la surtension :} Le courant ne pouvant s'annuler instantanément dans l'inductance, la rupture brutale ($di/dt$) provoque l'inversion de la polarité aux bornes de la bobine et génère une force électromotrice induite élevée, régie par la loi de Lenz-Faraday :
    \begin{equation}
        e = -L \frac{di}{dt}
    \end{equation}
\end{itemize}
Sans protection, cette surtension inverse se répercute directement sur le collecteur du 
transistor $Q_1$, pouvant atteindre plusieurs centaines de volts. Cette valeur dépassant
largement la tension de claquage maximale admissible du composant (\texttt{2N2222B}), 
elle entraîne sa destruction immédiate par claquage.

\bigskip
La diode $D_3$ est branchée en inverse par rapport à la tension d'alimentation normale
de $5\text{ V}$, ce qui signifie qu'elle est bloquée et ne consomme aucun courant
lorsque le relais est activé.

Cependant, au moment précis où le transistor s'ouvre :
\begin{enumerate}
    \item La bobine inverse sa polarité pour tenter de maintenir la continuité du courant.
    \item Cette inversion de potentiel rend la diode $D_3$ passante (polarisation en direct).
    \item Le pic de courant induit est alors dérivé à travers la diode, circulant en boucle fermée au sein du dipôle formé par la bobine et la diode jusqu'à la dissipation complète de l'énergie magnétique sous forme thermique.
\end{enumerate}

 \bigskip
La diode $D_3$ agit comme un bouclier de décharge. En limitant la tension aux bornes
du transistor à sa propre tension de seuil en direct ($\approx 0{,}7\text{ V}$), 
elle sécurise efficacement le transistor $Q_1$ ainsi que la sortie GPIO du microcontrôleur
contre tout retour de surtension dangereux.

\bigskip
Tout cela fonctionne très bien, à condition que la broche GPIO puisse être à l'état haut.
Pour cela, nous avons mis en place un bouton que vous pouvez voir sur la Figure \ref{fig:sch-alim-hub}.
Représenté par les borniers $U_6$ et $U_7$, le bouton-poussoir PV6F240SS-311 \cite{bouton_poussoir_PV6F240SS-311}
est directement connecté au 12V de la batterie. Celui-ci permet d'alimenter le microcontrôleur.

\subsubsection*{3. Interface et conditionnement de l'entrée du bouton-poussoir}

Le bloc connecté au bornier à vis \texttt{U6} (bouton-poussoir PV6F240SS-311 \cite{bouton_poussoir_PV6F240SS-311})
sert d'interface d'adaptation de niveau et de protection entre une tension d'entrée externe élevée ($V_{in} = 12\text{ V}$) 
et une broche d'entrée numérique (GPIO) du microcontrôleur, dont la tension admissible maximale est de $3{,}3\text{ V}$. 
Cette interface repose sur l'association des résistances $R_4$, $R_6$ et de la diode $D_2$.

\bigskip
Lorsque le bouton-poussoir est actionné, la tension d'alimentation globale $V_{in} = 12\text{ V}$ est appliquée en entrée du montage. 
Afin de ne pas détruire la broche du microcontrôleur, les résistances $R_4$ et $R_6$ sont configurées en pont diviseur de tension.
La tension convertie $V_{GPIO}$ envoyée vers le microcontrôleur est exprimée par la relation suivante :
\begin{equation}
    V_{GPIO} = V_{in} \cdot \frac{R_6}{R_4 + R_6}
\end{equation}

En injectant les valeurs numériques du schéma ($R_4 = 10\text{ k}\Omega$ et $R_6 = 3{,}3\text{ k}\Omega$) :
\begin{equation}
    V_{GPIO} = 12\text{ V} \cdot \frac{3{,}3\text{ k}\Omega}{10\text{ k}\Omega + 3{,}3\text{ k}\Omega} = 12 \cdot \frac{3{,}3}{13{,}3} \approx 2{,}98\text{ V}
\end{equation}

La tension obtenue d'environ $2{,}98\text{ V}$ est parfaitement calibrée : 
elle est supérieure au seuil minimal requis pour valider un niveau logique haut (\texttt{HIGH}) 
tout en restant inférieure à la limite stricte de $3{,}3\text{ V}$. 

De plus, lorsque le bouton-poussoir est relâché, la résistance $R_6$ remplit la fonction de résistance de rappel
à la masse (\textit{pull-down}), garantissant un niveau logique bas (\texttt{LOW}) stable à $0\text{ V}$ en 
évitant tout état flottant induit par des bruits parasites.

\bigskip
Le bouton-poussoir étant déporté sur un connecteur physique (\texttt{U6}), les lignes de liaison filaires sont sujettes à des perturbations électromagnétiques, 
des décharges électrostatiques ou des pics de surtension liés directement à la batterie du véhicule, qui ne délivre pas toujours exactement $V_{in} = 12\text{ V}$.
La diode $D_2$ (\texttt{FR107}), connectée entre la ligne de signal et le rail d'alimentation $+5\text{ V}$, fait office de diode d'écrêtage :

\begin{itemize}
    \item \textbf{Fonctionnement normal :} La tension sur la ligne étant de $\approx 2{,}98\text{ V}$, la diode $D_2$ est polarisée en inverse. Elle est donc bloquée et n'interfère pas avec le signal.
    \item \textbf{Fonctionnement en cas de surtension :} Si un pic de tension transitoire supérieur à $5\text{ V} + V_F \approx 5{,}7\text{ V}$ apparaît sur la ligne, la diode $D_2$ devient passante en direct. Elle ponte et dérive le surplus de courant destructeur vers le rail $+5\text{ V}$, verrouillant la tension maximale vue par le microcontrôleur à une valeur sûre.
\end{itemize}

Dans ce scénario de défaillance, la résistance $R_4$ ($10\text{ k}\Omega$) joue un rôle additionnel de limitation de courant. 
Le courant de défaut maximal traversant la diode est bridé à une valeur hautement sécurisée :
\begin{equation}
    I_{clamping} = \frac{V_{in} - (5\text{ V} + 0{,}7\text{ V})}{R_4} = \frac{12\text{ V} - 5{,}7\text{ V}}{10000\ \Omega} = 0{,}63\text{ mA}
\end{equation}

\bigskip
Ce sous-ensemble assure une double fonction essentielle à la robustesse de la carte électronique. 
Le couple $R_4$/$R_6$ réalise l'atténuation d'amplitude nécessaire à la lecture numérique d'un signal
$12\text{ V}$ par un processeur $3{,}3\text{ V}$, tandis que la diode $D_2$ immunise l'entrée contre 
les agressions électriques externes.

\bigskip
Pour finir, on retrouve sur $U_7$ une résistance $R_2$ ($150\,\Omega$) connectée à un GPIO. $U_7$
est relié à la LED du bouton et nécessite 1.8V (la gestion de la LED est gérée logiciellement).
%------------------------------------------------

\subsubsection{Conception du schéma buzzer}

Une autre partie de la carte du Hub est le buzzer. En effet, il est au cœur même du dispositif,
étant l'un des deux éléments capables de prévenir le conducteur, l'autre étant l'écran.
Il est donc primordial que le buzzer fonctionne parfaitement. Pour cela, nous avons mis en place le schéma suivant :

\begin{figure}[!ht]
\centering 
 
\caption[Schéma du buzzer sur la carte Hub]{Schéma du buzzer sur la carte Hub}
\label{fig:sch-buzzer-hub}
\end{figure}

L'activation du buzzer \texttt{LS1} ($12\text{ V}$) nécessite une puissance électrique qu'une broche GPIO de
microcontrôleur ($3{,}3\text{ V}$) ne peut délivrer directement. La commande est donc déléguée au
transistor $Q_2$ (\texttt{2N2222}) configuré en commutation. Ce circuit est stabilisé par 
la résistance de base $R_3$ et la diode de protection $D_1$.
Il s'agit d'un cas très similaire au transistor $Q_1$ de l'alimentation du relais vu précédemment.
Je considère donc comme acquises certaines notions et je simplifie l'explication.

\subsubsection*{1. Limitation du courant}
La jonction base-émetteur du transistor $Q_2$ se comportant comme une diode à commutation directe, 
sa tension de seuil en saturation est d'environ $V_{BE(sat)} \approx 0{,}7\text{ V}$. 
L'insertion de la résistance $R_3 = 1\text{ k}\Omega$ permet d'injecter un courant de base $I_B$ 
calibré pour assurer la saturation complète du transistor.

Le courant de commande de base injecté lors d'un niveau logique haut ($V_{GPIO} = 3{,}3\text{ V}$) se calcule par la loi d'Ohm :
\begin{equation}
    I_B = \frac{V_{GPIO} - V_{BE(sat)}}{R_3}
\end{equation}

En appliquant les valeurs de l'application numérique :
\begin{equation}
    I_B = \frac{3{,}3\text{ V} - 0{,}7\text{ V}}{1000\ \Omega} = \frac{2{,}6\text{ V}}{1000\ \Omega} = 2{,}6\text{ mA}
\end{equation}

Cette valeur de $2{,}6\text{ mA}$ respecte le fonctionnement des broches de sortie du microcontrôleur
tout en fournissant l'intensité nécessaire pour saturer fermement le transistor \texttt{2N2222}
vis-à-vis du courant collecteur requis par le buzzer.

\subsubsection*{2. Protection contre les surtensions}
Le buzzer \texttt{LS1} intègre un transducteur magnétique assimilable à une bobine. 
Le courant traversant une inductance ne peut pas s'annuler de manière instantanée.
Lorsque le signal de commande retombe à $0\text{ V}$, le transistor $Q_2$ se bloque subitement, 
ouvrant le circuit de puissance. À cet instant précis, la rupture brutale du courant ($dt \to 0$) 
provoque l'apparition d'une surtension transitoire très élevée ($v_L = L \frac{di}{dt}$) au nœud du collecteur.
Sans $D_1$, cette surtension dépasserait la tension maximale admissible du transistor, 
provoquant un claquage destructeur par effet d'avalanche.

La diode $D_1$ (\texttt{FR107}), montée en parallèle inversée, résout ce problème sous la forme 
d'une \textit{diode de roue libre} :
\begin{itemize}
    \item \textbf{À l'état saturé (Buzzer actif) :} La tension aux bornes du buzzer est proche de $12\text{ V}$. La cathode de la diode étant reliée au rail $+12\text{ V}$, la diode $D_1$ est polarisée en inverse. Elle est bloquée et se comporte comme un circuit ouvert.
    \item \textbf{À l'instant du blocage (Buzzer coupé) :} L'inversion de tension générée par l'inductance force la polarisation de $D_1$ en direct. La diode devient passante et offre un chemin de conduction fermé au courant résiduel stocké sous forme d'énergie magnétique. L'énergie se dissipe en boucle interne à travers la diode et la résistance parasite de la bobine.
\end{itemize}

L'activation de la diode $D_1$ verrouille (\textit{clame}) de fait le potentiel du collecteur 
de $Q_2$ à une valeur de sécurité maximale équivalente à :
\begin{equation}
    V_{C(max)} = V_{in} + V_F \approx 12\text{ V} + 0{,}7\text{ V} = 12{,}7\text{ V}
\end{equation}

La résistance $R_3$ assure l'interfaçage de commande bas courant en amont du commutateur, 
tandis que la diode $D_1$ immunise l'étage de puissance contre les phénomènes inductifs inverses en aval,
protégeant ainsi l'intégrité du transistor $Q_2$.

\subsubsection{Conception du schéma TCAN}

Un autre point majeur de la carte Hub est son système de communication avec les ancres.
Pour communiquer avec les ancres, nous avons choisi la solution TCAN, mais celle-ci
nécessite plusieurs mises en place structurelles que nous allons analyser.

\begin{figure}[H]
\centering 
 
\caption[Schéma de la communication CAN du Hub]{Schéma de la communication CAN du Hub}
\label{fig:sch-TCAN-hub}
\end{figure}

Le point central de cette communication est le transceiver CAN TCAN1051-Q1 \cite{TCAN1051-Q1},
que l'on peut voir sur la Figure \ref{fig:sch-TCAN-hub}. Son rôle principal est d'assurer 
l'adaptation des niveaux de tension entre le contrôleur logique et les lignes physiques 
différentielles du bus CAN.
Pour cela, il communique via une liaison UART avec le microcontrôleur, c'est-à-dire qu'il utilise
les broches TX et RX : 

 \begin{itemize}
    \item \textbf{Broche 1 (TXD - Transmit Data) :} Cette entrée reçoit le flux de données série logique provenant de la broche de transmission du microcontrôleur pour le convertir en signal différentiel sur le bus.
    \item \textbf{Broche 4 (RXD - Receive Data) :} Cette sortie renvoie les données lues sur le bus différentiel vers la broche de réception du microcontrôleur, après remise au niveau logique approprié.
 \end{itemize}

Celui-ci est alimenté en 5V, mais reçoit également du 3.3V.
Bien que le symbole indique \texttt{NC} (\textit{No Connect}), la broche est physiquement
câblée au rail \textbf{+3.3V} et associée à un condensateur. Sur les composants modernes, 
cette broche sert d'entrée de référence d'alimentation logique ($V_{IO}$).
Elle permet d'adapter les tensions des signaux logiques (TXD/RXD) pour communiquer directement
avec un microcontrôleur fonctionnant en $3.3\text{ V}$, éliminant ainsi le besoin de circuits
de conversion de niveau externes, ce qui est notre cas.

 \bigskip 
Et de l'autre côté du composant, on retrouve les trois broches primordiales pour la communication CAN, qui sont les
 suivantes : 

\begin{itemize}
    \item \textbf{Broche 6 (CANL - CAN Low) :} Ligne basse du bus différentiel.
    \item \textbf{Broche 7 (CANH - CAN High) :} Ligne haute du bus différentiel.
    \item \textbf{Broche 8 (S - Standby / Select) :} Broche de sélection de mode. Elle est reliée à la masse \texttt{GNDREF} via une résistance de pull-down $R_3 = 4.7\text{ k}\Omega$. Un niveau bas sur cette broche force le transceiver à opérer en mode normal (haute vitesse). La résistance $R_1$ garantit que le composant reste actif par défaut, même si le microcontrôleur ne pilote pas activement cette broche.
\end{itemize}

La stabilité des lignes d'alimentation est cruciale pour éviter l'injection de bruit sur le bus de données. 
Trois condensateurs de découplage sont installés. $C_1$ / $C_2$ sont connectés en parallèle entre le rail 
\textbf{+5V} et \texttt{GNDREF}, au plus près de la broche 3 (VCC). Ils filtrent les parasites haute fréquence 
et fournissent les pointes de courant locales instantanées lors des commutations d'état sur le bus.
$C_4$ est quant à lui connecté entre le rail \textbf{+3.3V} et \texttt{GNDREF}, il stabilise l'alimentation 
de référence de l'interface d'E/S logique (Broche 5).

Nous nous sommes basés sur les recommandations de la datasheet du TCAN \cite{TCAN1051-Q1}, en fonction
de nos besoins ainsi que du modèle utilisé (voir Figure \ref{fig:Datasheet-TCAN}).

\begin{figure}[!ht]
\centering 
 
\caption[Exemple de datasheet du TCAN]{Exemple de datasheet du TCAN}
\label{fig:Datasheet-TCAN}
\end{figure}

Pour prévenir les phénomènes de réflexion de signal en bout de ligne, 
un bus CAN doit être fermé à ses deux extrémités physiques par une résistance
correspondant à l'impédance caractéristique du câble (généralement $120\,\Omega$).
Nous pouvons constater sur la Figure \ref{fig:sch-TCAN-hub} la mise en œuvre de cette protection.
Nous avons donc mis en place, sur la communication CAN, $R_5$ et $JP_1$ pour éviter de potentiels échos sur la ligne de communication.

\begin{itemize}
    \item \textbf{Résistance $R_5$ :} Résistance de terminaison normalisée.
    \item \textbf{Cavalier $JP_1$ :} Ce cavalier permet d'activer ou de désactiver la présence de la résistance sur la ligne.
    \item \textbf{Règle d'usage :} Si ce Hub se trouve physiquement à l'extrémité du réseau CAN, le cavalier $JP_1$ doit être inséré (fermé) pour connecter $R_5$ en dérivation entre CANH et CANL. S'il s'agit d'un nœud intermédiaire, le cavalier doit rester ouvert pour ne pas surcharger l'impédance totale du bus (qui doit rester égale à $60\,\Omega$, soit deux terminaisons de $120\,\Omega$ en parallèle sur tout le réseau).
\end{itemize}

À l'extrême droite du schéma, deux connecteurs de type bornier à vis (\texttt{DB301V-5.0-2P}), dont $U_9$, sont câblés en parallèle :
\begin{itemize}
    \item La \textbf{Broche 1} de chaque connecteur est reliée à la ligne générale \textbf{CANH}.
    \item La \textbf{Broche 2} de chaque connecteur est reliée à la ligne générale \textbf{CANL}.
\end{itemize}
Cette mise en parallèle directe permet d'implémenter facilement une topologie en chaîne. Le câble de bus principal entre par l'un des connecteurs et ressort par le second vers le nœud suivant. Cela évite la création de dérivations en étoile trop longues, qui sont de fréquentes sources de problèmes d'impédance et d'erreurs de communication à des débits élevés.

\subsubsection{Conception des Capteurs}

La dernière partie de la carte concerne la récupération de données sur différents capteurs.
Un extrait du schéma est représenté sur la Figure \ref{fig:sch-BMP-BMIO-ESP32-ecran-hub}.

\begin{figure}[H]
\centering 
 
\caption[Schéma de communication BMIO/BMP/Écran du Hub]{Schéma de communication BMIO/BMP/Écran du Hub}
\label{fig:sch-BMP-BMIO-ESP32-ecran-hub}
\end{figure}

Sur la Figure \ref{fig:sch-BMP-BMIO-ESP32-ecran-hub}, on peut constater 4 éléments. Celui tout à droite représente
la carte ESP32-WROVER du Hub, celle qui s'occupe de récupérer toutes les données, aussi bien des capteurs
que du bus CAN. Il est alimenté en 5V et sort du 3.3V sur ses GPIO.

\bigskip
Le point intéressant à remarquer est le mode de communication des capteurs : le BMP581 \cite{BMP581} communique
en SPI et le BMIO88 \cite{} communique également en SPI. Nous sommes donc en droit de nous demander pourquoi
les deux ne communiquent pas sur les mêmes broches, sachant que la force du SPI est de pouvoir connecter plusieurs
esclaves avec un seul maître.

Le protocole \textbf{SPI} (\textit{Serial Peripheral Interface}) est un bus de communication série synchrone développé 
par Motorola au milieu des années 1980. Il est conçu pour des communications à courte distance,
principalement entre microcontrôleurs et circuits intégrés périphériques.

Le SPI fonctionne selon une architecture \textbf{Maître-Esclave} (\textit{Master-Slave}) et opère en 
mode \textbf{Full-Duplex}, ce qui signifie que les données peuvent être envoyées et reçues simultanément.
Une liaison SPI standard repose sur quatre lignes de signaux logiques :

\begin{itemize}
    \item \textbf{SCLK (Serial Clock) :} L'horloge générée exclusivement par le maître. Elle cadence la transmission des données bit par bit.
    \item \textbf{MOSI (Master Out Slave In) / SDO (Serial Data Out) :} La ligne de transmission de données du maître vers l'esclave.
    \item \textbf{MISO (Master In Slave Out) / SDI (Serial Data In) :} La ligne de transmission de données de l'esclave vers le maître.
    \item \textbf{SS / CS (Slave Select / Chip Select) :} Activée généralement à l'état bas (\textit{Active Low}), cette ligne est pilotée par le maître pour sélectionner l'esclave avec lequel il souhaite communiquer.
\end{itemize}

Pour revenir au vrai sujet, le BMIO nous permet de connaître le vecteur gravité
en temps réel, et nous voulons le connaître le plus rapidement et le plus souvent possible. Si jamais les deux capteurs
étaient sur le même bus SPI, il serait alors impossible d'interroger le BMIO à certains moments, car l'ESP32
serait en train de communiquer avec le BMP581 \cite{BMP581}.
Ils sont donc placés sur deux bus SPI différents pour minimiser le délai de réponse du BMIO.

\bigskip
Pour ce qui est du connecteur $J_1$ Grove-Mabee, il s'agit du connecteur permettant de relier l'écran au Hub.
Pour cela, nous utilisons les GPIO 32 et 33, en mode UART (Tx/Rx) pour communiquer les informations, avec une 
alimentation 5V. 

\bigskip
Tous ces schémas nous amènent à un schéma global, tel que présenté sur la Figure \ref{fig:sch-hub}.

\begin{figure}[!ht]
\centering 
 
\caption[Schéma du Hub]{Schéma du Hub}
\label{fig:sch-hub}
\end{figure}

\subsubsection*{Placement des composants}
Une fois le schéma validé, nous devons maintenant passer d'un symbole complètement théorique
à quelque chose qui représente le circuit imprimé le plus fidèlement possible.
Pour cela, nous utilisons le logiciel PCB de KiCad. 

\begin{figure}[!ht]
\centering 
 
\caption[Placement des composants]{Placement des composants}
\label{fig:PCB-Hub-placement}
\end{figure}

La première étape consiste à placer les composants sur la carte de manière intelligente.
Comme nous pouvons le voir sur la Figure \ref{fig:PCB-Hub-placement}, 
le placement des composants suit une logique fonctionnelle rigoureuse qui optimise le câblage externe et limite le bruit interne :
\begin{itemize}
    \item \textbf{Centralisation de l'intelligence (\texttt{U1}) :} Le support du microcontrôleur est positionné au centre, équilibré pour distribuer les signaux vers la périphérie de manière homogène.
    \item \textbf{Périphérie des interfaces (Connecteurs) :} Tous les borniers à vis (\texttt{U10, U3, U6, U7} en haut à gauche ; \texttt{U4, U9} en haut à droite) ainsi que le connecteur autodétrompé Grove (\texttt{J1}) sont alignés sur les bords de la carte. Cela facilite grandement le raccordement des faisceaux de câbles sans survoler les composants sensibles.
    \item \textbf{Proximité du découplage (\texttt{C2, C4}) :} Les condensateurs de filtrage CMS pour le transceiver CAN (\texttt{U2}) sont placés à l'immédiate proximité de ses broches d'alimentation. Cela réduit l'inductance parasite des pistes, garantissant l'efficacité du filtrage des harmoniques hautes fréquences.
    \item \textbf{Proximité du 12V :} Tous les composants prenant du 12V sont concentrés en une seule zone, pour éviter que du 12V ne se balade sur toute la carte.
\end{itemize}

\bigskip

\subsubsection*{Routage Top}

\begin{figure}[!ht]
\centering 
 
\caption[Mise en place du routage Top]{Mise en place du routage Top}
\label{fig:PCB-Hub-top}
\end{figure}

Une fois le placement des composants réalisé, il faut mettre en place le routage.
Pour cela, il existe des règles à respecter.
Toutes les pistes doivent respecter le routage à $45^\circ$. 
Les angles droits ($90^\circ$) sont totalement proscrits. Cela évite l'effet de « piège à acide »
lors de la gravure chimique industrielle du cuivre et limite les ruptures brutales d'impédance électromagnétique.

Les pistes associées à l'alimentation principale (provenant des borniers à vis situés à gauche, transitant par les diodes \texttt{D1}, \texttt{D3} et alimentant le Buzzer 12V \texttt{LS1}) présentent une largeur très importante de $1\text{ mm}$.
Le buzzer \texttt{LS1} et les charges inductives commutées consomment des pointes de courant non négligeables. Une piste large minimise la résistance linéique ($R = \rho \frac{L}{S}$), réduisant ainsi les chutes de tension ohmiques ($\Delta V = R \cdot I$) et l'échauffement des pistes par effet Joule.

Les pistes connectant le microcontrôleur central (\texttt{U1}) au contrôleur CAN
(\texttt{U2}), au connecteur Grove (\texttt{J1}) et aux connecteurs supérieurs sont
beaucoup plus fines ($0.4\text{ mm}$ et $0.8\text{ mm}$).

Ces lignes transportent des signaux de commande à très faible courant
(quelques milliampères). Réduire leur largeur permet un gain d'espace crucial 
pour passer entre les pastilles (\textit{pads}) des composants au pas de
$0.4\text{ mm}$ sans violer les règles d'isolement.

\subsubsection*{Routage Bottom}

Le routage bottom suit les mêmes règles de conception que le routage top, à trois exceptions 
près que je vais détailler.

\begin{figure}[H]
\centering 
 
\caption[Mise en place du routage bottom]{Mise en place du routage bottom}
\label{fig:PCB-Hub-bottom}
\end{figure}

La zone bleue représente un plan de masse plein et continu. Un plan de masse uniforme
offre une impédance de retour extrêmement faible pour les courants de signal,
ce qui réduit drastiquement les surfaces de boucles inductives et l'émission de 
parasites.
En observant attentivement les connexions à la masse
(par exemple, la broche 2 du bloc \texttt{GNDREF} à gauche ou la broche 4 en bas à gauche),
on s'aperçoit que les pastilles ne sont pas noyées directement dans la masse solide,
mais connectées via une croix de cuivre.
Ces structures sont des \textit{freins thermiques}. 
Lors du soudage, ils empêchent la chaleur du fer à souder de se dissiper instantanément
dans tout le plan de masse de la carte. Sans cela, la pastille n'atteindrait pas 
la température de fusion de l'étain, provoquant une « soudure sèche » défectueuse.
\bigskip

La quasi-totalité des pistes de signal reste cantonnée sur la couche supérieure rouge 
(\texttt{F.Cu}). Il y a très peu de trous de passage (\textit{vias}) de signal vers
le bottom (les pistes bleues). 

Le plan de masse inférieur bleu n'est pratiquement pas « sectionné » ou
fragmenté par des pistes de détournement. Un plan de masse non coupé garantit
qu'aucun courant de retour ne doit faire de long détour, évitant ainsi la création
d'antennes dipolaires involontaires.

Le tableau suivant résume les bonnes pratiques de la carte :

\begin{table}[h!]
\centering
\caption{Synthèse des choix technologiques du PCB}
\label{tab:synthese_pcb}
\begin{tabular}{lll}
\toprule
\textbf{Paramètre} & \textbf{Style Observé} & \textbf{Objectif Technique} \\
\midrule
Stackup & 2 couches (\texttt{F.Cu} + \texttt{B.Cu}) & Optimisation coût / performance CEM \\
Routage Alimentation & Pistes larges ($1\text{ mm}$+) & Faible résistance, support d'intensité (Buzzer) \\
Routage Signaux & Pistes fines ($0.4\text{ mm}$) & Densité spatiale \\
Angles de pistes & À $45^\circ$ uniquement & Intégrité du signal, fabricabilité chimique \\
Plan de masse & Continu sur la face \texttt{B.Cu} & Blindage CEM, réduction des impédances de retour \\
Pads de masse & Connexion en croix (\textit{Thermal Relief}) & Soudabilité parfaite à la main ou au four \\
\bottomrule
\end{tabular}
\end{table}

\subsubsection*{Layout complet}

Une fois tout le travail réalisé, il ne reste plus qu'à vérifier qu'il n'y a aucune erreur de DRC (Design Rule Check), 
à vérifier la sérigraphie (ce qui n'est pas notre cas, car l'école ne sait pas faire de sérigraphie),
ou encore la bonne liaison entre les différentes pastilles.

Cela nous permet d'obtenir la Figure \ref{fig:PCB-Hub-fini}.

\begin{figure}[H]
\centering 
 
\caption[Layout final du hub]{Layout final du hub}
\label{fig:PCB-Hub-fini}
\end{figure}

Ainsi que la modélisation 3D comme le montre la Figure \ref{fig:PCB-Hub-3D}.

\begin{figure}[H]
\centering 
 
\caption[Layout final du hub en 3D]{Layout final du hub en 3D}
\label{fig:PCB-Hub-3D}
\end{figure}

\subsection{Ancre}

Le schéma pour l'ancre est plus simple, soit la Figure \ref{fig:sch-ancre} :

\begin{figure}[H]
\centering 
 
\caption[Layout final de l'ancre]{Layout final de l'ancre}
\label{fig:sch-ancre}
\end{figure}

On y retrouve tout le module TCAN que l'on avait sur la Figure \ref{fig:sch-TCAN-hub},
avec le TCAN1051-Q1 \cite{TCAN1051-Q1}.

La seule nouveauté réside dans le nouveau microcontrôleur, qui n'impacte que la partie
logicielle, et dans le nouvel abaisseur de tension, qui est un OKI-78SR \cite{OKI-78SR_Series}.
Compact et facile à mettre en œuvre, il s'agit d'un abaisseur 12V $\rightarrow$ 5V.
De plus, on retrouve un condensateur de $10\,\mu\text{F}$, donc plus gros que d'habitude, pour éviter
tout potentiel arrêt de l'ESP32. Les ancres étant alimentées en 12V par le bus CAN, et pouvant se situer 
à une distance de plus de 50 mètres, il est plus prudent de mettre un condensateur de découplage pour parer tout problème.

\bigskip
Cela donne lieu à la Figure \ref{fig:PCB-ancre}.
Les règles de conception et la manière de faire sont les mêmes, avec les borniers
du même côté, un plan de masse le plus uniforme possible ou encore la taille des pistes
d'alimentation.

\begin{figure}[!ht]
\centering 
 
\caption[Layout final de l'ancre]{Layout final de l'ancre}
\label{fig:PCB-ancre}
\end{figure}

\begin{figure}[H]
\centering 
 
\caption[3D de l'ancre]{3D de l'ancre}
\label{fig:PCB-ancre-3D}
\end{figure}

\subsection{Ouvrier}

Pour l'ouvrier, le schéma électrique est différent sur plusieurs aspects.
Comme dit précédemment, nous cherchons à faire la carte la plus petite possible,
le tout étant alimenté à l'aide d'une batterie. 
Nous avons donc mis en place le schéma suivant, représenté sur la Figure \ref{fig:sch-ouvrier}.

\begin{figure}[H]
\centering 
 
\caption[Schéma de l'ouvrier]{Schéma de l'ouvrier}
\label{fig:sch-ouvrier}
\end{figure}
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

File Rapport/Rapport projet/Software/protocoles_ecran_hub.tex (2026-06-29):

\newpage
\subsubsection{Protocoles Wi-Fi et UART}

L'ESP32 intégré à l'écran agit comme une passerelle matérielle et logicielle entre l'interface utilisateur web et le Hub principal, en s'appuyant sur deux canaux de communication : l'UART et le Wi-Fi.

\paragraph{Communication matérielle UART}
La liaison série entre l'écran et le Hub s'effectue sur le port \texttt{Serial2} (RX : broche 19, TX : broche 20) à une vitesse de \texttt{115200 bauds}. 

L'intégralité des échanges de données se fait au format JSON. Certaines trames, notamment celles contenant la géométrie de calibration, étant particulièrement volumineuses, les mémoires tampons matérielles et logicielles ont été étendues à 4096 octets via \texttt{Serial2.setRxBufferSize()} et \texttt{uart\_buffer.reserve()}. Une sécurité anti-débordement est implémentée : si le buffer se remplit sans recevoir le caractère de fin de chaîne (\texttt{'\textbackslash n'}), les données sont purgées pour éviter un crash mémoire.
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

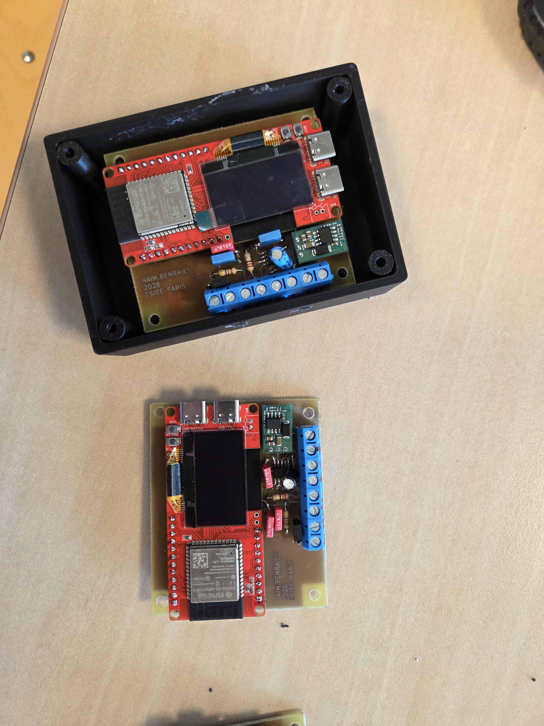
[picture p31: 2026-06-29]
Rapport/Rapport projet/Figures/carte-ancre.jpg

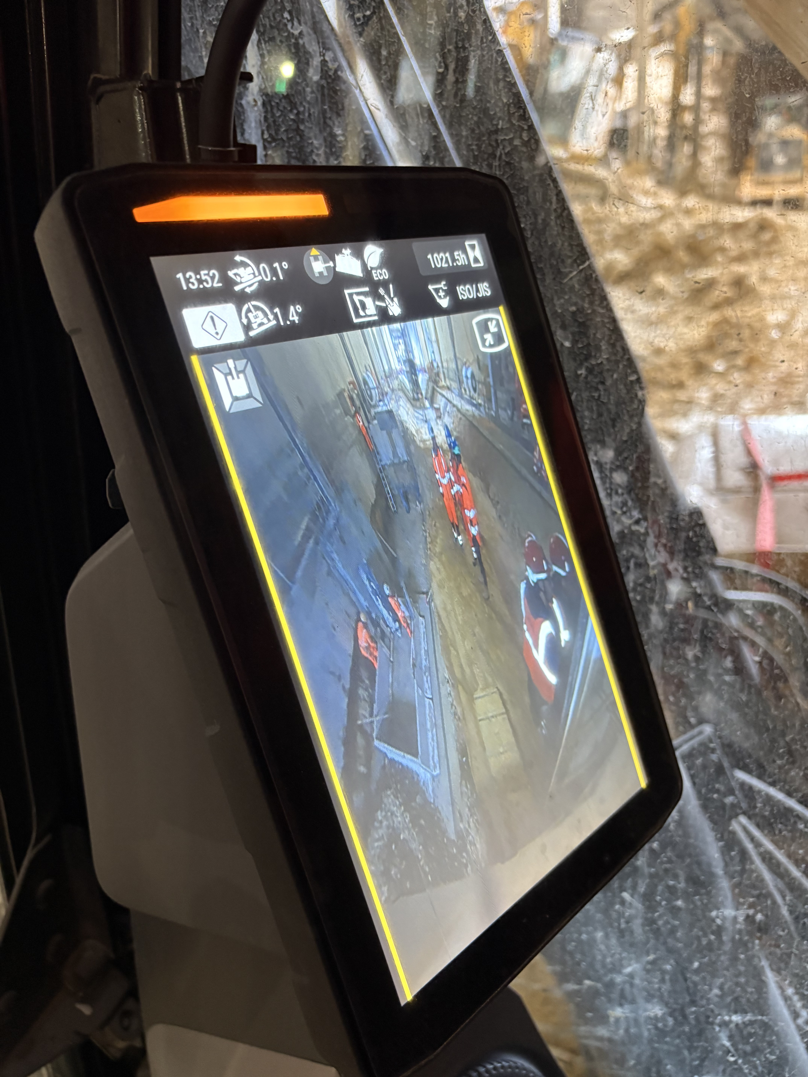
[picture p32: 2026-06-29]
Rapport/Rapport projet/Figures/Chantier5.jpg

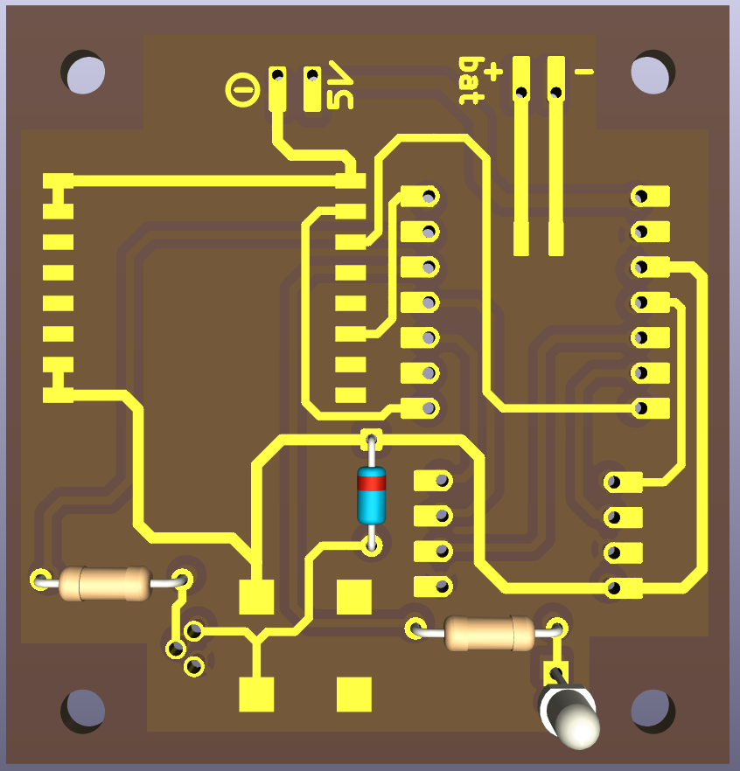
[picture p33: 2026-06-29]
Rapport/Rapport projet/Figures/PCB-ouvrier-3D.png

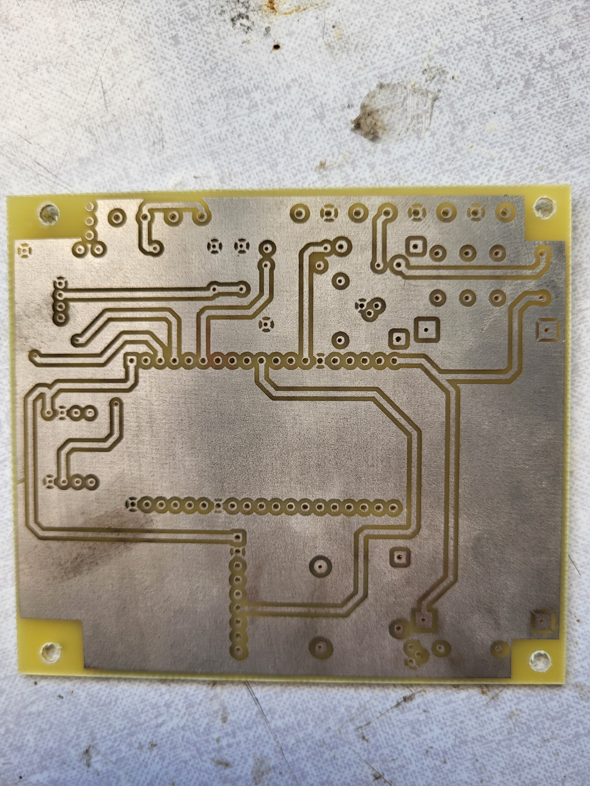
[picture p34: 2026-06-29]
Rapport/Rapport projet/Figures/carte-hub-verso.jpg

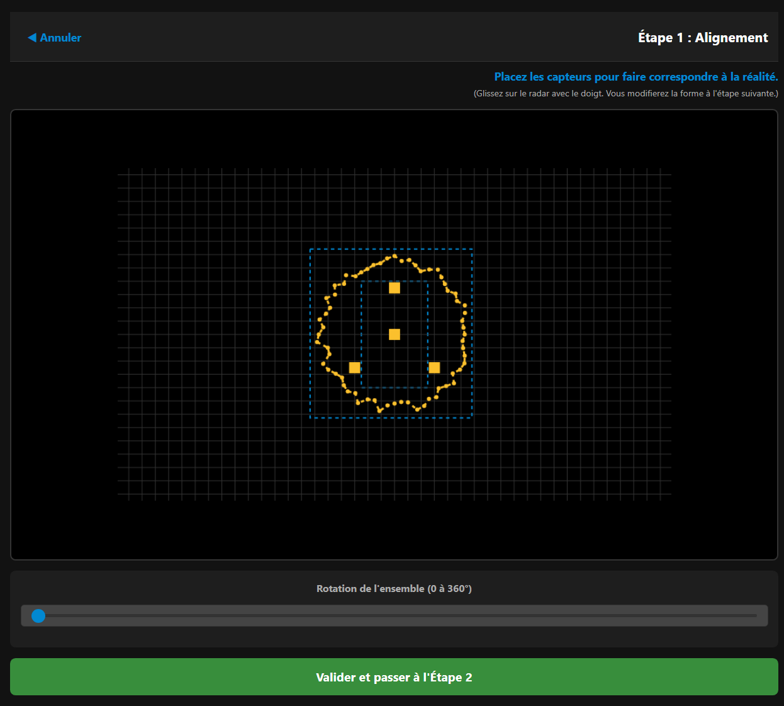
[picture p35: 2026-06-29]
Rapport/Rapport projet/Figures/ui_align.png

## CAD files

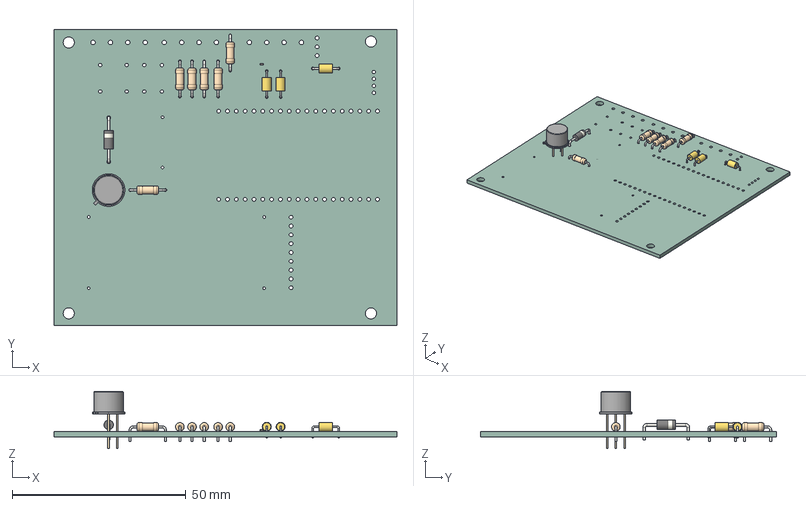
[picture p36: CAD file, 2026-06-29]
PCB/Hub/hub.step
98.8 x 85.2 x 16.5 mm
R_Axial_DIN0207_L63mm_D25mm_P1016mm_Horizontal x 6
C_Axial_L38mm_D26mm_P750mm_Horizontal x 3
TO-39-3
C_0402_1005Metric
D_DO-41_SOD81_P12.70mm_Horizontal
HUB2_PCB

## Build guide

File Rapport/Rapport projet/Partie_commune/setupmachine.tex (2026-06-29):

L'installation matérielle du dispositif sur l'engin de chantier est la première étape permettant de déployer le prototype. Ce processus se divise entre l'équipement extérieur de la machine pour les capteurs et l'aménagement intérieur de la cabine pour l'interface de contrôle.

\subsubsection{Déploiement géométrique des ancres}

Pour permettre un calcul spatial en trois dimensions $(x, y, z)$, la disposition physique des quatre ancres UWB sur le véhicule doit respecter des critères de positionnement précis :

\begin{itemize}
    \item \textbf{Configuration en tétraèdre :} Les quatre ancres ne doivent pas être situées sur un même plan horizontal. Elles doivent former un tétraèdre dans l'espace (avec un décalage en hauteur). Cette configuration en relief est indispensable pour que le système puisse évaluer correctement la position du tag.
    \item \textbf{Maximisation de l'espacement :} Les ancres doivent être fixées aux extrémités de la structure du véhicule (par exemple : aux quatre coins hauts et bas de la machine). Un espacement maximal réduit les incertitudes géométriques et optimise la précision des mesures.
    \item \textbf{Dégagement du champ de vision :} La technologie nécessite une ligne de vue directe entre les capteurs et l'environnement extérieur. Les modules doivent être placés de manière à ne pas être masqués par les éléments métalliques de l'engin (bras articulé, tourelle, godet) afin d'éviter le blocage ou la réflexion des signaux.
\end{itemize}

\subsubsection{Installation du Hub et de l'Interface en cabine}

L'unité centrale de calcul (le Hub) et l'écran tactile d'interface sont installés à l'intérieur de la cabine du conducteur pour répondre aux critères suivants :

\begin{itemize}
    \item \textbf{Ergonomie et sécurité :} L'écran tactile est positionné dans le champ de vision du conducteur sans obstruer sa visibilité extérieure, permettant de consulter le radar et de percevoir immédiatement les alertes visuelles.
    \item \textbf{Protection environnementale :} Le placement en cabine protège le Hub et l'écran des intempéries, de la poussière et des vibrations extrêmes subies par le châssis extérieur.
\end{itemize}

\subsubsection{Mise en route et procédure de calibration}

Une fois le matériel en place, l'activation du système s'effectue par une pression sur un bouton d'alimentation unique. L'écran tactile s'allume alors automatiquement et affiche une instruction claire invitant l'opérateur à se connecter au réseau Wi-Fi local de l'écran pour configurer ou ajouter une configuration de véhicule.

Pour paramétrer la zone de sécurité, l'utilisateur se connecte au point d'accès Wi-Fi avec son terminal mobile afin d'accéder à l'interface de configuration. Durant la phase d'enregistrement de la zone (marche de calibration autour de la machine avec le Tag), l'opérateur doit impérativement rester sur le même plan horizontal que le véhicule. Conserver cette régularité d'altitude au niveau du sol de référence est nécessaire pour que la géométrie de la zone de sécurité enregistrée soit plane et conforme au périmètre réel de l'engin, sans introduire de variations de hauteur aberrantes qui fausseraient la configuration initiale.

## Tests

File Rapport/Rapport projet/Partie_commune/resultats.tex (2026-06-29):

Afin de valider l'architecture logicielle, les algorithmes mathématiques et la communication entre les différents modules, une Preuve de Concept a été réalisée en environnement contrôlé. Lors de ce test, on a pu évaluer la précision brute, la réactivité de l'interface utilisateur et la fiabilité du déclenchement des alertes, indépendamment des perturbations inhérentes à un chantier réel.

\subsubsection{Protocole de test et mise en situation}

Pour respecter les contraintes géométriques indispensables au calcul tridimensionnel, les quatre ancres UWB ont été fixées sur des supports cartonnés disposés de manière à reproduire le volume d'une machine et à former un tétraèdre asymétrique (non coplanaire). L'écran de contrôle et le Hub ont été installés sur une table simulant la cabine de pilotage.

\begin{figure}[H]
\centering 
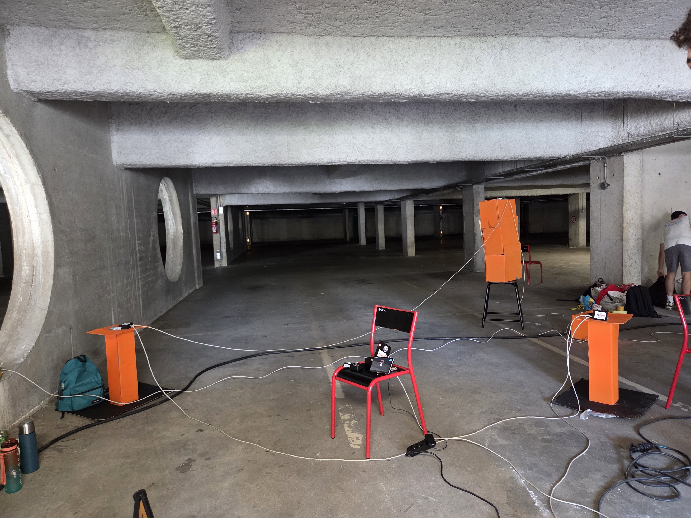
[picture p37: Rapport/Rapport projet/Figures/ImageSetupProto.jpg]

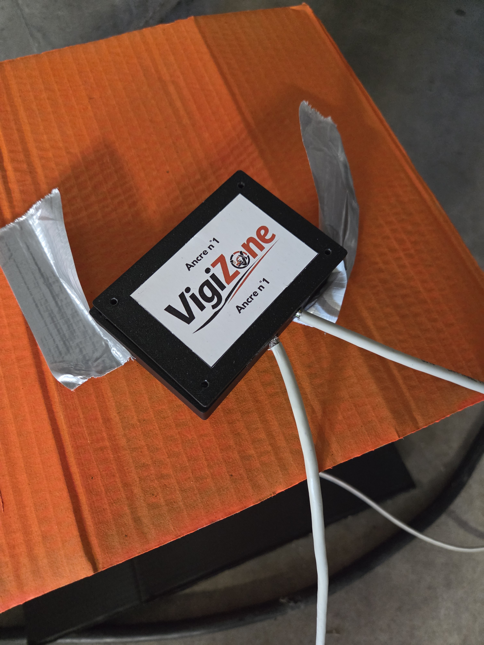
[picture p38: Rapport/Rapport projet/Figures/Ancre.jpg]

\caption[Installation du prototype en salle]{Dispositif de test en environnement contrôlé : simulation de l'engin par des supports cartonnés pour valider la géométrie en tétraèdre.}
\end{figure}

Les essais ont consisté à faire évoluer une personne muni d'un Tag autour de cette structure simulée, selon différentes trajectoires (approches frontales, déplacements latéraux, variations de vitesse) afin d'évaluer le comportement du système face à des cas d'usage standards.

\subsubsection{Analyse du suivi spatial}

Les données récoltées lors de ces simulations valident le fonctionnement nominal de la chaîne d'acquisition et de traitement :

\begin{itemize}
    \item \textbf{Précision de la détection UWB :} Dans ce milieu dépourvu de masses métalliques denses, l'algorithme des moindres carrés a calculé la position de l'opérateur avec une excellente précision. Le suivi des déplacements s'est avéré fluide et stable.
    \item \textbf{Traitement et affichage radar :} Les communications se sont bien déroulées. Le Tag a été retranscrit sur la vue de dessus avec des proportions exactes par rapport à la structure cartonnée simulée, démontrant l'indépendance de l'affichage par rapport aux variations d'altitude du capteur.
\end{itemize}

\begin{figure}[H]
\centering 
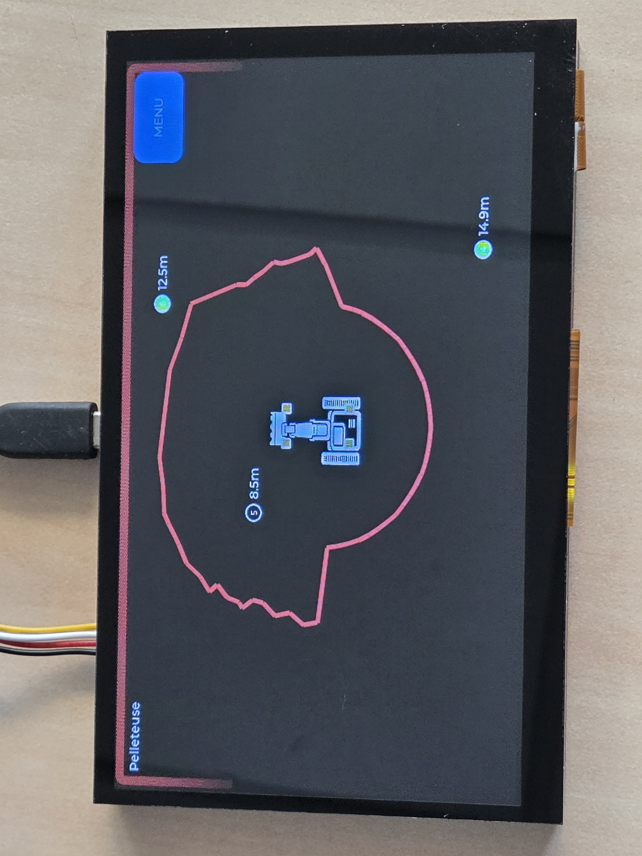
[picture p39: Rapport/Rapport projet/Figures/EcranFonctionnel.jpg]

\caption[Affichage radar en test]{Interface de l'écran affichant en temps réel le suivi de personnes}
\end{figure}

\subsubsection{Validation de la chaîne de sécurité}

L'évaluation de la fonctionnalité d'alerte critique a constitué la dernière phase du test. Une zone d'exclusion virtuelle a d'abord été créée autour de la structure simulée. L'opérateur a ensuite été invité à franchir volontairement cette frontière numérique avec son Tag. Le système a réagi sans latence perceptible, déclenchant simultanément l'alerte visuelle et sonore, et enregistrant l'événement dans le fichier d'historique sur la carte SD.

Si des tests ultérieurs sur un véritable engin (soumis aux réflexions de signaux dues à la carrosserie) demeurent nécessaires pour valider le produit fini, cette Preuve de Concept en salle confirme que le socle mathématique, la communication inter-microcontrôleurs et le logiciel d'interface répondent intégralement aux objectifs fixés.

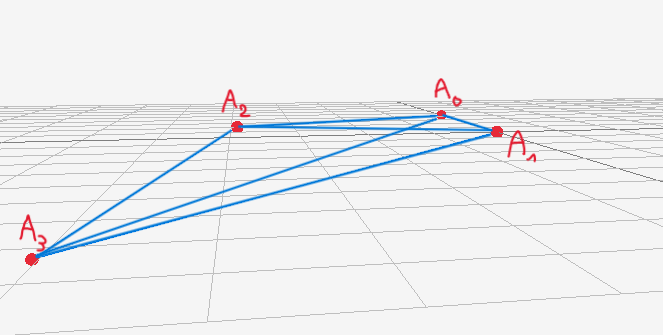
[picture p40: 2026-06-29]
Rapport/Rapport projet/Figures/calibrage_ancres.png

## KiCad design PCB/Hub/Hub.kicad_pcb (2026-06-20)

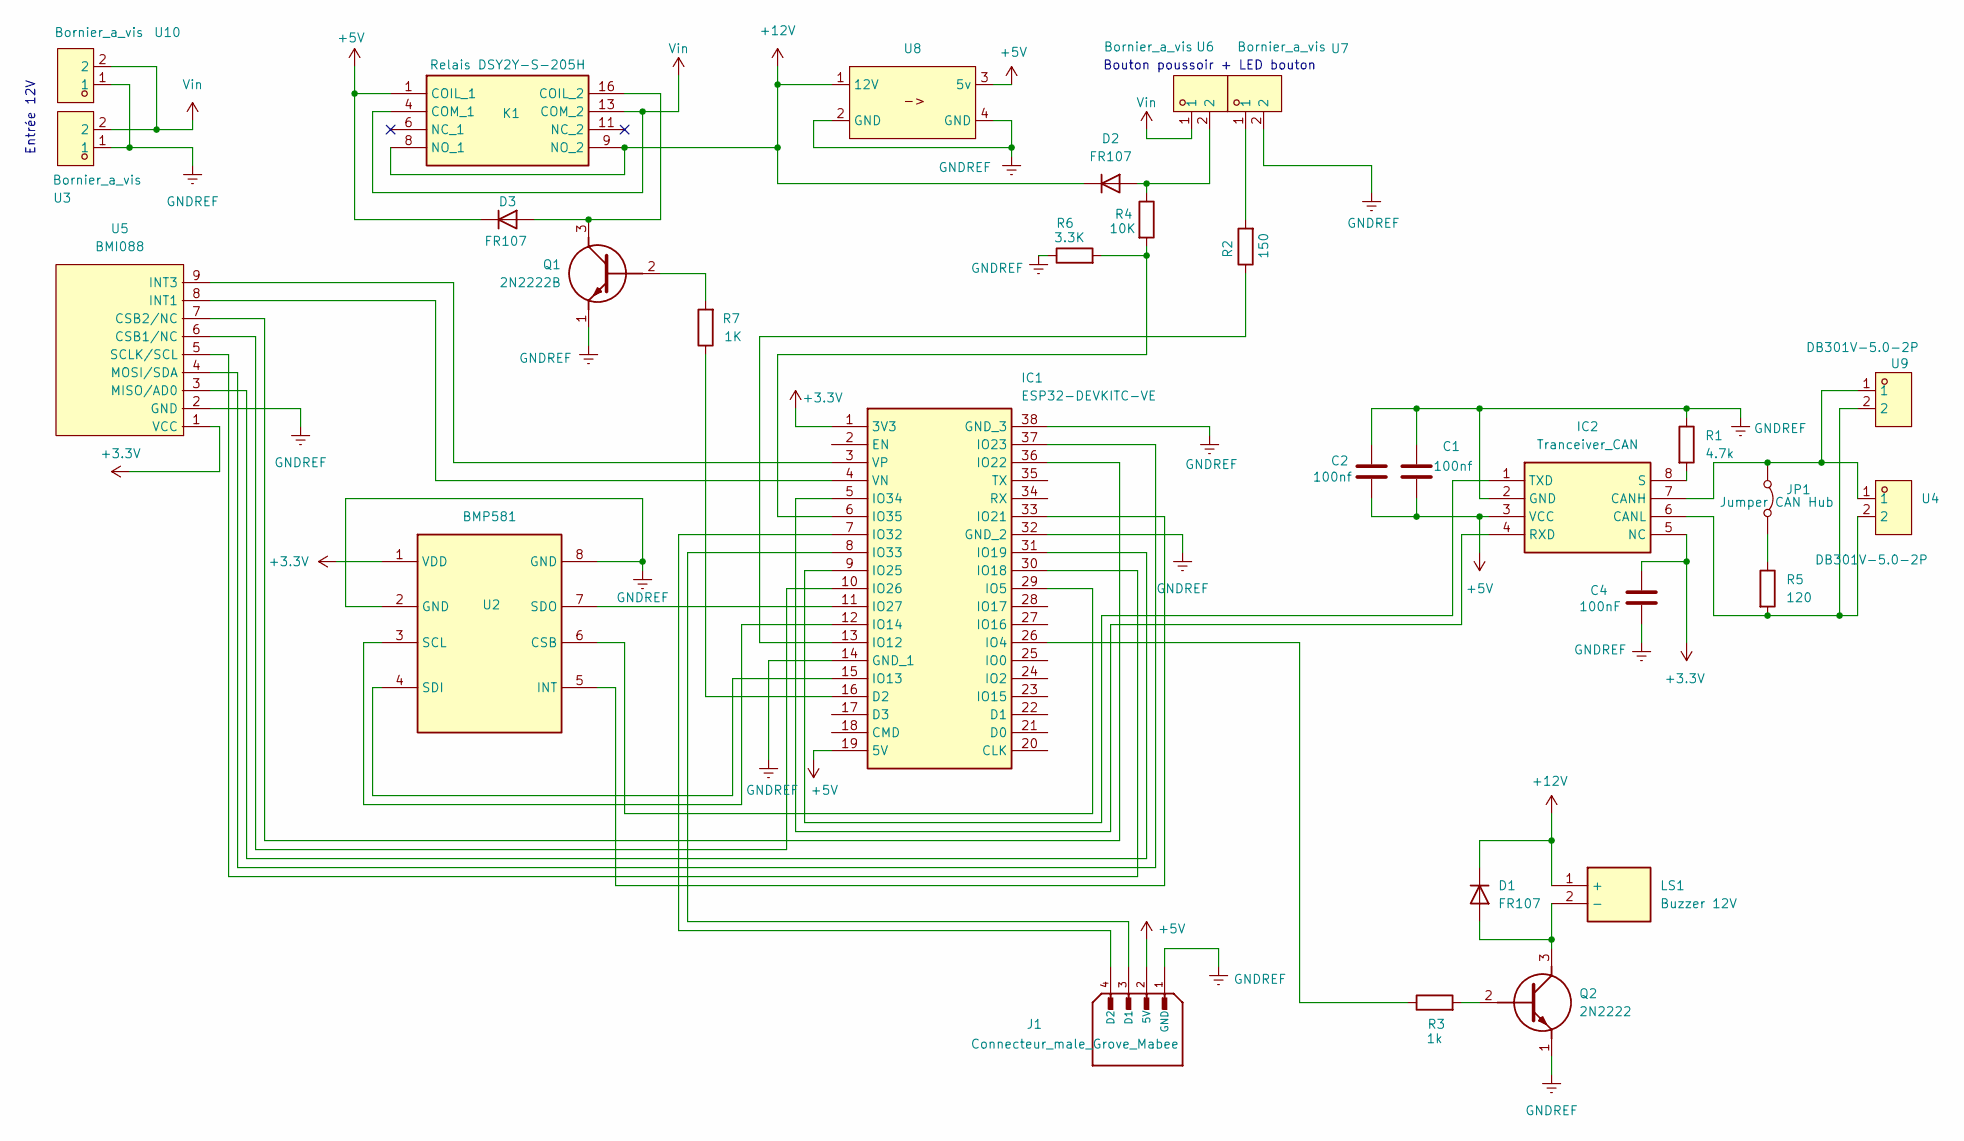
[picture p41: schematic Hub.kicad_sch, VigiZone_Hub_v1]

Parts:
C1, C2: 100nf; C_Axial_L3.8mm_D2.6mm_P7.50mm_Horizontal
C4: 100nF; C_0402_1005Metric_Pad0.74x0.62mm_HandSolder
D1, D2, D3: FR107; Diode FR107
IC1: ESP32-DEVKITC-VE; ESP32-WROVER DevKitC; Manufacturer_Part_Number ESP32-DEVKITC-VE; Mouser Part Number 356-ESP32-DEVKTC32VE
IC2: Tranceiver_CAN; Tranceiver CAN; Manufacturer_Part_Number TCAN1051VDRQ1; Mouser Part Number 595-TCAN1051VDRQ1
J1: Connecteur_male_Grove_Mabee; Connecteur male Grove_Mabee; PARTREV N/A
JP1: Jumper CAN Hub; Jumper CAN hub
K1: Relais DSY2Y-S-205H; Manufacturer_Part_Number DSY2Y-S-205L
LS1: Buzzer 12V; Manufacturer_Part_Number CMT-8504-100-SMT-TR; Mouser Part Number 490-CMT-8504100SMTTR
Q1: 2N2222B; Mouser Part Number 637-2N2222A
Q2: 2N2222; 2N2222B; Mouser Part Number 637-2N2222A
R1: 4.7k; R_Axial_DIN0207_L6.3mm_D2.5mm_P10.16mm_Horizontal
R2: 150; R_Axial_DIN0207_L6.3mm_D2.5mm_P10.16mm_Horizontal
R3: 1k; R_Axial_DIN0207_L6.3mm_D2.5mm_P10.16mm_Horizontal
R4: 10K; R_Axial_DIN0207_L6.3mm_D2.5mm_P10.16mm_Horizontal
R5: 120; R_Axial_DIN0207_L6.3mm_D2.5mm_P10.16mm_Horizontal
R6: 3.3K; R_Axial_DIN0207_L6.3mm_D2.5mm_P10.16mm_Horizontal
R7: 1K; R_Axial_DIN0207_L6.3mm_D2.5mm_P10.16mm_Horizontal
U2: BMP581; Manufacturer_Part_Number BMP581; Mouser Part Number 262-BMP581
U3, U6, U7, U10: Bornier_a_vis; Bornier a vis; MPN DB301V-5.0-2P-BU-S; LCSC Part C395882
U4, U9: DB301V-5.0-2P; Bornier a vis; MPN DB301V-5.0-2P-BU-S; LCSC Part C395882
U5: BMI088
U8: Abaisseur tension reglable

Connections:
+3.3V: C4.1, IC1.1 (3V3), IC2.5 (NC), U2.1 (VDD), U5.1 (VCC)
+5V: C1.2, C2.2, D3.1 (K), IC1.19 (5V), IC2.3 (VCC), J1.2 (5V), K1.1 (COIL_1), U8.3 (5v)
+12V: D1.1 (K), D2.1 (K), K1.8 (NO_1), K1.9 (NO_2), LS1.1 (+), U8.1 (12V)
GNDREF: C1.1, C2.1, C4.2, IC1.14 (GND_1), IC1.32 (GND_2), IC1.38 (GND_3), IC2.2 (GND), J1.1 (GND), Q1.1 (E), Q2.1 (E), R1.1, R6.1, U2.2 (GND), U2.8 (GND), U3.1, U5.2 (GND), U7.2, U8.2 (GND), U8.4 (GND), U10.1
unnamed: D1.2 (A), LS1.2 (-), Q2.3 (C)
unnamed: D2.2 (A), R4.1, U6.2
unnamed: D3.2 (A), K1.16 (COIL_2), Q1.3 (C)
unnamed: IC1.16 (D2), R7.1
unnamed: IC1.26 (IO4), R3.1
unnamed: IC1.29 (IO5), U2.6 (CSB)
unnamed: IC1.13 (IO12), R2.1
unnamed: IC1.15 (IO13), U2.4 (SDI)
unnamed: IC1.12 (IO14), U2.3 (SCL)
unnamed: IC1.30 (IO18), U5.5 (SCLK/SCL)
unnamed: IC1.31 (IO19), U5.3 (MISO/AD0)
unnamed: IC1.33 (IO21), U2.5 (INT)
unnamed: IC1.36 (IO22), U5.7 (CSB2/NC)
unnamed: IC1.37 (IO23), U5.4 (MOSI/SDA)
unnamed: IC1.9 (IO25), IC2.1 (TXD)
unnamed: IC1.10 (IO26), U5.6 (CSB1/NC)
unnamed: IC1.11 (IO27), U2.7 (SDO)
unnamed: IC1.7 (IO32), J1.4 (D2)
unnamed: IC1.8 (IO33), J1.3 (D1)
unnamed: IC1.5 (IO34), IC2.4 (RXD)
unnamed: IC1.6 (IO35), R4.2, R6.2
unnamed: IC1.4 (VN), U5.8 (INT1)
unnamed: IC1.3 (VP), U5.9 (INT3)
unnamed: IC2.7 (CANH), JP1.1 (A), U4.1, U9.1
unnamed: IC2.6 (CANL), R5.2, U4.2, U9.2
unnamed: IC2.8 (S), R1.2
unnamed: JP1.2 (B), R5.1
unnamed: Q1.2 (B), R7.2
unnamed: Q2.2 (B), R3.2
unnamed: R2.2, U7.1
Vin: K1.4 (COM_1), K1.13 (COM_2), U3.2, U6.1, U10.2

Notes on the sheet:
Entrée 12V
Bouton poussoir + LED bouton

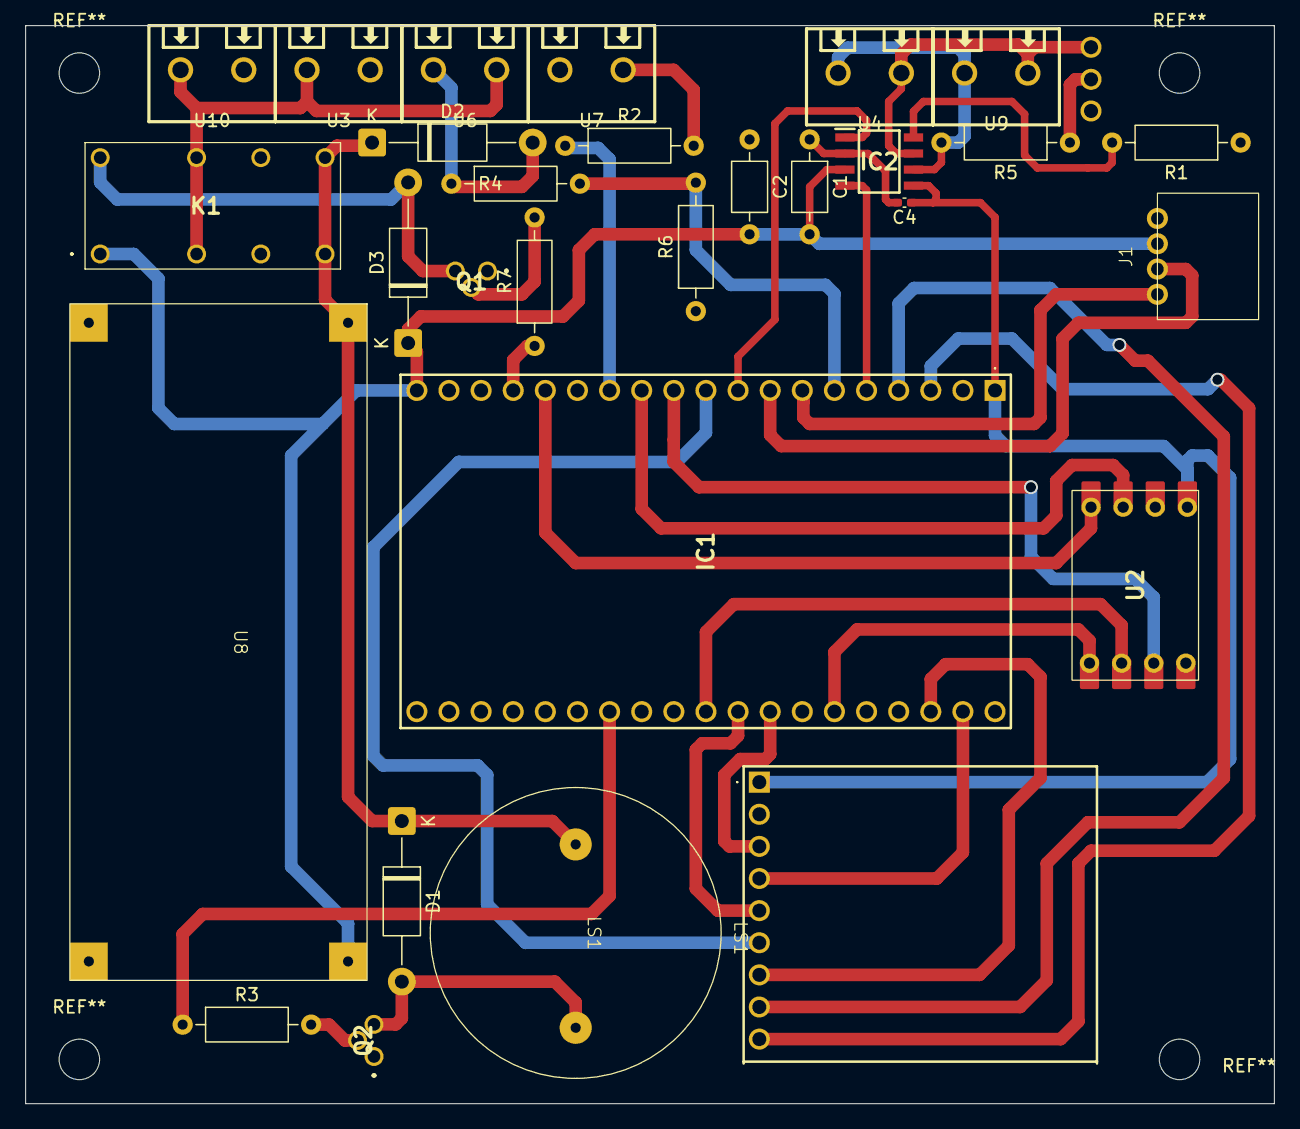
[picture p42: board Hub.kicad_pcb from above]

Board: 2 copper layers, 98.8 x 85.2 mm, 30 parts (0 on the bottom side), 35 nets.

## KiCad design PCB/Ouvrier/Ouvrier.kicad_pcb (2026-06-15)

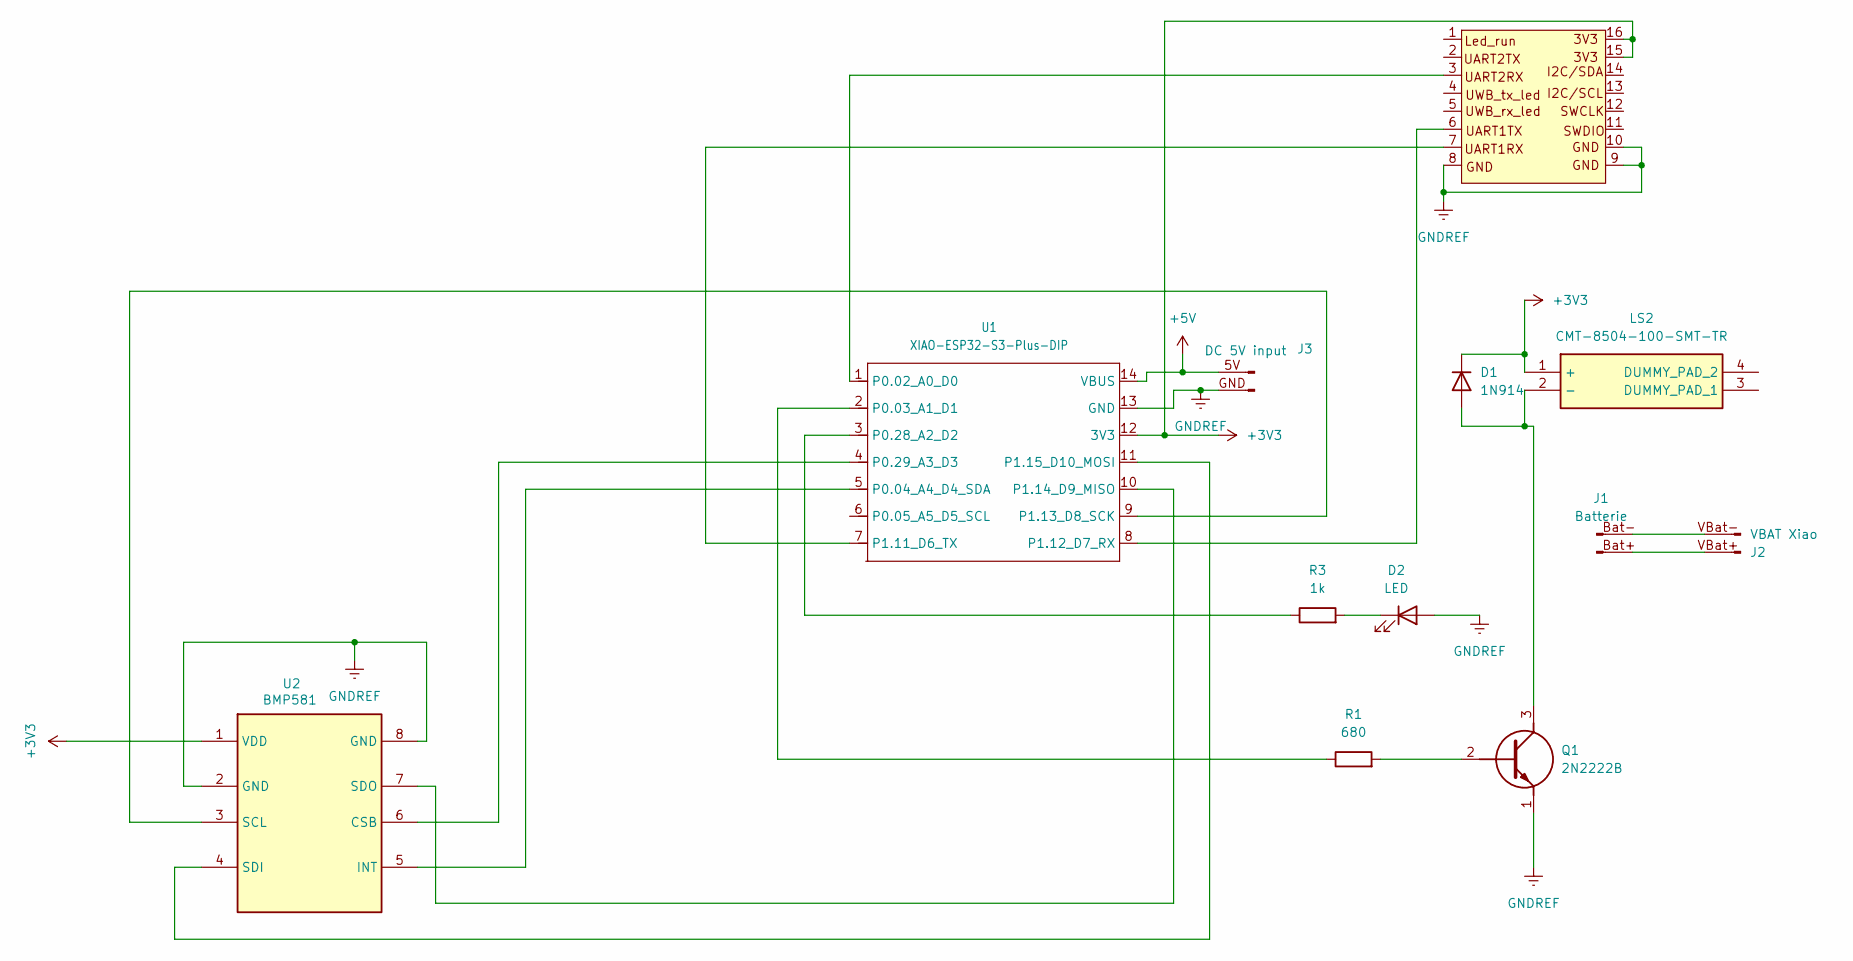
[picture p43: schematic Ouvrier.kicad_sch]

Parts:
D1: 1N914; D_DO-35_SOD27_P7.62mm_Horizontal
D2: LED; LED_D3.0mm_Clear
J1: Batterie
J2: VBAT Xiao; Raccord VBat XIAO
J3: DC 5V input; chargeur sans fil
LS2: CMT-8504-100-SMT-TR; Buzzer CMS; Manufacturer_Part_Number CMT-8504-100-SMT-TR; Mouser Part Number 490-CMT-8504100SMTTR
Q1: 2N2222B; Mouser Part Number 637-2N2222A
R1: 680; R_Axial_DIN0207_L6.3mm_D2.5mm_P10.16mm_Horizontal
R3: 1k; R_Axial_DIN0207_L6.3mm_D2.5mm_P10.16mm_Horizontal
U1: XIAO-ESP32-S3-Plus-DIP; XIAO nRF52840 sense plus
U2: BMP581; Manufacturer_Part_Number BMP581; Mouser Part Number 262-BMP581
U3: UWB; maUWB chipset

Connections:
+3V3: D1.1 (K), LS2.1 (+), U1.12 (3V3), U2.1 (VDD), U3.15 (3V3), U3.16 (3V3)
+5V: J3.5V (GND), U1.14 (VBUS)
GNDREF: D2.2 (A), J3.GND, Q1.1 (E), U1.13 (GND), U2.2 (GND), U2.8 (GND), U3.8 (GND), U3.9 (GND), U3.10 (GND)
unnamed: D1.2 (A), LS2.2 (-), Q1.3 (C)
unnamed: D2.1 (K), R3.2
unnamed: J1.Bat- (Pin_1), J2.VBat-
unnamed: J1.Bat+ (Pin_2), J2.VBat+
unnamed: Q1.2 (B), R1.2
unnamed: U1.1 (P0.02_A0_D0), U3.3 (UART2RX)
unnamed: R1.1, U1.2 (P0.03_A1_D1)
unnamed: U1.5 (P0.04_A4_D4_SDA), U2.5 (INT)
unnamed: R3.1, U1.3 (P0.28_A2_D2)
unnamed: U1.4 (P0.29_A3_D3), U2.6 (CSB)
unnamed: U1.7 (P1.11_D6_TX), U3.7 (UART1RX)
unnamed: U1.8 (P1.12_D7_RX), U3.6 (UART1TX)
unnamed: U1.9 (P1.13_D8_SCK), U2.3 (SCL)
unnamed: U1.10 (P1.14_D9_MISO), U2.7 (SDO)
unnamed: U1.11 (P1.15_D10_MOSI), U2.4 (SDI)

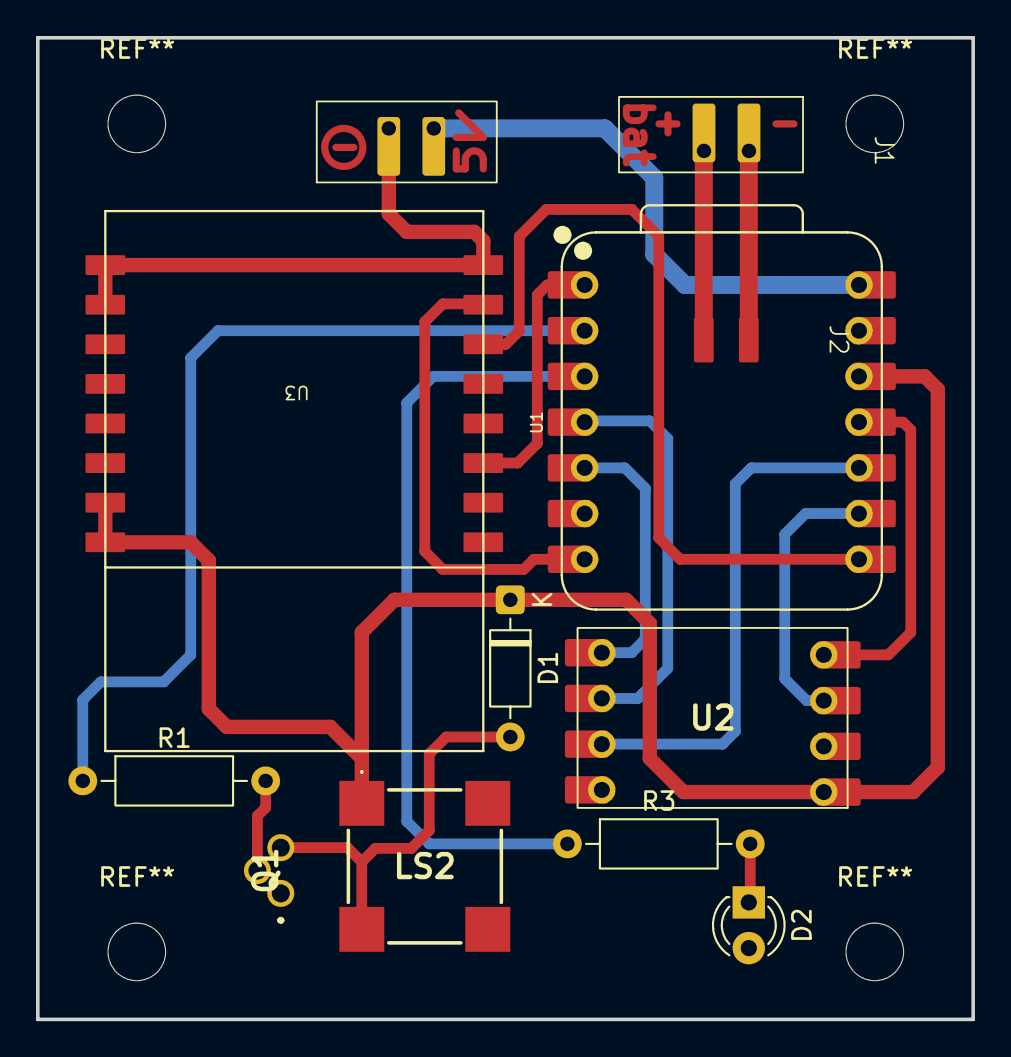
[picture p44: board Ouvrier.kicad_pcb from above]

Board: 2 copper layers, 52.0 x 54.5 mm, 12 parts (0 on the bottom side), 18 nets.

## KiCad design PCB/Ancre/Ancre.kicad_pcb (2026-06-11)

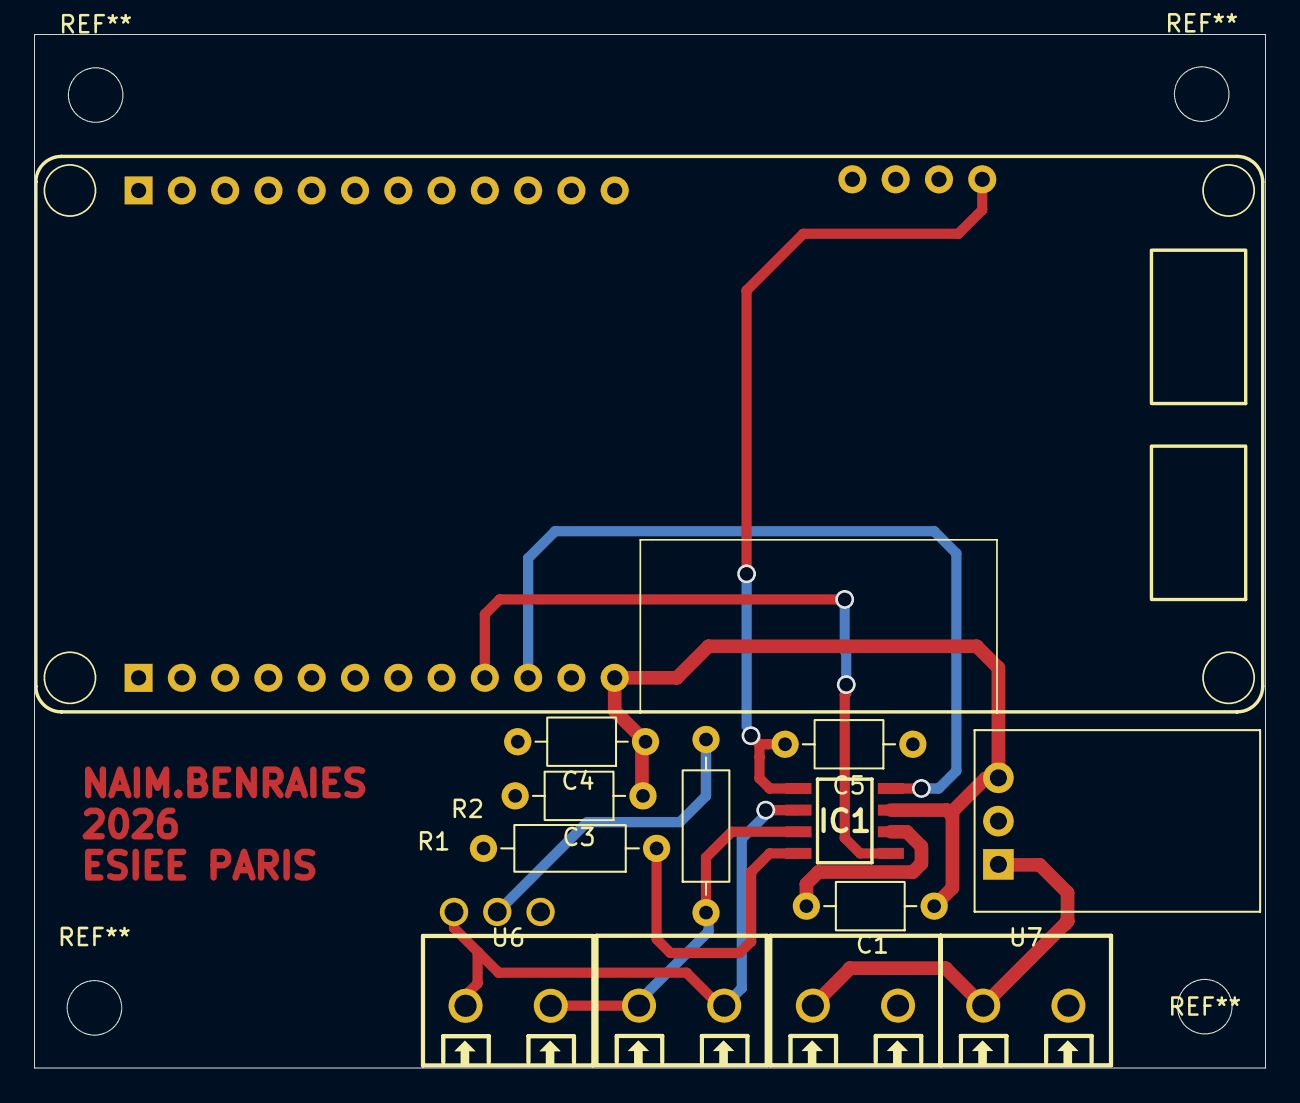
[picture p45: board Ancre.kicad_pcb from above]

Board: 2 copper layers, 72.2 x 60.7 mm, 14 parts (0 on the bottom side), 10 nets.

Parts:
C1: 10uF; C_Axial_L3.8mm_D2.6mm_P7.50mm_Horizontal
C3, C4, C5: 100nF; C_Axial_L3.8mm_D2.6mm_P7.50mm_Horizontal
IC1: TCAN1051VDRQ1; SOIC127P600X175-8N (1)
R1: R; R_Axial_DIN0207_L6.3mm_D2.5mm_P10.16mm_Horizontal
R2: 120; R_Axial_DIN0207_L6.3mm_D2.5mm_P10.16mm_Horizontal
U1: OKI-78SR-5_1.5-W36-C; Abaisseur 5v OKI
U2, U3: DB301V-5.0-2P; CONN-TH_2P-P5.00_L7.6-W10.0 (1)
U4: maUWB ESP32-S3 AT
U5: JUMPER CAN
U6, U7: DB301V-5.0-2P; Bornier a vis

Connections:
+5V: C1.1, C3.1, C4.1, IC1.3 (VCC), U1.3 (OUT), U4.13 (VDD)
+12V: U1.1 (IN), U2.1, U7.1
GNDREF: C1.2, C3.2, C4.2, C5.1, IC1.2 (GND), R1.2, U1.2 (GND), U2.2, U4.2 (GND), U4.14 (GND), U4.25 (GND), U7.2
unnamed: IC1.7 (CANH), R2.1, U3.1, U6.2
unnamed: IC1.6 (CANL), U3.2, U5.J2 (CAN_line), U6.1
unnamed: C5.2, IC1.5 (NC), U4.28 (3V3)
unnamed: IC1.4 (RXD), U4.15 (RXD)
unnamed: IC1.8 (S), R1.1
unnamed: IC1.1 (TXD), U4.16 (TXD)
unnamed: R2.2, U5.J1 (Resistance)

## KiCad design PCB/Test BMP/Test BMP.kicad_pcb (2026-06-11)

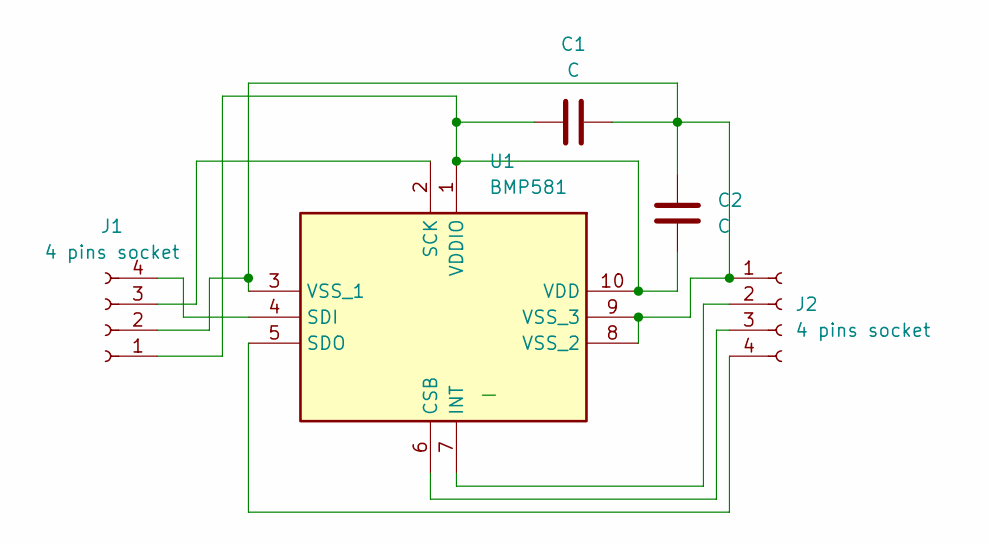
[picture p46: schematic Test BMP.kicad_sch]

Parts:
C1, C2: C; C_0402_1005Metric_Pad0.74x0.62mm_HandSolder
J1, J2: 4 pins socket
U1: BMP581; Manufacturer_Part_Number BMP581; Mouser Part Number 262-BMP581

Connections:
unnamed: C1.2, C2.2, J1.1, U1.1 (VDDIO), U1.10 (VDD)
unnamed: C1.1, C2.1, J1.2, J2.1, U1.3 (VSS_1), U1.8 (VSS_2), U1.9 (VSS_3)
unnamed: J1.3, U1.2 (SCK)
unnamed: J1.4, U1.4 (SDI)
unnamed: J2.2, U1.7 (INT)
unnamed: J2.3, U1.6 (CSB)
unnamed: J2.4, U1.5 (SDO)

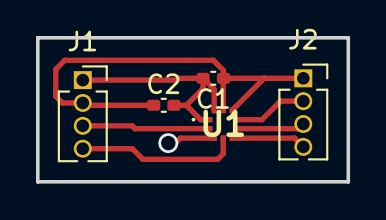
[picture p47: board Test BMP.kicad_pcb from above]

Board: 2 copper layers, 17.2 x 8.0 mm, 5 parts (0 on the bottom side), 7 nets.

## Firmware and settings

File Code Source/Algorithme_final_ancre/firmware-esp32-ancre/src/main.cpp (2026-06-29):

#include <Arduino.h>

#include "OLEDManager.hpp"
#include "UWBModuleActions.hpp"
#include "CANMessageManager.hpp"
#include "UWBMessageManager.hpp"
#include "InitialisationProtocol.hpp"
#include "UWBDataManager.hpp"
#include "Messages.hpp" 

// IMPORTANT : Remplacer par 0, 1, 2 ou 3 selon la carte flashée
#define MY_ANCHOR_ID 0
#define MAX_SUPPORTED_TAGS 6 

struct MemoireTag {
    bool donneeValide = false;
    std::vector<uint16_t> distances = {0, 0, 0, 0};
    int pressionPa = 0; // +1Pa = -8,3cm
};

MemoireTag memoiresDesTags[MAX_SUPPORTED_TAGS];

void setup() {
    Serial.begin(115200);
    
    initOLED(MY_ANCHOR_ID); 
    updateCANAction("DEMARRAGE", "Initialisation UWB...");

    initUWBModule(MY_ANCHOR_ID);
    initCan(ANCHOR_RX_PIN, ANCHOR_TX_PIN);

    Serial.printf("\n[SETUP] === ANCRE %d CONFIGUREE ===\n", MY_ANCHOR_ID);
    
    // --- AFFICHAGE CONFORME AUX SPÉCIFICATIONS ---
    if (MY_ANCHOR_ID == 0) {
        updateCANAction("ANCRE 0 (MASTER)", "Prete (CAN actif)");
    } else {
        updateCANAction("CAN", "En attente d'ordre du hub");
    }
}

void loop() {
    twai_message_t vCanMessage;
    DecodedData vDecodedCanData;
    String rawUWBMessage = "";
    String dernierMessageValide = "";

    // ====================================================================
    // ÉTAPE 1 : ÉCOUTE UWB (Active sur TOUTES les ancres 0, 1, 2, 3)
    // ====================================================================
    while (receiveUWBMessage(UWBSerial, rawUWBMessage, Serial)) {
        // Log direct dès qu'une trame radio arrive
        Serial.println("[ANCRE RX DIAG] Trame UWB brute détectée : " + rawUWBMessage);
        
        if (rawUWBMessage.indexOf("AT+RANGE") != -1 || rawUWBMessage.indexOf("&") != -1) {
            dernierMessageValide = rawUWBMessage; 
        }
    }

    if (dernierMessageValide != "") {
        UWBMessage decodedMsg;
        
        if (decodeUWBMessage(dernierMessageValide, decodedMsg, Serial)) {
            if (decodedMsg.aIsStandardDistanceMessage) {
                int rangeStart = dernierMessageValide.indexOf("AT+RANGE");
                
                if (rangeStart != -1) {
                    String cleanRangeMsg = dernierMessageValide.substring(rangeStart);
                    std::string stdRawMsg(cleanRangeMsg.c_str());
                    std::vector<int> parsedData = getDataFromString(stdRawMsg, "[0-9]+");
                    
                    // Log de contrôle du nombre d'entiers extraits pour les distances
                    Serial.printf("[ANCRE PARSE DIAG] Entiers trouvés par la Regex : %d (Attendu au moins %d)\n", 
                                parsedData.size(), (FIRST_TAG_DISTANCE_INDEX + 4));

                    if (parsedData.size() >= (FIRST_TAG_DISTANCE_INDEX + 4)) {
                        uint8_t tid = (uint8_t)getTagIdFromTagData(parsedData);
                        
                        if (tid < MAX_SUPPORTED_TAGS) {
                            memoiresDesTags[tid].distances.clear();
                            
                            for (int i = 0; i < 4; i++) {
                                memoiresDesTags[tid].distances.push_back((uint16_t)getDistanceFromAnchor(parsedData, i));
                            }
                            
                            // Sauvegarde
                            memoiresDesTags[tid].pressionPa = decodedMsg.pressionPa;
                            memoiresDesTags[tid].donneeValide = true;
                            
                            // --- TRACE FINALE COMPLÈTE ---
                            Serial.printf("[SUCCÈS STOCKAGE ANCRE] Tag ID: %d | Pression: %d Pa | Distances: [%d, %d, %d, %d]\n", 
                                        tid, 
                                        memoiresDesTags[tid].pressionPa,
                                        memoiresDesTags[tid].distances[0],
                                        memoiresDesTags[tid].distances[1],
                                        memoiresDesTags[tid].distances[2],
                                        memoiresDesTags[tid].distances[3]);
                            
                            updateUWBData(tid, 
                                        memoiresDesTags[tid].distances[0], 
                                        memoiresDesTags[tid].distances[1], 
                                        memoiresDesTags[tid].distances[2], 
                                        memoiresDesTags[tid].distances[3]);
                        } else {
                            Serial.printf("[ANCRE ERROR] ID Tag hors limites (%d)\n", tid);
                        }
                    } else {
                        Serial.println("[ANCRE ERROR] Structure de trame AT+RANGE incomplète, impossible de mapper les distances.");
                    }
                }
            }
        } else {
            Serial.println("[ANCRE ERROR] Échec complet du décodage par decodeUWBMessage.");
        }
        dernierMessageValide = ""; // Nettoyage
        while (UWBSerial.available()) { UWBSerial.read(); }
    }

    // ====================================================================
    // ÉTAPE 2 : GESTION DU BUS CAN (Filtrée selon le rôle de l'ancre)
    // ====================================================================
    if (receiveCanMessage(vCanMessage)) {
        Serial.println("\n\n[CAN RX] Message reçu sur le bus CAN.");
        if (decodeCanMessage(vCanMessage, vDecodedCanData)) {
            Serial.printf("[CAN RX] Type : %d, Ancre : %d, Tag : %d, Order : %d, Distance : %.2f\n", 
                          vDecodedCanData.type, 
                          vDecodedCanData.id_ancre, 
                          vDecodedCanData.id_tag, 
                          vDecodedCanData.aOrderType, 
                          vDecodedCanData.distance);
            
            // --- PROTECTION ET ROUTAGE SUR LE BUS CAN ---
            if (MY_ANCHOR_ID == 0) {
                // L'Ancre 0 exécute l'ensemble des tâches de communication avec le Hub
                
                if (vDecodedCanData.type == MESSAGE_HUB_ORDER && 
                    vDecodedCanData.id_ancre == MY_ANCHOR_ID && 
                    vDecodedCanData.aOrderType == HUB_ORDER_START_ANCHOR_INIT_POSITION_PROTOCOL) 
                {
                    Serial.println("\n[CAN RX] Ordre CAN : Lancement calibration Ancre 0");
                    updateCANAction("INIT ANCRE 0", "Calibration...");
                    runCompleteInitialisationPhase(MY_ANCHOR_ID);
                    updateCANAction("ANCRE 0 (MASTER)", "Prete (CAN actif)");
                }
                else if (vDecodedCanData.type == MESSAGE_TAG_ID_AND_DISTANCE) 
                {
                    sendDistanceToTag(UWBSerial, Serial, MY_ANCHOR_ID, vDecodedCanData.id_tag, vDecodedCanData.distance);
                    updateCANAction("TX UWB", "Alerte relayee");
                }
                else if (vDecodedCanData.type == MESSAGE_HUB_ORDER && 
                         vDecodedCanData.id_ancre == MY_ANCHOR_ID && 
                         vDecodedCanData.aOrderType == HUB_ORDER_REQUEST_DISTANCES) 
                {
                    uint8_t tagCible = vDecodedCanData.id_tag; 
                    
                    Serial.printf("\n[CAN RX] Polling -> Le Hub interroge ma memoire pour le Tag %d.\n", tagCible);
                    // Log de traçabilité : le Hub a bien fait une demande
                    
                    if (tagCible < MAX_SUPPORTED_TAGS && memoiresDesTags[tagCible].donneeValide) {
                        sendCanDistanceFromAnchorToHub(MY_ANCHOR_ID, tagCible, memoiresDesTags[tagCible].distances);
                        
                        // Log de confirmation de renvoi réussi
                        Serial.printf("[CAN TX] Succes : Distances du Tag %d expediees au Hub.\n", tagCible);
                        updateCANAction("TX CAN", "Distances OK");
                    } 
                    else {
                        // Log d'alerte critique : met en évidence si le Hub interroge le mauvais Tag (ex: 0 au lieu de 4)
                        Serial.printf("[CAN TX REFUS] Le Hub demande le Tag %d, mais ma memoire est vide ou invalide pour ce Tag !\n", tagCible);
                    }
                }
            } 
            else {
                // Les Ancres 1, 2, 3 IGNORENT les requêtes de polling ordinaires.
                // Elles ne répondent au CAN que si elles reçoivent un ordre d'initialisation global/spécifique.
                
                if (vDecodedCanData.type == MESSAGE_HUB_ORDER && 
                    vDecodedCanData.id_ancre == MY_ANCHOR_ID && 
                    vDecodedCanData.aOrderType == HUB_ORDER_START_ANCHOR_INIT_POSITION_PROTOCOL) 
                {
                    updateCANAction("INIT ANCRE", "Calibration...");
                    runCompleteInitialisationPhase(MY_ANCHOR_ID);
                    
                    // Une fois la calibration finie, on restaure le message par défaut
                    updateCANAction("CAN", "En attente d'ordre du hub");
                }
            }
        }
    }
}

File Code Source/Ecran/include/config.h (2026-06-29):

#pragma once

#include <Arduino.h>
#include <lvgl.h>

// =======================================================
// CONFIGURATION ÉCRAN & MÉTRIQUE
// =======================================================
#define SCREEN_WIDTH 800
#define SCREEN_HEIGHT 480
#define CENTRE_X (SCREEN_WIDTH / 2)
#define CENTRE_Y (SCREEN_HEIGHT / 2)
#define PIXELS_PER_METER 19.2f

#define I2C_SDA_PIN 17
#define I2C_SCL_PIN 18
#define TOUCH_INT -1
#define TOUCH_RST 38
#define TFT_BL 10
#define PIN_SD_CMD 11
#define PIN_SD_CLK 12
#define PIN_SD_D0 13

#define DRAW_BUF_SIZE (SCREEN_WIDTH * SCREEN_HEIGHT / 10)
#define MAX_TAGS 30
#define MAX_CAPTEURS 10

// =======================================================
// STRUCTURES DYNAMIQUES
// =======================================================
struct TagGraphique {
    lv_obj_t * point;
    lv_obj_t * label_id;
    lv_obj_t * label_z;
    int id_actuel;
    float distance_actuelle;
    bool en_alarme;
    bool utilise;
};

struct VehiculeConfig {
    String nom;
    String operateur;
    String date_creation;
    String fichier_image;
    float zone_metres[64][2];
    lv_point_t zone_pixels[64];
    int nb_points;
    float capteurs_metres[MAX_CAPTEURS][2];
    lv_point_t capteurs_pixels[MAX_CAPTEURS];
    int nb_capteurs;
};

// =======================================================
// VARIABLES GLOBALES (Partagées)
// =======================================================
extern TagGraphique tags_ui[MAX_TAGS];
extern lv_obj_t * visuel_capteurs[MAX_CAPTEURS];
extern VehiculeConfig liste_vehicules[20];
extern int total_vehicules;
extern int id_vehicule_actif;

extern lv_obj_t * scr_radar;
extern lv_obj_t * scr_vehicules;
extern lv_obj_t * polygone_exclusion;
extern lv_obj_t * mosaique;
extern lv_obj_t * pelleteuse;
extern lv_obj_t * cadre_alerte_global;
extern lv_obj_t * label_vide;
extern lv_obj_t * label_titre_config;

extern bool alarme_danger;
extern bool flag_recharger_ui;

extern unsigned long dernier_temps;
extern int etape_simulation;
extern volatile int calib_state;
extern unsigned long calib_timer;

extern float sim_calib_points[64][2];
extern int sim_calib_nb_capteurs;
extern float sim_calib_capteurs[MAX_CAPTEURS][2];

extern String json_tags_decouverts;

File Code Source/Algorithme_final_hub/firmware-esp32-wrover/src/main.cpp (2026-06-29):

#include "Config.hpp"
#include "HubDataStorage.hpp"
#include "GestionnaireAncres.hpp"
#include "InitAnchorPosition.hpp"
#include "CANMessageManager.hpp"
#include "RelaisBoutonBuzzer.hpp"

#include <ArduinoEigenDense.h>
#include <ArduinoJson.h>
#include <cmath>

#include "Trilateration.h"
#include "GridLibrary.hpp"
#include "Polygone.hpp"
#include "RecuperationDonneesAncres.hpp"
#include "ScreenCommunicationManager.hpp"
#include "ListeDistanceLibrary.hpp"
#include "LissagePlanExclusion.hpp"
#include "CalibrationManager.hpp"

//#define DEBUG_POSITION

// --- VARIABLES GLOBALES ---
RecuperationDonneesAncres recupDonnees;
UWBModuleList vAnchors;
Polygone vSafeZone;
CalibrationManager calibManager;

// Dictionnaire pour retenir la hauteur (Z) des ancres avant que l'écran ne valide le X et Y
std::map<int, float> hauteursAncresTemporaires;

#define HAUTEUR_MAX_TAG_METRES 5.0f

#define TAG_CIBLE 4 // ID du tag que l'on souhaite suivre en temps réel (pour le polling du Hub)
#define ANCRE_MASTER 0

extern bool aDesDistancesManuelles;

// Prototypes
void afficherCoordonneesAncres();
void afficherCoordonneesTag(uint8_t tagId, const V3& pos3D);
void clearSerialMonitor();

/**
 * @brief Efface l'écran du moniteur série et replace le curseur en haut à gauche.
 * Note : Fonctionne parfaitement avec le moniteur de PlatformIO.
 */
void clearSerialMonitor() {
    // \033[2J : Code ANSI pour effacer tout l'écran
    // \033[H  : Code ANSI pour ramener le curseur à la position d'origine (0,0)
    Serial.print("\033[2J\033[H");
}

/**
 * @brief Fonction vitale pour le réseau CAN.
 * Doit être appelée à chaque cycle de loop() pour vider le buffer matériel TWAI
 * et injecter les distances reçues des ancres dans l'accumulateur.
 */
void ecouterReseauFilaire() {
    twai_message_t messageRecu;
   
    while (receiveCanMessage(messageRecu)) {
        DecodedData donnees;

        digitalWrite(2, LOW);
       
        if (decodeCanMessage(messageRecu, donnees)) {
            if (donnees.type == MESSAGE_TAG_ID_AND_ALL_DISTANCES) {
                if (donnees.aDistances.size() >= 4) {
                    
                    // --- NOUVEAU LOG : Réception des distances depuis l'Ancre ---
                    Serial.printf("[HUB CAN RX] Distances du Tag %d recues via Ancre %d : [%d, %d, %d, %d]\n", 
                                  donnees.id_tag, donnees.id_ancre,
                                  donnees.aDistances[0], donnees.aDistances[1],
                                  donnees.aDistances[2], donnees.aDistances[3]);

                    recupDonnees.injecterDonnee(donnees.id_tag,
                                                donnees.aDistances[0],
                                                donnees.aDistances[1],
                                                donnees.aDistances[2],
                                                donnees.aDistances[3]);
                }
            }
        }
    }
}

V3 getCoordonnesTag(uint8_t tagCible) {
    V3 pos3D(0, 0, 0); // Position de sécurité par défaut si l'ancre ne répond pas

    // 1. PURGE DU BUFFER CAN
    // On nettoie la file d'attente pour ne pas s'appuyer sur une ancienne trame par erreur
    twai_message_t vMessage;
    while(receiveCanMessage(vMessage)) { /* Vidage silencieux */ }

    // 2. ENVOI DE LA REQUÊTE
    Serial.printf("[HUB SYNC] Requête immédiate des distances pour le Tag %d à l'Ancre %d...\n", tagCible, ANCRE_MASTER);
    sendCanRequestDistances(ANCRE_MASTER, tagCible);

    // 3. ATTENTE ACTIVE (Bloquante avec Timeout de 150 ms)
    unsigned long startWait = millis();
    bool responseReceived = false;
    DecodedData donnees;

    while (millis() - startWait < 150) {
        if (receiveCanMessage(vMessage)) {
            if (decodeCanMessage(vMessage, donnees)) {
                
                // On s'assure d'intercepter la bonne réponse pour le bon tag
                if (donnees.type == MESSAGE_TAG_ID_AND_ALL_DISTANCES && donnees.id_tag == tagCible) {
                    responseReceived = true;
                    break; // On a notre tableau de distances, on sort immédiatement de la boucle !
                }
            }
        }
        delay(2); // Évite de faire surchauffer le processeur pendant l'écoute
    }

    // 4. TRAITEMENT MATHÉMATIQUE SI RÉPONSE REÇUE
    if (responseReceived && donnees.aDistances.size() >= 4) {
        Serial.printf("[HUB DATA] Distances reçues en direct : [%d, %d, %d, %d] cm\n", 
                      donnees.aDistances[0], donnees.aDistances[1], donnees.aDistances[2], donnees.aDistances[3]);

        std::vector<int> aIds = vAnchors.giveModuleIdList();
        std::unordered_map<int, float> distMap;
        
        Serial.println("[HUB TRILAT] On va rentrer des valeur dans DISTMAP qui vient d'être créé : ");

        // Conversion en mètres pour la bibliothèque géométrique
        for(int i = 0; i < 4 && i < aIds.size(); i++) {
            distMap[aIds[i]] = donnees.aDistances[i] / 100.0f; 
        }

        Serial.printf("[HUB TRILAT] Distances contenues dans le DISTMAP : [%.2f, %.2f, %.2f, %.2f] mètres\n", 
                      distMap[0], distMap[1], distMap[2], distMap[3]);

        // Exécution de l'algorithme de trilatération
        //Serial.println("[HUB TRILAT] vAnchors avant trilatération : " + vAnchors.toString().c_str());
        initMatrixA(vAnchors);
        pos3D = trilateration3D(vAnchors, distMap);
        Serial.println("[HUB TRILAT] Position calculée du Tag " + String(tagCible) + " : " + String(pos3D.toString().c_str()));
        afficherCoordonneesTag(TAG_CIBLE, pos3D);
        
        /* Contrôle de validité mathématique
        if (std::isnan(pos3D.getX()) || std::abs(pos3D.getZ()) > HAUTEUR_MAX_TAG_METRES) {
            Serial.println("[HUB TRILAT] Singularité mathématique (NaN) ou hors zone. Retour à l'origine.");
            afficherCoordonneesAncres();
            return V3(0, 0, 0);
        }*/

    } else {
        Serial.printf("[HUB DATA] Echec (Timeout) : Aucune réponse de l'ancre %d dans le temps imparti.\n", ANCRE_MASTER);
    }
    return pos3D;
    
}

float getDistanceToEpicentreFromTag(V3 pos3D){
    return std::sqrt(pos3D.getX() * pos3D.getX() + pos3D.getY() * pos3D.getY());
}

/**
 * Recupere la distance du tag cible et l'envoie à l'application
 * Des que l'utilisateur aura selectionne le tag, l'applicatino enverra une commande qui executera HUB_COLLECTING_POINT avec le bon tag
*/
void AskUserForTag() {
    Serial.println("Recupération de la distance à l'épicentre du tag cible pour l'etalonnage");
    
    V3 tag4_position = getCoordonnesTag(TAG_CIBLE);

    int ids[1] = {TAG_CIBLE};
    float distances[1] = {getDistanceToEpicentreFromTag(tag4_position)};
    int count = 1;
    envoyerListeTagsDecouverts(ids, distances, count);
    Serial.println("Distance envoyée à l'appplication");
    etatActuelHub = HUB_STATE_IDLE;
}
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

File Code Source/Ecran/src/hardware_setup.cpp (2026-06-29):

#include "hardware_setup.h"
#include "config.h"
#include <Arduino_GFX_Library.h>
#include <TAMC_GT911.h>
#include <Wire.h>
#include <SD_MMC.h>

Arduino_ESP32RGBPanel *bus = new Arduino_ESP32RGBPanel(
    GFX_NOT_DEFINED, GFX_NOT_DEFINED, GFX_NOT_DEFINED,
    40, 41, 39, 42, 45, 48, 47, 21, 14,
    5, 6, 7, 15, 16, 4, 8, 3, 46, 9, 1
);

Arduino_RPi_DPI_RGBPanel *gfx = new Arduino_RPi_DPI_RGBPanel(
    bus, SCREEN_WIDTH, 1, 40, 48, 128, SCREEN_HEIGHT, 1, 13, 3, 45
);

TAMC_GT911 ts = TAMC_GT911(I2C_SDA_PIN, I2C_SCL_PIN, TOUCH_INT, TOUCH_RST, 1024, 600);

lv_color_t *draw_buf;
lv_color_t *draw_buf2;

void my_disp_flush(lv_disp_drv_t *disp, const lv_area_t *area, lv_color_t *color_p) {
    uint32_t w = (area->x2 - area->x1 + 1);
    uint32_t h = (area->y2 - area->y1 + 1);
    gfx->draw16bitRGBBitmap(area->x1, area->y1, (uint16_t *)color_p, w, h);
    lv_disp_flush_ready(disp);
}

void touchscreen_read(lv_indev_drv_t * indev, lv_indev_data_t * data) {
    ts.read();
    if (ts.isTouched) {
        data->state = LV_INDEV_STATE_PR;
        int mapped_x = map(ts.points[0].x, 1024, 200, 0, SCREEN_WIDTH);
        int mapped_y = map(ts.points[0].y, 600, 120, 0, SCREEN_HEIGHT);
        if(mapped_x < 0) mapped_x = 0; if(mapped_x > SCREEN_WIDTH - 1) mapped_x = SCREEN_WIDTH - 1;
        if(mapped_y < 0) mapped_y = 0; if(mapped_y > SCREEN_HEIGHT - 1) mapped_y = SCREEN_HEIGHT - 1;
        data->point.x = mapped_x; data->point.y = mapped_y;
        ts.isTouched = false;
    } else {
        data->state = LV_INDEV_STATE_REL;
    }
}

void setup_hardware_basic() {
    gfx->begin();
    pinMode(TFT_BL, OUTPUT); pinMode(TOUCH_RST, OUTPUT);
    digitalWrite(TFT_BL, LOW); delay(100);
    digitalWrite(TOUCH_RST, LOW); delay(1000); digitalWrite(TOUCH_RST, HIGH); delay(1000);
    digitalWrite(TOUCH_RST, LOW); delay(1000); digitalWrite(TOUCH_RST, HIGH); delay(1000);

    Wire.begin(I2C_SDA_PIN, I2C_SCL_PIN);
    ts.begin(); ts.setRotation(ROTATION_NORMAL);

    SD_MMC.setPins(PIN_SD_CLK, PIN_SD_CMD, PIN_SD_D0);

    for (int tentatives = 5; tentatives > 0; tentatives--) {
        if (SD_MMC.begin("/sdcard", true)) {
            break;
        }
        delay(500);
    }
    if (!SD_MMC.begin("/sdcard", true)) Serial.println("Erreur SD");
}

void setup_hardware_lvgl() {
    draw_buf = (lv_color_t *)heap_caps_malloc(DRAW_BUF_SIZE * sizeof(lv_color_t), MALLOC_CAP_INTERNAL | MALLOC_CAP_8BIT);
    draw_buf2 = (lv_color_t *)heap_caps_malloc(DRAW_BUF_SIZE * sizeof(lv_color_t), MALLOC_CAP_INTERNAL | MALLOC_CAP_8BIT);
    if (!draw_buf) draw_buf = (lv_color_t *)heap_caps_malloc(DRAW_BUF_SIZE * sizeof(lv_color_t), MALLOC_CAP_SPIRAM | MALLOC_CAP_8BIT);
    if (!draw_buf2) draw_buf2 = (lv_color_t *)heap_caps_malloc(DRAW_BUF_SIZE * sizeof(lv_color_t), MALLOC_CAP_SPIRAM | MALLOC_CAP_8BIT);

    static lv_disp_draw_buf_t disp_buf;
    lv_disp_draw_buf_init(&disp_buf, draw_buf, draw_buf2, DRAW_BUF_SIZE);

    static lv_disp_drv_t disp_drv; lv_disp_drv_init(&disp_drv);
    disp_drv.hor_res = SCREEN_WIDTH; disp_drv.ver_res = SCREEN_HEIGHT;
    disp_drv.flush_cb = my_disp_flush; disp_drv.draw_buf = &disp_buf;
    lv_disp_drv_register(&disp_drv);

    static lv_indev_drv_t indev_drv; lv_indev_drv_init(&indev_drv);
    indev_drv.type = LV_INDEV_TYPE_POINTER; indev_drv.read_cb = touchscreen_read; lv_indev_drv_register(&indev_drv);
}

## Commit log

2026-05-21 Ajout des fichiers pour repère
    Création des fichiers Grid.cpp et Grid.h pour gérer le repère virtuel où seront positionnés les capteurs et les tags.
2026-05-21 Création attributs + constructeurs grille
    Création des premiers attributs de la classe Grid et écriture de son constructeur.
2026-05-21 Création et modifications de classes
    Création des classes GridItem et de la classe fille UWBSensor, et modification de la classe Grid.
2026-05-22 Suppression Grid + création V3
    Suppression de la classe Grid qui n'avait finalement aucune utilité, et création de la classe V3 pour gérer les vecteurs dans un espace en 3 dimensions.
2026-05-26 Remaniement fichiers + modification de classes
    Suppression des fichiers UWBSensor.*, modification du contenu de toutes les classes.
2026-05-27 Implémentation algorithme trilatération v1
    Création des fichiers Trilateration.* et implémentation de l'algorithme de trilatération version 1. Création du fichier de test main_test.cpp.
2026-05-27 Implémentation de main_test.cpp
    Implémentation du premier test dans main_test.cpp pour la librairie Trilateration.h.
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2026-05-27 Refractoring de UWBModule et UWBModuleList
    Changement des identifiants des modules (avant : string aName, après : int aId), et changement de structure de données dans la classe UWBModuleList (aUWBModuleList est passé du type unordered_map<str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
2026-05-27 Test d'affichage de distance entre ancre et tag sur PlatformIO
    Normalement il suffit de téléverser chaque projet PlatformIO dans une carte MaUWB en la branchant sur le port USB-native. Puis, d'appuyer sur Rst.
2026-05-29 Débogage code 1 ancre + 1 tag
    Correction des problèmes de communication entre 1 ancre et 1 tag. Le programme affiche sur les écrans des 2 cartes la distance qui les sépare.
    [main.cpp]
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2026-05-29 Création code Multi-Ancre + Multi-Tag
    Création d'un dossier gérant la communication entre 3 ancres et 2 tags.
2026-05-29 Implémentation librairie UWBDataManager
    Implémentation d'une librairie pour pouvoir extraire les distances entre tag - ancre et les id des tags qui envoient des données aux ancres.
2026-05-29 Modification librairie UWBDataManager
    Implémentation des 2 fonctions getDistanceFromAnchor et getTagIdFromTagData, et modifications des macros regex.
2026-06-01 Mis à jour inclusion librairies Trilatération
    Déplacement d'include de Trilateration.cpp à Trilateration.h, et suppression d'autres include
2026-06-01 Ajout deuxième algorithme trilatération
    Implémentation de l'algorithme de trilatération utilisant les mesures des baromètres et seulement 3 capteurs UWB.
2026-06-01 Création projet gestion hub
    Création du projet avec le code principal du hub, alias l'ESP32 WROVER.
2026-06-02 Ajout altitude, correction fonction suppression de configuration
    [main.cpp]
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2026-06-02 Correction historique calibrage + Ajout titre de la machine sur l'écran
    [main.cpp]
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2026-06-03 Modification de la classe Polygone + V3
    Correction de la fonction de calcul de distance et ajout de fonctions dans V3 pour la norme et le produit scalaire en 2D.
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2026-06-03 Ajout fonction pour positionner les capteurs sur le véhicuel virtuellement, fix de bugs
    [main.cpp]
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2026-06-04 custom buzzer on PWM
    working from serial monitor
    [main.cpp]
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2026-06-04 Projet KiCad ouvrier
    [Ouvrier.kicad_pcb, Ouvrier.kicad_sch]
2026-06-04 projet KiCad Anre
    [Ancre.kicad_pcb, Ancre.kicad_sch]
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2026-06-04 MaJ PCB ancre pistes
    [Ancre.kicad_pcb, Ancre.kicad_sch]
2026-06-04 MaJ KiCad ouvrier bibliotheque
    [Ouvrier.kicad_sch]
2026-06-04 MaJ KiCad Ouvrier Xiao DIP et bibliotheque
    [Ouvrier.kicad_pcb, Ouvrier.kicad_sch]
2026-06-04 MaJ KiCad ouvrier BMP581
    [Ouvrier.kicad_sch]
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2026-06-05 Ajout TCAN bornier bibliotheque
    [Ancre.kicad_pcb, Ancre.kicad_sch]
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2026-06-05 MaJ PCB Ancre
    [Ancre.kicad_pcb]
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2026-06-05 MaJ batterie KiCad Ouvrier
    [Ouvrier.kicad_pcb, Ouvrier.kicad_sch]
2026-06-05 MaJ batterie Ouvrier
    [Ouvrier.kicad_pcb, Ouvrier.kicad_sch]
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2026-06-05 finalisation PCB ancre
    [Ancre.kicad_pcb, Ancre.kicad_sch]
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2026-06-05 Test BMP
    [Test BMP.kicad_pcb, Test BMP.kicad_sch]
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2026-06-08 ancre quasi fini
    [Ancre.kicad_pcb]
2026-06-08 nouvelle ancre pas fini
    [Ancre.kicad_sch, Test BMP.kicad_pcb]
2026-06-08 ancre fini ?
    [Ancre.kicad_pcb, Ancre.kicad_sch]
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2026-06-08 Generation gbr TEST
    [Test BMP-B_Cu.gbr, Test BMP-Edge_Cuts.gbr, Test BMP-F_Cu.gbr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]
2026-06-08 batterie et Induction
    [Ouvrier.kicad_pcb, Ouvrier.kicad_sch]
2026-06-08 GBR ANCRE
    [Ancre-B_Cu.gbr, Ancre-Edge_Cuts.gbr, Ancre-F_Cu.gbr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]
2026-06-08 led ouvrier kicad
    [Ouvrier.kicad_pcb, Ouvrier.kicad_sch]
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2026-06-10 Correction du script de test de Visualisation 3D
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2026-06-10 Update Test BMP.kicad_pcb
    [Test BMP.kicad_pcb]
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2026-06-11 changement transistor 2N2222 (empreinte)
    [HUB2.kicad_pcb, HUB2.kicad_sch]
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2026-06-11 MaJ composants Hub empreinte et schematic
    [HUB2.kicad_pcb, HUB2.kicad_sch]
2026-06-11 rennomage Hub KiCad
    [Hub.kicad_pcb, Hub.kicad_sch]
2026-06-11 Fin rennommage Hub
    [Hub.kicad_sch]
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2026-06-12 MaJ Hub nouvelle version relais-bouton-alim
    [Hub.kicad_sch]
2026-06-12 MaJ visuelle schematic Hub KiCad
    [Hub.kicad_sch]
2026-06-12 MaJ Tx-Rx TCAN Hub KiCad
    [Hub.kicad_sch]
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2026-06-12 Validation sch HUB OUVRIER
    [Hub.kicad_sch, Ouvrier.kicad_sch]
2026-06-12 Correction extraction de donnée de la Flash du Hub
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2026-06-12 connected INT pins BMI088 KiCad Hub
    [Hub.kicad_pcb, Hub.kicad_sch]
2026-06-12 Pin INT BMPA581 connecté KiCad Hub
    [Hub.kicad_pcb, Hub.kicad_sch]
2026-06-12 MaJ KiCad Ouvrier
    pin INT BMP et raccord batterie
    [Ouvrier.kicad_pcb, Ouvrier.kicad_sch]
2026-06-12 MaJ KiCad Ouvrier (aucun changement)
    [Ouvrier.kicad_pcb]
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2026-06-15 Creation Fichier Drill Ouvrier HUB
    [HUB2-B_Cu.gbr, HUB2-F_Cu.gbr, HUB2-PTH.drl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]
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2026-06-16 Mesure IMU : utilisation d'un timer hardware pour optimiser le coeur 0
    en fait la mesure puis calcule avec le filtre de Madgwick ne prend que 90µs (au pire 670 au démarrage), or ça sert à rien qu'il s'exécute à plus de 400Hz (pcq la plupart de vibrations hautes frequences sont déjà filtré par l'engin lui même et par un filtre passe bas de Madwick (145Hz max)).
    Donc comme ça, toutes les 2,5ms (400HZ), la valeur du vecteur gravité est mise à jour en mutex rapidement puis la tache est freeze pour laisser p=les autre taches s'executer peu importe leur priorité.
    [gravity_IMU.cpp]
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2026-06-17 Fix problème include, New récupération des données sur 30s
    [main.cpp]
2026-06-17 Meilleure séparation entre Gestion des Ancres et WifiManager, correction bugs
    [main.cpp]
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2026-06-18 Corrections bugs = prières
    [hub_com.cpp, main.cpp]
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2026-06-18 Clear automatique avec manque d'infos, corrections bugs
    [hub_com.cpp, main.cpp, web_server_api.cpp]
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2026-06-18 capteur mort c'est pas le code le probleme
    [hub.step]
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2026-06-19 Correction : tag envoyé
    [web_server_api.cpp]
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2026-06-19 Changement étirement lors de correction, déplacement des points
    [main.cpp]
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2026-06-19 Correction platformio.ini pour compiler (fonctionne toujours pas)
    [main.cpp]
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2026-06-19 Correction communication UWB + ouvrier
    [main.cpp]
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2026-06-20 correction bouton PCB Kicad
    [Hub.kicad_pcb, Hub.kicad_sch]
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2026-06-21 Correction CAN main hub
    [main.cpp]
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2026-06-23 Fix ecran, chgmts noms variables
    [main.cpp]
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2026-06-23 COde de lecture coté ancre fixé
    parsing At range amélioré coté ancre
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2026-06-24 fix getCoordonnee fonction bloquante
    [main.cpp]
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2026-06-24 Relais Buzzer Bouton Library
    [main.cpp]
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
